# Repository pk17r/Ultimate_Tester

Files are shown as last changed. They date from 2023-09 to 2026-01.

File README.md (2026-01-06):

# Ultimate Tester!

Pocket Sized Component Tester + Variable Power Source + Accurate Power Monitor in Arduino Uno Form Factor

Full Blog Entry & Details:
https://pk17r.wordpress.com/2023/12/18/ultimate-tester-component-tester-lipo-charge-boost-protect/

Updated Ultimate Tester Schematics: https://github.com/pk17r/Ultimate_Tester/blob/prash/ComponentTester-1.54m/UltimateTester_PCB/UltimateTester_v1_with_mods.pdf

<br>

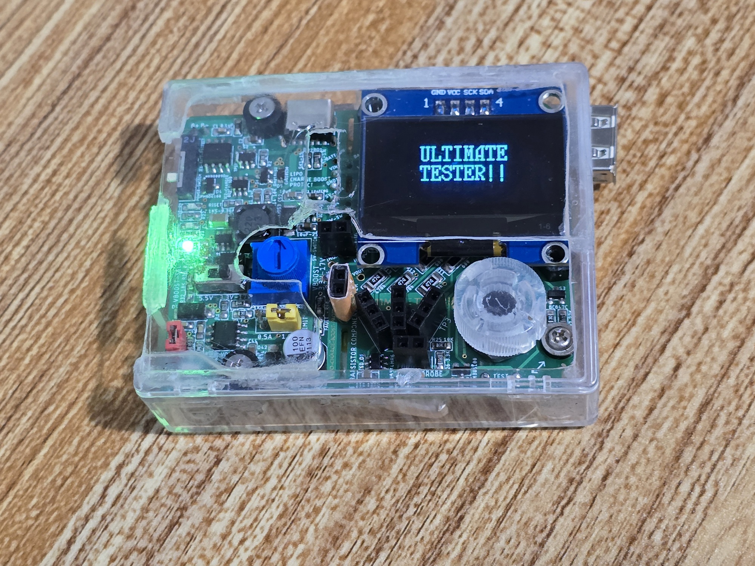
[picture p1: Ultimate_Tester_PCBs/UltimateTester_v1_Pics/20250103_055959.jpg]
Component Tester + Power Supply and Power Monitor


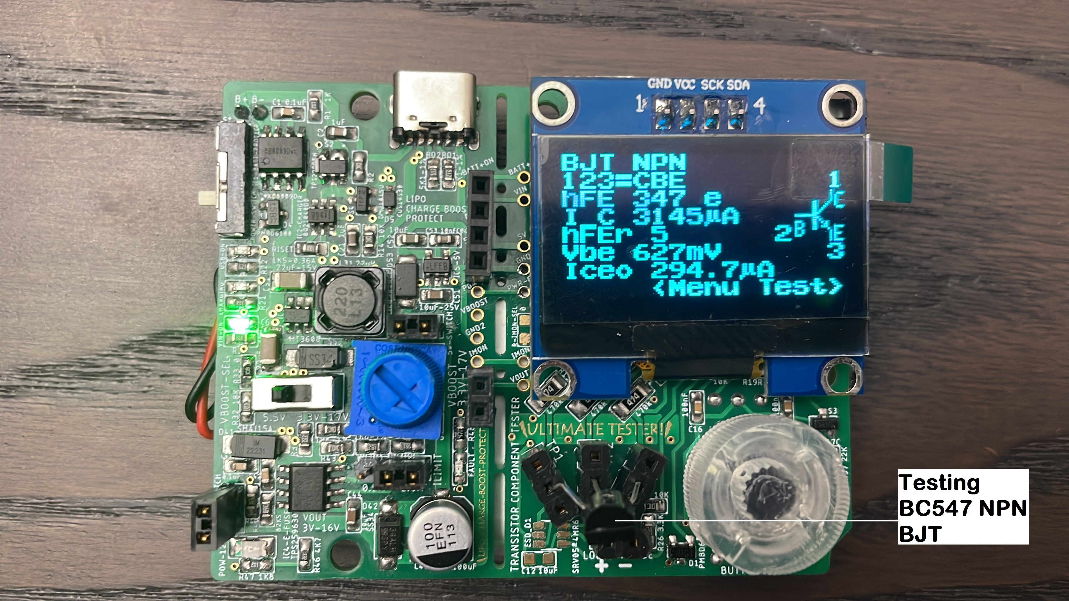
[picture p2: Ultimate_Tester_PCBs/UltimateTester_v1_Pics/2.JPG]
Component Tester


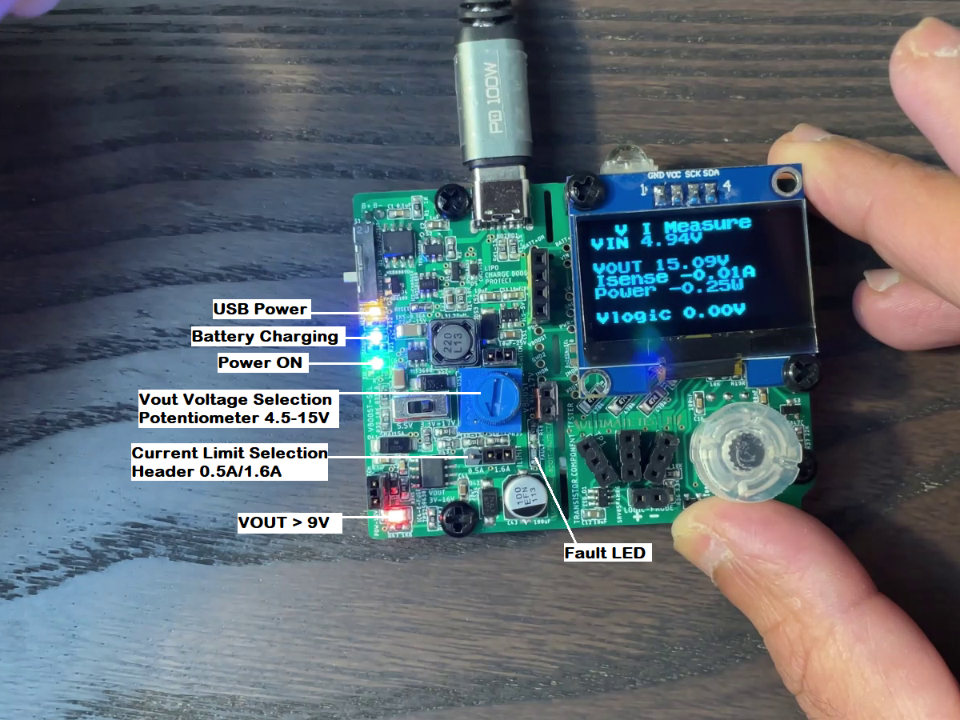
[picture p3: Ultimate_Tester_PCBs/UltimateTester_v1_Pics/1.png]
LiPo Charge Boost Protect / USB-C Power Supply


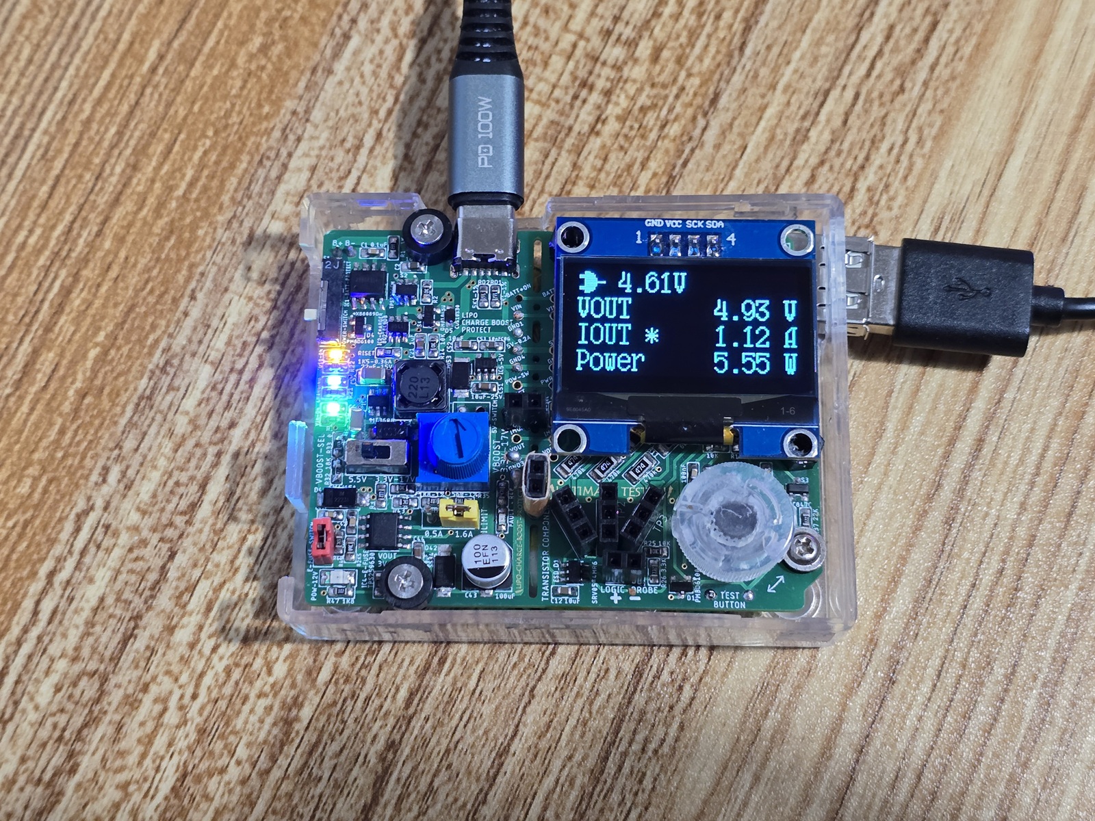
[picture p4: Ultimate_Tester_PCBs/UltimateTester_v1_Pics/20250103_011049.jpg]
Accurate INA226 Power Monitor with External Power Supply


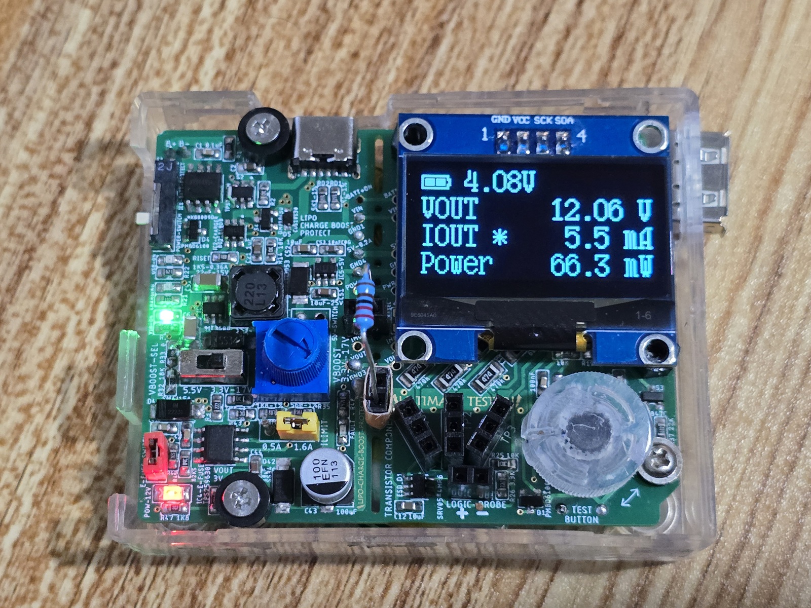
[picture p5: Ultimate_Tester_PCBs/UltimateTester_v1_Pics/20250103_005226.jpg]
Accurate INA226 Power Monitor with Internal Power Supply


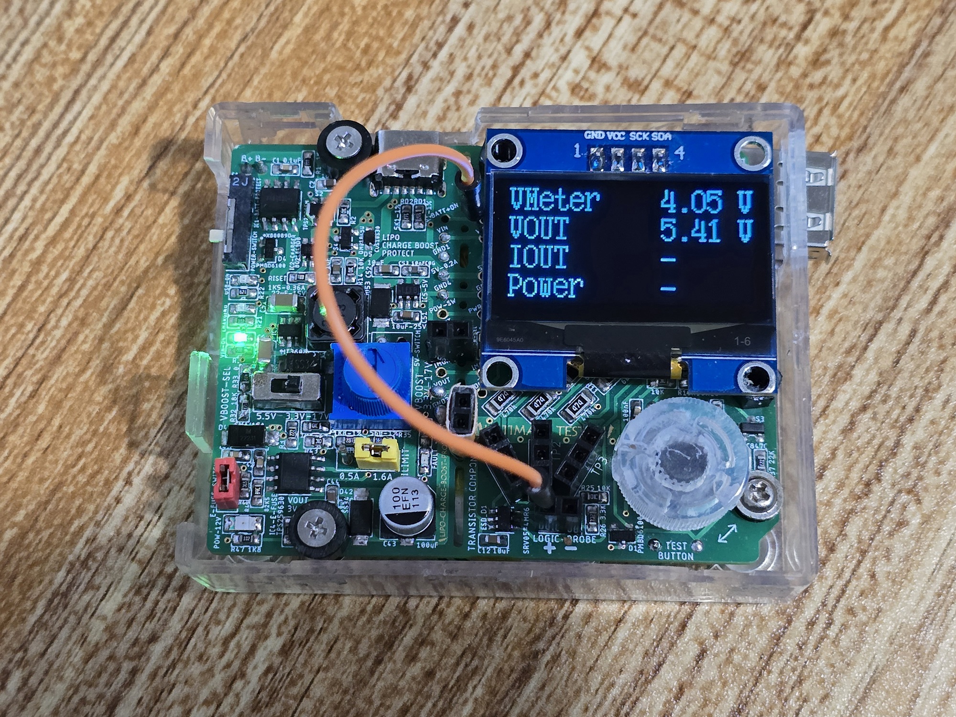
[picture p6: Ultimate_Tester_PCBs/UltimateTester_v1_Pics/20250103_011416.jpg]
Accurate INA226 Power Monitor along with Voltmeter


Current Accuracy:<br>
Test 1: Low Current: 2.4mA<br>
<table>
  <tr>
    <th></th>
    <th>Measured</th>
    <th>Ground Truth</th>
    <th>Error</th>
  </tr>
  <tr>
    <td>Current</td>
    <td>2.4mA</td>
    <td>2.39+0.6%=2.40mA</td>
    <td>0%</td>
  </tr>
  <tr>
    <td>Voltage</td>
    <td>5.17V</td>
    <td>5.164+0.1%=5.17V</td>
    <td>0%</td>
  </tr>
</table>

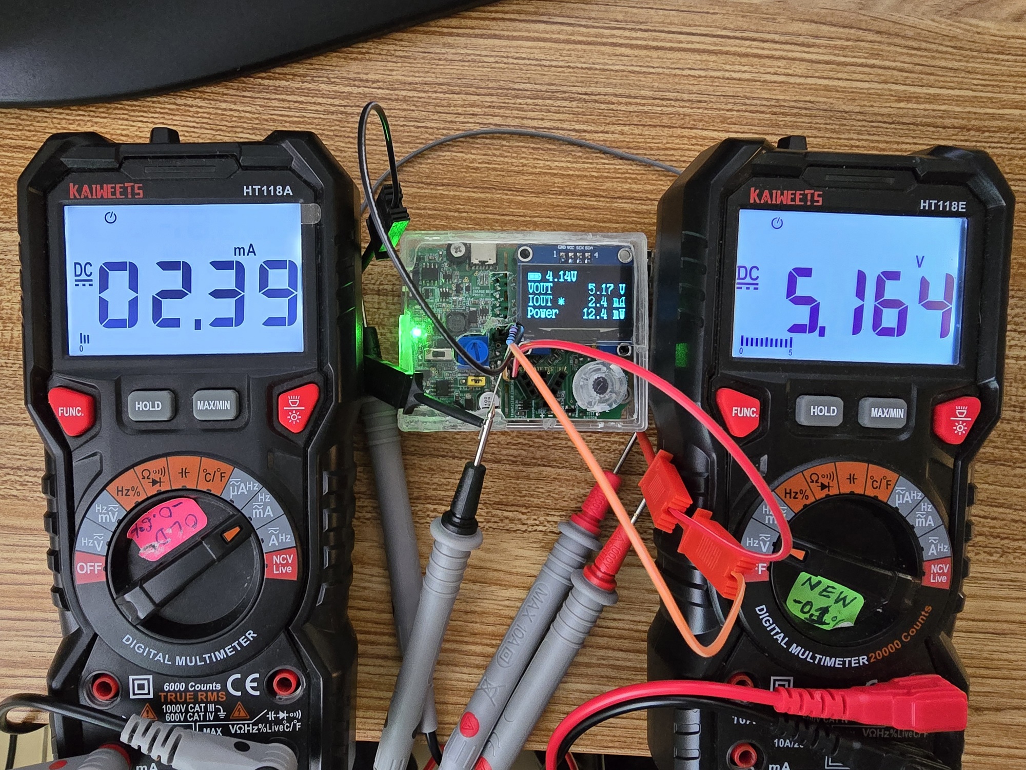
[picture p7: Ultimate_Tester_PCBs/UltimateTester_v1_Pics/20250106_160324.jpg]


Test 2: Medium Current: 209.3mA<br>
<table>
  <tr>
    <th></th>
    <th>Measured</th>
    <th>Ground Truth</th>
    <th>Error</th>
  </tr>
  <tr>
    <td>Current</td>
    <td>209.3mA</td>
    <td>207.3+0.6%=208.5mA</td>
    <td>+0.4%</td>
  </tr>
  <tr>
    <td>Voltage</td>
    <td>5.14V</td>
    <td>5.135+0.1%=5.14V</td>
    <td>0%</td>
  </tr>
</table>

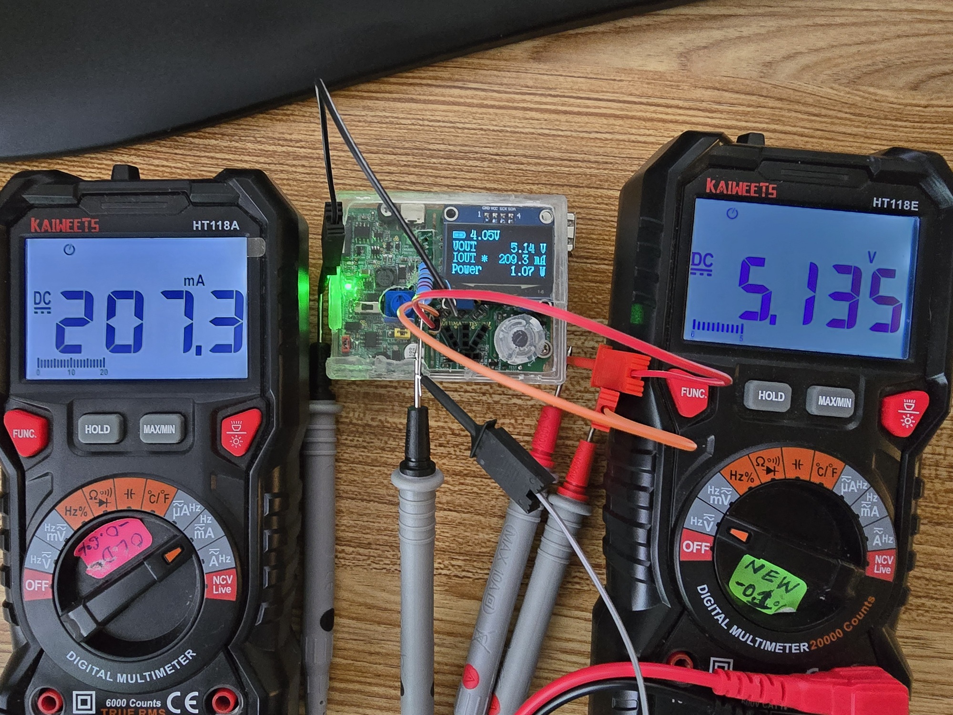
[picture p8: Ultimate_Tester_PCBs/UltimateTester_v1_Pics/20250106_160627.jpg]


Test 3: High Current: 1.07A<br>
<table>
  <tr>
    <th></th>
    <th>Measured</th>
    <th>Ground Truth</th>
    <th>Error</th>
  </tr>
  <tr><td>Current</td><td>1.07mA</td><td>1.056+0.6%=1.06A</td><td>+0.9%</td></tr>
  <tr><td>Voltage</td><td>4.95V </td><td>4.928+0.1%=4.93V</td><td>+0.4%</td></tr>
</table>

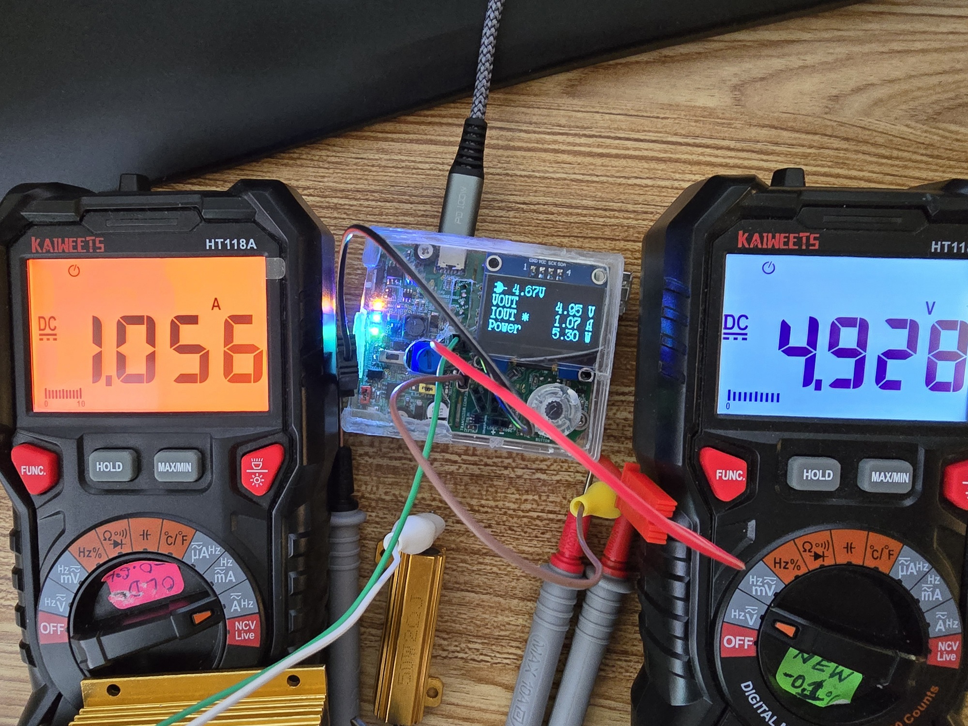
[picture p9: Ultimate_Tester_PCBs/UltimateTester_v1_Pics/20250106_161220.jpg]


Test 4: Different Voltages<br>
<table>
  <tr>
    <th>Measured</th>
    <th>Ground Truth</th>
    <th>Error</th>
  </tr>
  <tr><td>3.93V</td><td>  3.930+0.1%=3.93V</td><td>    0%</td></tr>
  <tr><td>9.05V</td><td>  9.051+0.1%=9.02V</td><td>   +0.3%</td></tr>
  <tr><td>12.04V</td><td>12.022+0.1%=12.03V</td><td>+0.1%</td></tr>
  <tr><td>15.15V</td><td>15.136+0.1%=15.15V</td><td>0%</td></tr>
</table>

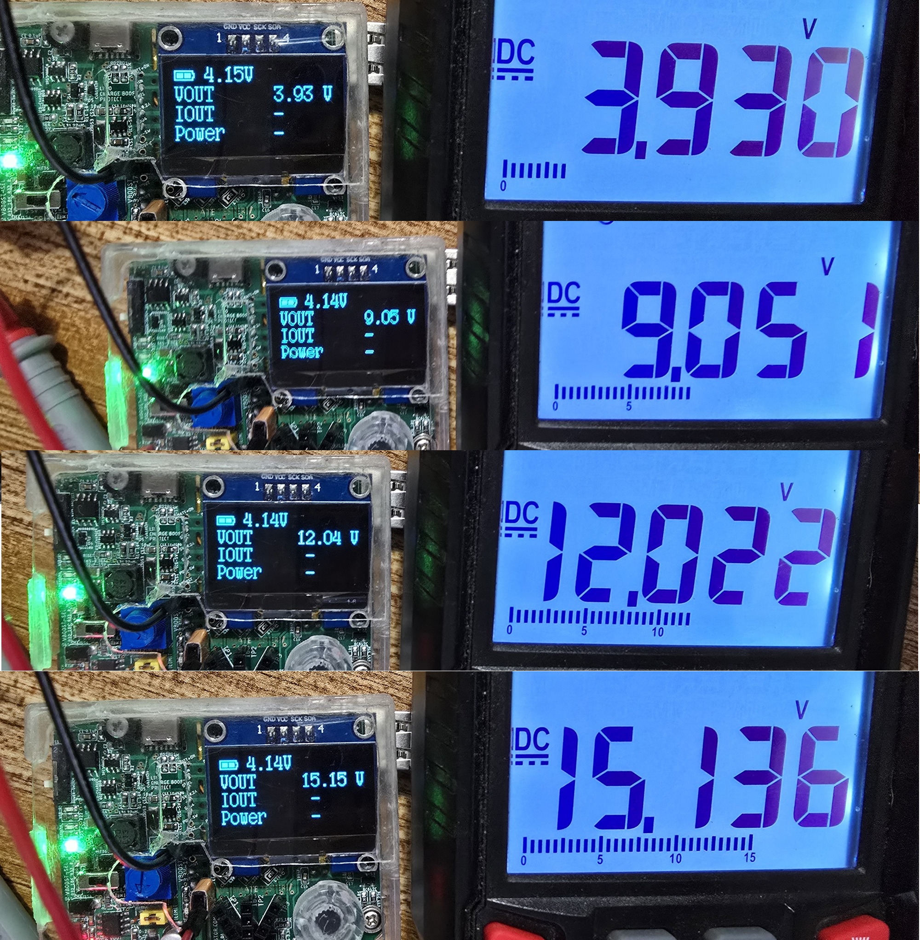
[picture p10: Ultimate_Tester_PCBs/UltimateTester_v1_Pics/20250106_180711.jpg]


<br>

# Transistortester Warehouse

The Transistortester is a device for identifying and checking electronic components.
It also offers additional functionality like a PWM signal generator for example.
And it's OSHW.

This repo is meant to provide a convenient way to download firmware packages,
documentation files, PCB files and more. Therefore it's structured differently
from the main repo.

The project's webpage is https://www.mikrocontroller.net/articles/AVR_Transistortester
and the main repo is https://github.com/kubi48/TransistorTester-source.

BTW, all the inexpensive Transistortesters sold on your favourite shopping platform
are based on this project and can be updated with the original OSHW firmware versions.

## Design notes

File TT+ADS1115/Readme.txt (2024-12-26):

A stripped down version of the ORIGINAL Markus Frejek's code.
ATTENTION : this is NOT a fully working code.

Uses ADS1115 as ADC instead of internal one.
tested in PROTEUS OKK

* some measurement are omitted:
	- resistance. 
	- capacitance.
	- base-emitter voltage for bipolar transistors. 
	- gate capacitance for enhancement MOSFETS. 

* No automatic shut OFF
* No custom chars.
* No battery test.
* The watchdog is not used to reset the chip when the program hangs.

The file tt.hex is the Flash. 
The file eep.bin is the EEPROM contents. Please do not forget this in simulation and real device !

ATMEGA328 @ 8MHz (internal RC oscillator).

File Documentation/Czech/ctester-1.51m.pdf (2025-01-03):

? =

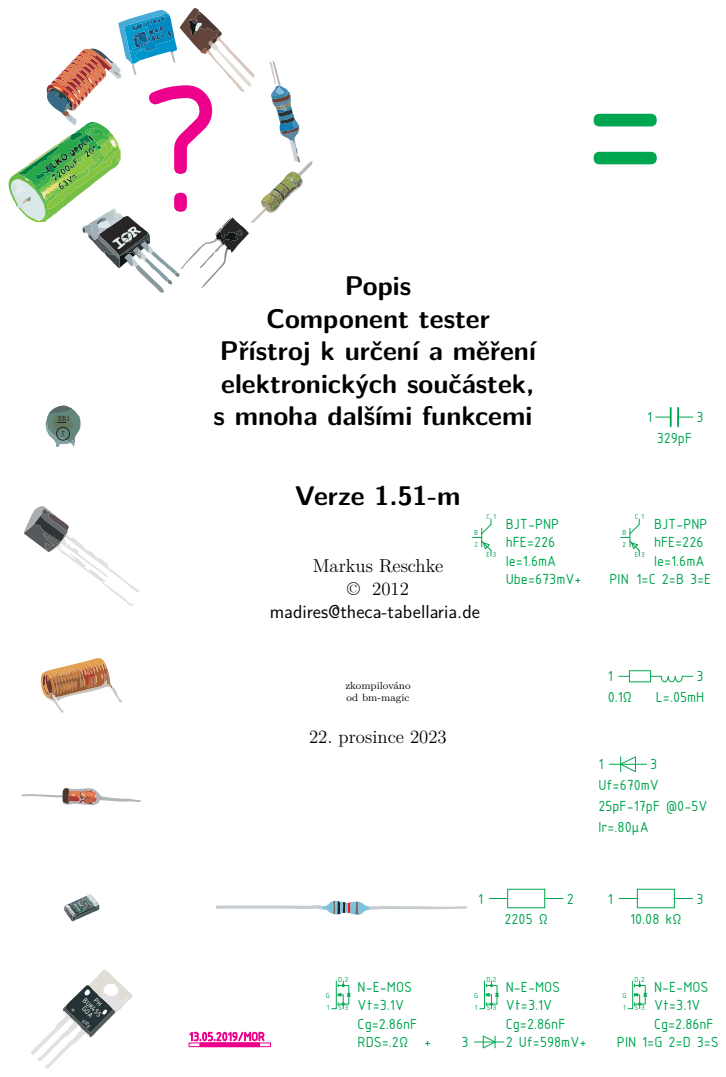
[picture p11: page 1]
13.05.2019/MOR; N-E-MOS Vt=3.1V Cg=2.86nF; RDS=.2; BJT-PNP hFE=226 Ie=1.6mA Ube=673mV+; BJT-PNP hFE=226 Ie=1.6mA PIN 1=C 2=B 3=E; N-E-MOS Vt=3.1V Cg=2.86nF PIN 1=G 2=D 3=S; S3 BUK455; PH GOA; Popis; Verze 1.51-m; Markus Reschke © 2012

Component tester
Přístroj k určení a měření
elektronických součástek,
s mnoha dalšími funkcemi

madires@theca-tabellaria.de

zkompilováno
od bm-magic
22. prosince 2023

## Obsah

1 O tomto Ctesteru | 8
1.1 Úvod | | 8
1.2 Bezpečnost | | 8
1.3 Licence | | 8
1.3.1 | Dostatečné licenční upozornění | | 8
1.4 Rozdíly ke k-verzi | | 9
1.5 Zdrojový kód | | 9
1.6 Podporovaná hardware | | 10
1.7 Podporovaní hardwardwerové možnosti | | 10
1.7.1 | Obsluha | | 10
1.7.2 | Vylepšení | | 10
1.7.3 | Doplňkové zkoušky a měření | | 10
1.8 Úprava zdrojového kódu | | 10
2 Hardware | | 11
2.1 Hardwarové možnosti | | 11
2.2 A samozřejmě softwarové možnosti | | 11
2.3 Dostupné jazyky | | 12
2.4 Konfigurace | | 12
2.5 Sběrnice & rozhraní | | 12
2.5.1 | I2C/SPI | | 12
2.5.2 | Serielní TTL Interface | | 12
2.5.3 | One Wire | | 13
2.6 LCD moduly | | 13
2.6.1 | Znakové sady a symboly | | 14
2.6.2 | HD44780 | | 14
2.6.3 | ILI9163 | | 14
2.6.4 | ILI9341/ILI9342 | | 15
2.6.5 | ILI9481 | | 16
2.6.6 | ILI9486 | | 16
2.6.7 | ILI9488 | | 16
2.6.8 | PCD8544 | | 17
2.6.9 | PCF8814 | | 17
2.6.10 SH1106 | | 17
2.6.11 SSD1306 | | 18
2.6.12 ST7036 | | 18
2.6.13 ST7565R | | 19
2.6.14 ST7735 | | 19
2.6.15 ST7920 | | 19
2.6.16 STE2007/HX1230 | | 19
2.6.17 VT100 Terminal | | 20
2.7 Tlačítka a ovládání | | 20
2.7.1 | Testovací tlačítko | | 20

2.7.2 | Rotační kodér (Hardwarová možnost) | | 20
2.7.3 | (Vice/méně tlačítek) | | 20
2.7.4 | Dotyková obrazovka (Hardwarová možnost) | | 20
2.7.5 | Uživatelské rozhraní | | 21
2.7.6 | Bzučák (Hardwarová možnost) | | 22
2.7.7 | Komunikace s PC | | 22
2.7.8 | Seriový výstup | | 22
2.7.9 | Automatisierung | | 22
2.7.10 Výstup přes VT100 | | 22
3 Obsluha | 23
3.0.1 | Zapnutí | | 23
3.0.2 | Hledání komponentů | | 23
3.0.3 | Monitorování baterie | | 23
3.0.4 | Vypínání, | | 23
3.1 Výběrové menu | | 24
3.1.1 | PWM-Generátor | | 24
3.1.2 | Jednoduchý PWM | | 24
3.1.3 | Rozšířený PWM | | 24
3.1.4 | Obdélníkový signální generátor | | 24
3.1.5 | Zjištění Zenerového napětí (hardwarová úprava) | | 25
3.1.6 | Logický tester (hardwarová úprava) | | 25
3.1.7 | tester kontinuity (hardwarová úprava) | | 26
3.1.8 | ESR-Tool | | 26
3.1.9 | Unikající proud kondenzátoru | | 26
3.1.10 R/C/L Monitory | | 26
3.1.11 L/C-Měřič (hardwarová úprava) | | 27
3.1.12 Čítač kmitočtů (hardwarová úprava) | | 27
3.1.13 Jednoduchý čítač | | 27
3.1.14 Rozšířený čítač | | 27
3.1.15 Kroužkový tester (hardwarová úprava) | | | 28
3.1.16 Počitadlo událostí (s hardwarovou úpravou) | | 28
3.1.17 Rotační kodér | | 29
3.1.18 Kontrast | | 29
3.1.19 Detektor/Dekodér pro IR dálkové ovládání | | 29
3.1.20 IR přijímací modul na testovacích pinech | | 29
3.1.21 IR dálkové ovládání | | 30
3.1.22 Test optických spojek | | 31
3.1.23 Test fotodiod | | 31
3.1.24 Test servopohonů pro modely | | | 32
3.1.25 OneWire skenování | | 32
3.1.26 Snímač teploty DS18B20, DS18S20 | | 32
3.1.27 DHTxx senzory | | 33
3.1.28 Převodník termočlánků | | 33
3.1.29 Svítilna | | 33
3.1.30 Autotest | | 33
3.1.31 Samočinné nastavení | | 34
3.1.32 Uschovat/Použít | | 34
3.1.33 Ukázat hodnoty | | 34
3.1.34 Znaková sada/symboly | | 35
3.1.35 Vypnout | | 35
3.1.36 Konec | | 35
4 Detaily měření | 36
4.1 Odpory | | 36

4.2 Kondenzátory | | 36
4.3 tlumivky | | 37
4.4 Vybití součástek | | 37
4.5 ADC převzorkování | | 37
4.6 Zobrazení výsledků | | 37
4.7 Dodatečné pokyny | | 38
4.8 užitečné odkazy | | 40
4.9 Změny firmwaru | | 40
5 Dálkové ovládání | 41
5.1 Příkazy dálkového ovládání | | 41
5.1.1 | ERR | | 41
5.1.2 | OK | | 41
5.1.3 | N/A | | 41
5.2 Basiskommandos | | 41
5.2.1 | VER | | 41
5.2.2 | OFF | | 41
5.3 Testkommandos | | 41
5.3.1 | PROBE | | 41
5.3.2 | COMP | | 41
5.3.3 | MSG | | 41
5.3.4 | QTY | | 41
5.3.5 | NEXT | | 41
5.3.6 | TYPE | | 41
5.3.7 | HINT | | 42
5.3.8 | MHINT | | 42
5.3.9 | PIN | | 42
5.3.10 R | | 42
5.3.11 C | | 42
5.3.12 L | | 42
5.3.13 ESR | | 42
5.3.14 I_l | | 43
5.3.15 V_l | | 43
5.3.16 V_F | | 43
5.3.17 V_F2 | | 43
5.3.18 C_D | | 43
5.3.19 I_R | | 43
5.3.20 R_BE | | 43
5.3.21 h_FE | | 43
5.3.22 h_FE_r | | 43
5.3.23 I_C | | 43
5.3.24 I_E | | 43
5.3.25 V_BE | | 43
5.3.26 I_CEO | | 43
5.3.27 V_th | | 43
5.3.28 C_GS | | 44
5.3.29 R_DS | | 44
5.3.30 V_GS_off | | 44
5.3.31 I_DSS | | 44
5.3.32 C_GE | | 44
5.3.33 V_GT | | 44
5.3.34 V_T | | 44
5.3.35 R_BB | | 44
5.3.36 V_Z | | 44
5.3.37 V_F_clamp | | 44

6 Programový kód | 45
6.1 Makefile | | 45
6.1.1 | MCU typ | | 45
6.1.2 | Taktová frekvence MCU | | 45
6.1.3 | Typ oscilátoru | | 45
6.1.4 | Avrdude typ MCU | | 46
6.1.5 | Avrdude ISP programátor | | 46
6.2 config.h | | 47
6.2.1 | Hardwarová obsluha | | 47
6.2.2 | Možnosti softwaru | | 50
6.2.3 | Řešení obcházení pro některé testery | | 53
6.2.4 | Řešení pro některá IDE | | 53
6.2.5 | uživatelské rozhraní | | 54
6.2.6 | Správa napájení | | 57
6.2.7 | Nastavení a kompenzace měření | | 57
6.2.8 | R&D - určeno pro vývojáře firmwaru | | 59
6.2.9 | Busse | | 60
6.3 Config_328.h | | 61
6.3.1 | LCD moduly | | 61
6.3.2 | Rozložení portů a pinů | | 61
6.3.3 | Busse | | 63
6.4 Config_644.h | | 64
6.4.1 | LCD moduly | | 64
6.4.2 | Rozložení portů a pinů | | 64
6.4.3 | Busse | | 67
6.5 Config_1280.h | | 68
6.5.1 | LCD moduly | | 68
6.5.2 | Rozložení portů a pinů | | 68
6.5.3 | Busse | | 71
7 kolekce nastavení | 72
7.1 Arduino Nano, Uno nebo Mega 2560 | | 72
7.2 DIY Kit „AY-AT“ platí také pro GM_328A | | 73
7.3 BSide ESR02 | | 74
7.4 Fish8840 TFT | | 75
7.5 GM328 !pozor! né GM328A | | 75
7.6 Hiland M644 | | 76
7.7 M12864 DIY Transistor Tester | | 77
7.8 MK-328, ATmega328, 8 MHz Takt; ST7565 display s (Bit-Bang-SPI | | | 78
7.9 T3/T4,ATmega328, 8 MHz Takt; ST7565 display s (Bit-Bang-SPI | | 78
7.10 Multifunktionstester LCR-T5 | | 80
7.11 Multifunktionstester TC-1 a rodina (T7) s ATmega324/644 | | 80
7.12 Multifunktionstester TC-2 s ATmega324/644;16MHz clock | | | 83
7.13 Multifunktionstester T7 s ATmega328, 16-MHz-Takt | | | 83
7.14 Arduino MEGA zapojení | | 85
8 Programování testeru Componentů | 86
8.1 Konfigurace testeru | | 86
8.2 Programování testeru | | 86
8.3 Operační system Linux | | 86
8.4 Použití s Linuxem | | 87
8.5 Instalace programových balíčků | | 87
8.6 Stáhnutí zdrojů | | 87
8.7 Používání rozhraní | | 87
8.8 Členství ve skupině | | 88

8.9 pracovní prostředí | | 88
8.10 Přeložení Firmware | | 89
9 Postup verzí | 90
9.1 v1.51m 2023-12 | | 90
9.2 v1.50m 2023-8 | | 90
9.3 v1.49m 2023-04 | | 90
9.4 v1.48m 2022-12 | | 91
9.5 v1.47m 2022-07 | | 91
9.6 v1.46m 2022-04 | | 92
9.7 v1.45m 2021-12 | | 93
9.8 v1.44m 2021-08 | | 93
9.9 v1.43m 2021-03 | | 93
9.10 v1.42m 2020-12 | | 94
9.11 v1.41m 2020-09 | | 94
9.12 v1.40m 2020-06 | | 95
9.13 v1.39m 2020-03 | | 96
9.14 v1.38m 2019-12 | | 96
9.15 v1.37m 2019-09 | | 96
9.16 v1.36m 2019-05 | | 97
9.17 v1.35m 2019-02 | | 97
9.18 v1.34m 2018-10 | | 97
9.19 v1.33m 2018-05 | | 98
9.20 v1.32m 2018-02 | | 98
9.21 v1.31m 2017-12 | | 98
9.22 v1.30m 2017-10 | | 98
9.23 v1.29m 2017-07 | | 99
9.24 v1.28m 2017-04 | | 99
9.25 v1.27m 2017-02 | | 99
9.26 v1.26m 2016-12 | | 99
9.27 v1.25m 2016-09 | 100
9.28 v1.24m 2016-08 | 100
9.29 v1.23m 2016-07 | 100
9.30 v1.22m 2016-03 | 100
9.31 v1.21m 2016-01 | 100
9.32 v1.20m 2015-12 | 100
9.33 v1.19m 2015-11 | 101
9.34 v1.18m 2015-07 | 101
9.35 v1.17m 2015-02 | 101
9.36 v1.16m 2014-09 | 101
9.37 v1.15m 2014-09 | 101
9.38 v1.14m 2014-08 | 101
9.39 v1.13m 2014-07 | 102
9.40 v1.12m 2014-03 | 102
9.41 v1.11m 2014-03 | 102
9.42 v1.10m 2013-10 | 102
9.43 v1.09m 2013-07 | 102
9.44 v1.08m 2013-07 | 103
9.45 v1.07m 2013-06 | 103
9.46 v1.06m 2013-03 | 103
9.47 v1.05m 2012-11 | 103
9.48 v1.04m 2012-11 | 103
9.49 v1.03m 2012-11 | 103
9.50 v1.02m 2012-11 | 103
9.51 v1.01m 2012-10 | 103

9.52 v1.00m 2012-09 | 104
9.53 v0.99m 2012-09 | 104

Kapitola 1 | O tomto Ctesteru

### 1.1. Úvod

Transistor Tester je založen na projektu Markuse Frejka [1] a [2] s pokračováním Karl-Heinze Kübbelerem [3] a [4].
Componenten tester je alternativní firmware pro současný testovací obvod Karl-Heinze a nabízí některé změny uživatelského rozhraní a postupy měření a testování.
Zatímco firmware Karl-Heinze je oficiální verze a podporuje starší typy MCU ATmega, slouží tato verse k vyzkoušení a testování nových nápadů.
Je omezena na ATmegas s minimálně 32kB Flash.
Primární jazyky pro tuto versi jsou angličtina a němčina, ale lze snadno doplnit další jazyky.

Poznámka: Proveď vlastní nastavení u zcela nových testerů nebo firmwaru aktualizace. Nebo při použití jiných měřicích kabelů.

### 1.2. Bezpeˇcnost

Component Tester není multimetr!
Je to jednoduchý tester komponentů, který dokáže měřit různé věci.
Vstupy nejsou chráněny a budou poškozeny napětím nad 5V.
Nepoužívej tester pro obvody v provozu, ale pouze pro jednotlivé komponenty! U kondenzátorů se ujisti, že jsou vybité před zapnutím testeru.
Používáš na vlastní nebezpečí!

### 1.3. Licence

Autor původní verze má pouze dvě licenční podmínky. Za prvé je projekt otevřený zdrojový kód,
a za druhé by měli komerční uživatelé kontaktovat autora.

Bohužel, ani Karl-Heinz, ani já jsme se dosud k autorovi nedostali.
K vyřešení problému s nedostačující “open source“ licencí, jsem 1.1.2016 vybral standardní licenci pro otevřený zdroj, poté co měl původní autor dost času oznámit svá přání k licenci.

Vzhledem k tomu že tato verze firmwaru je zcela nová verze, který zabírá jen několik nápadů původního firmwaru, ale nesdílí žádný kód, by to mělo být odůvodněno.

Licencováno v rámci EUPL V.1.2

### 1.3.1. Dostateˇcné licenˇcní upozornˇení

Názvy produktů nebo společností mohou být registrované ochranné známky příslušných vlastníků.

### 1.4. Rozdíly ke k-verzi

Karl-Heinz napsal k testeru opravdu dobrou dokumentaci. [17] Určitě si ji přečti! Proto popisuji pouze hlavní rozdíly k firmwaru k:
- uživatelské rozhraní
Nepropadej v panice! ;-)
+ Dotykový displej
+ Automatizace (příkazy pro dálkové ovládání)
+ dvě sady hodnot nastavení
- Adaptivní funkce vybíjení - Měření odporu
+ další metoda pro odpory <10 Ω (místo měření ESR)
- Měření kapacity + od 5pF
+ další metoda pro kondenzátory mezi 4,7µF a 47µF
+ další metoda korekce / kompenzace
- Žádný SamplingADC () pro velmi nízké kapacity nebo indukčnosti
- diody
+ Logika rozpoznávání
- bipolární tranzistory
+ V _f je interpolováno pro praktické zkušební proudy
+ Detekce germaniových tranzistorů s vyšším svodovým proudem + Detekce Schottkyho tranzistorů
JFET
+ Detekce JFET s velmi nízkými I_DSS
- TRIAC
+ Detekce MT1 a MT2
- detektor / dekodér pro IR dálkové ovladače
- IR dálkové ovládání
- Test optokoplerů
- Test serva na výrobu modelů
- OneWire (DS18B20, DS18S20) Teplotní senzory
- Řada sensorů (DHTxx)
- Počítadlo událostí
- Bzučákový tester (LOPT/FBT-Tester; FBT = flyback transformer
- Logický tester
- Zkoušečka kontinuity
- Převodník termočlánků MAX6675/MAX31855
- svítilna / univerzální spínaný výstup
- Strukturovaný zdrojový kód
- Jednoduché rámce pro displeje a datové sběrnice
- A další, na které si právě nemůžu vzpomenout.

Další podrobnosti najdeš v následujících sekcích.

### 1.5. Zdrojový kód

První m-firmware byla založena na zdrojovém kódu od Karla Heinze. Hodně bylo vymazáno, komentáře, proměnné přejmenovány, restrukturalizované funkce, velké funkce rozděleny na několik malých a více. Pak jsem pokračoval ve vývoji m-firmwaru jako nezávislou verzi. Existují jednoduché rámce pro displej a přišly k tomu i nové rozhraní.
Doufám, že zdrojový kód je snadno čitelný a srozumitelný.
Aktuální firmware najdeš na následujících webech:
[5] https://github.com/madires/Transistortester-Warehouse
[6] https://github.com/kubi48/TransistorTester-source/tree/master/Markus
[7] https://github.com/Mikrocontroller-net/transistortester/tree/master/Software/Markus

### 1.6. Podporovaná hardware

Firmware běží na všech testerech, které poskytují základní obvody jako u Karl-Heinze Dokumentace je kompatibilní a používá jednu z následujících MCU:
- ATmega 328 | config_328.h
- ATmega 324/644/1284 | config_644.h
- ATmega 640/1280/2560 config_1280.h
Je možné upravit různá přiřazení pinů. Jako displej je možné používat textové nebo grafické displeje (monochromatické nebo barevné).
Podporované řadiče najdeš v kapitole 2.6 „LCD moduly“ od stránky 47.

### 1.7. Podporovaní hardwardwerové možnosti

### 1.7.1. Obsluha

- rotační kodér
- další klíče (více / méně)
- Dotyková obrazovka
- sériové rozhraní (TTL, RS232, sériový adaptér USB)

### 1.7.2. Vylepšení

- externí referenční napětí 2.5V
- pevný nastavovací kondenzátor
- ochranné relé pro vybíjení kondenzátorů

### 1.7.3. Doplˇnkové zkoušky a mˇeˇrení

- Zenerův test / měření externího napětí <50V
- jednoduchý čítač kmitočtu
- čítač rozšířené frekvence
s předzesilovačem a křemenným oscilátorem pro nízké a vysoké frekvence
- pevný IR-RC přijímač
- LC metr
- Kroužkový tester (podle Boba Parkera)
- Logický tester
- Převodník termočlánků MAX6675/MAX31855
- svítilna

### 1.8. Úprava zdrojového kódu

Nejprve bys měl upravit Makefile viz kapitola 6.1 na stránce 45 a zde upravit nastavení MCU model, frekvenci, typ oscilátoru a nastavení programovacího adaptéru.

V config.h viz kapitolu 6.2 od stránky 47 můžeš nastavit možnosti operace a nabídky,
Zde si vybereš hardwarové a softwarové možnosti, jazyk provozu a v případě potřeby změň výchozí hodnoty.

A nakonec v config_<MCU>.h globální konfiguraci MCU například přiřazení pinů a zobrazení které se líší v závislosti na vestavěném MCU. Detaily v kapitole 6.5 od stránky 68. Soubory config<MCU>.h platí pro náslaedující MCU:
- ATmega 328 | config_328.h
- ATmega 324/644/1284 | config_644.h
- ATmega 640/1280/2560 config_1280.h
V kapitole 7, “Kolekce nastavení” najdeš, od stránky 47, nastavení pro různé verze testerů. Pokud tam tvůj tester není, pošli tvé nastavení e-mailem autorovi [8] pro pomoc ostatním uživatelům.
Všechna nastavení a hodnoty jsou vysvětleny v samotném souboru,

Jak Firmware přeložit se dozvíš v oddílu 8.10 na straně 89.

Kapitola 2 | Hardware

### 2.1. Hardwarové možnosti

- další klávesy nebo možnosti vstupu
- Rotační kodér
- Více / méně tlačítek
- Dotyková obrazovka
- Externí referenční napětí 2.5V
- Ochranné relé pro vybití kondenzátoru
- Měření zenerových diod (převodník DC-DC)
- Čítač kmitočtů (jednoduchá a rozšířená verze)
- Čítač událostí
- LC Měřič
- Klingeltester (LOPT/FBT-Tester); LOPT = line output transformer
- Test IR dálkového ovládání (pevný IR přijímací modul)
- Pevný kondenzátor pro samočinné nastavení kompenzace napětí
- Sběrnice SPI (bit-bang a hardware)
- Sběrnice I2C (bit-bang a hardware)
- TTL Serial (Bit-Bang and Hardware)
- OneWire Bus (Bit-Bang)

Externí referenční napětí 2,5 V by mělo být použito, pouze pokud je to faktor 10
přesnější než regulátor napětí. Jinak by to výsledky spíše zhoršilo, než by se zlepšilo.
Pokud máš MCP1702 s typickou přesností 0,4% jako regulátor napětí opravdu nepotřebuješ další referenční napětí.

### 2.2. A samozˇrejmˇe softwarové možnosti

- PWM generátor (2 varianty)
- Měření indukčnosti
- ESR měření a ESR v obvodu
- Test rotačních kodérů
- Generátor čtvercové vlny (vyžaduje další tlačítka)
- Test dálkového ovládání IR (modul IR přijímače na testovacích pinech)
- IR dálkové ovládání (IR LED s tranzistorem ovladačem)
- Test optočlenů
- Test serva pro výrobu modelů (potřebuje další klávesy, displej> 2 řádky)
- OneWire-Detekce
- Detekce UJT
- Test těsnosti kondenzátoru
- Monitorování R/L/C
- Teplotní senzory DS18B20, DS18S20
- Řada senzorů DHTxx k měření teploty a vlhkosti
- Barevné kódování zkušebních pinů (vyžaduje barevné zobrazení)
- Výstup nalezených komponent paralelně přes TTL seriál, například na PC
- Příkazy pro dálkové ovládání pomocí TTL seriálu.
- Výstup reverzního hFE (C&E obráceny) pro bipolární tranzistory
z těch nabídek vyber podle svých představ a omezených zdrojů MCU, RAM, EEPROM a flash paměťi.

### 2.3. Dostupné jazyky

- brazilská portugalština | od wandows@EEVblog
- dánština - potřebuje malé změny písma | od glenndk@mikrocontroller.net
- němčina
- angličtina
- francouzština | od moimem@EEVblog
- italština | | od Gino_09@EEVblog
- polština | | od Szpila
- rumunština | od Dumidan@EEVblog
- ruština | - Znaková sada s azbukou; systém Windows 1251 | od indman@EEVblog
- ruština 2 - Znaková sada s azbukou; systém Windows 1251 | od hapless@EEVblog
- španělština | od pepe10000@EEVblog
- čeština | - Znaková sada založená na systému ISO 8859-1 | od Kapa
- čeština 2 - Znaková sada založená na systému ISO 8859-2 | od Bohu

Pokud dáváš přednost čárce místo desetinné tečky, existuje předvolba (Standart: Punkt).

### 2.4. Konfigurace

Tvoje MCU a programátor se nastavují v Makefile . . . | kapitola 6.1 od strany 45.
Tvé možnosti si můžeš vybrat v config.h . . . | kapitola 6.2 od strany 47.
Specifická nastavení, jako jsou přiřazení pinů a zobrazení, se liší v závislosti od MCU v souborech:
- ATmega 328 | v config_328.h
- ATmega 324/644/1284 | v config_644.h
- ATmega 640/1280/2560 | v config_1280.h
Detaily si můžeš přečíst v . . . | kapitole 6.5 od strany 68.
Pokud bude firmware příliš velký, zkus znovu méně důležité možnosti vypnout.

### 2.5. Sbˇernice & rozhraní

### 2.5.1. I2C/SPI Některé LCD moduly a další komponenty vyžadují na MCU I2C nebo

SPI rozhraní. Firmware má proto ovladače pro oba systémy. Pro podporu různých obvodů mají ovladače sběrnic jeden Bit-Bang a jeden hardwarový režim. V režimu Bit-Bang mohou jakýkoli IO Piny používat stejný port, zatímco hardwarový režim používá pevně předepsané MCU Piny Busu. Nevýhodou Bit-Bang režimu je jeho pomalá rychlost. Hardwarový režim je hodně rychlejší. Ten rozdíl můžeš lehce pozorovat u barevných LCD modulů s vysokým rozlišením.
Pro testery s ATmega 328 je téměř vždy vyžadován Bit-Bang režim kvůli zapojení. ATmega 324/644/1284 má více I/O pinů, kromě toho dovoluje změněné zapojení používat pevné kolíky sběrnice pro hardwarový režim.
Jelikož je SPI nebo I2C primárně používáno LCD modulem, můžeš obě rozhraní konfigurovat přímo v sekci pro moduly LCD v config<MCU>.h stránka 47. Alternativně můžeš aktivovat I2C nebo SPI v config.h na stránce 60 a porty & piny upravit v config<MCU>.
(Hledej I2C_PORT nebo SPI_PORT) na stránce 71.
Pokud je ke SPI sběrnici připojeno několik integrovaných obvodů, musí být každý z nich řízen svým vlastním /CS signálem. Pouze v případě jednoho IC na SPI sběrnici, lze tento /CS signál trvale spojit se zemí.
Poznámka k bit-bang SPI:
- Pokud je sběrnice SPI pro zobrazovací modul při vysoké taktovací frekvenci MCU skutečně příliš rychlá, přidej v konfiguraci displeje volbu "SPI_SLOWDOWN". v config-<MCU>.h nebo ji aktivuj v config.h.
2.5.2. Serielní TTL Interface Tester může mít také volitelné sériové rozhraní TTL. Používá se tato pro komunikaci s PC, mělo by to být kombinováno s USB na TTL převodníkem nebo s modulem ovladače RS-232. Firmware může použít UART MCU nebo softwarový UART (bit-bang). TTL rozhraní se aktivuje v config.h viz sekci "Buse"na straně 60 a Porty& Piny jsou definovány v config<MCU>.h (hledej SERIAL_PORT stránka 71).

Nevýhodou UART softwaru je, že TX signál není neustále “vysoký“, když je rozhraní v klidu. To je způsobeno použitou metodou k ovládání Portových Pinů. Přepsání tohoto ovládání by výrazně zvýšilo obsah firmware. Zdá se, že tento problém nemá žádný účinek na většinu USB na TTL převodníků. V případu, že bys měl přesto potíže, můžeš zkusit pull-up odpor (10-100k) na TX pinu k udržení “vysoké“ úrovně signálu v klidovém režimu.
Výchozí nastavení sériového rozhraní je 9600 8N1:
- 9600 bps
- 8 datových bitů
- žádná parita
- 1 stop bit
- žádná kontrola toku

### 2.5.3. One Wire Další podporovaný bus je OneWire, který má buď zkušební kolíky

(ONEWIRE_PROBES) nebo pevný pin MCU (ONEWIRE_IO_PIN), na staně 60. Ovladač je určen pro standardní rychlost sběrnice a klienty s externím napájením.
Zapojení zkušebních pinů:
sample # 1: Gnd
sample # 2: DQ (data)
sample # 3: Vcc (proud omezený odporem 680 Ω)
Je zapotřebí externí pull-up odpor 4,7 kΩ mezi DQ a Vcc!
Funkce, které vyžadují přesně jednoho klienta na sběrnici, mohou volitelně používat ROM Výstupní kód klienta (ONEWIRE_READ_ROM). V případě chyby CRC nebo pokud je na sběrnici připojeno více klientů, je výstup “-“. Je li kompletní ROM kód nula, došlo k chybě čtení. Jinak první část ROM kóduje rodinu produktů a druhá část sériové číslo.

### 2.6. LCD moduly

V současné době jsou podporovány následující LCD moduly nebo ovladače:
- HD44780 | (textové zobrazení, 2–4 řádky po 16–20 znakech) | s. 14
- ILI9163 | (grafický barevný displej 128x160) | s. 14
- ILI9341/ILI9342 | (grafický barevný displej 240x320 nebo 320x240) | s. 15
- ILI9481 | (grafický barevný displej 320x480, částečně zkoušený) | s. 16
- ILI9486 | (grafický barevný displej 320x480, částečně zkoušený) | s. 16
- ILI9488 | (grafický barevný displej 320x480, částečně zkoušený) | s. 16
- PCD8544 | (grafické zobrazení 84x48) | s. 17
- PCF8814 | (grafické zobrazení 96x65) | s. 17
- SH1106 | (grafické zobrazení 128x64) | s. 17
- SSD1306 | (grafické zobrazení 128x64) | s. 18
- ST7036 | (textové zobrazení, 3 řádky po 16 znacích) | s. 18
- ST7565R | (grafické zobrazení 128x64) | s. 19
- ST7735 | (grafický barevný displej 128x160) | s. 19
- ST7920 | (grafické zobrazení až 256x64) | s. 19
- STE2007 / HX1230 | (grafické zobrazení 96x68) | s. 21
- Terminál VT100 | (přes sériové rozhraní ) | s. 20
Věnuj pozornost napájecímu napětí a logické úrovni modulu displeje! Použij Převaděč úrovně, pokud je to nutné. Jednoduchý řadič úrovně s odpory v sérii s využitím interních omezovacích diod displeje Řadiče může fungovat, ale pouze pro pomalé busy, jako je Bit-Bang SPI. Doporučuji tedy používat integrované obvody převodníku napětí.
Pokud displej, navzdory správnému zapojení nic nezobrazuje, zkus změnit kontrast
v (config_<MCU>.h) viz 68.
Pokud chceš ušetřit IO piny, můžeš u většiny modulů LCD /CS a /RES signály pevně zapojit prostřednictvím pullup/down odporů a odpovídající IO piny vykomentovat, pokud na sběrnici visí pouze LCD modul.
Grafické displeje nabízejí obvykle nastavení orientace výstupu, např. otočení obrazu o 90 °. Lze je použít jak vodorovně, tak vertikálně. To umožňuje přizpůsobení obrazu příslušnému testerovi. Pro grafické barevné displeje jsou k dispozici další nastavení. V normálním barevném režimu lze použít několik barev, které lze změnit pomocí souboru color.h.

Dvoubarevný režim se aktivuje komentováním LCD_COLOR.
Barva písma je potom BARVA_PEN a barva pozadí je BARVA_BACKGROUND.
Pokud jsou primární barvy RGB červené a modré zaměněny, můžeš použít LCD_BGR k změnění příslušných barevných kanálů. U některých displejů je pořadí dílčích pixelů RGB obrácené a ovladač o něm nic neví.
Poznámka k ATmega 328:
Pokud je k PD2/PD3 připojen rotační kodér, připoj /CS od LCD modulu s PD5 a nastav LCD_CS v config_328.h (pouze pro grafické LCD moduly).
V opačném případě by rotační kodér pokazil datovou sběrnici a vedl k nesprávným výdajům.

### 2.6.1. Znakové sady a symboly

Konfigurace modulu displeje zahrnuje také znakovou sadu a volitelnou sadu symbolů. Příslušné znakové sady a symboly jsou uvedeny v části nastavení pro každý modul v souboru config_<MCU>.h.
U grafických displejů si obvykle můžeš vybrat z několika znakových sad. Symboly se aktivují pomocí přepínače SW_SYMBOLS v souboru config.h.
Pokud se ti více líbí styl starých symbolů, můžeš je stále používat změnou nastavení symbolů na SYMBOLS_<size>_OLD_<format>.h.
Pro testovací účely můžeš aktivovat funkci nabídky, která pak vypíše všechny znaky v položce znaková sada (SW_FONT_TEST) nebo všechny symboly komponent (SW_SYMBOL_TEST).
2.6.2. HD44780 | zapojený v 4-bytovém režimu.
Modul | config-<MCU>.h | 328 | 75,6% | 644 | 37,9% | 1280 | 13,1% | odkaz
DB4 | LCD_DB4 | PD0 | PB4 | PB0
DB5 | LCD_DB5 | PD1 | PB5 | PB1
DB6 | LCD_DB6 | PD2 | PB6 | PB2
DB7 | LCD_DB7 | PD3 | PB7 | PB3
RS | LCD_RS | PD4 | PB2 | PB4
R/W | LCD_RW | Gnd | Gnd | Gnd
E | LCD_EN1 | PD5 | PB3 | PB5

Tabulka 2.1. Zapojení HD44780 v paralelním režimu.

Tento LCD modul lze také použít s I2C adaptérem PCF8574. Za tímto účelem musí být aktivován I2C a kromě toho je požadována adresa adaptéru.

Modul | config-<MCU>.h | 328 | 76,5% | 644 | 38,2% | 1280 | 9,8% | odkaz
DB4 | LCD_DB4 | PCF8574_P4
DB5 | LCD_DB5 | PCF8574_P5
DB6 | LCD_DB6 | PCF8574_P6
DB7 | LCD_DB7 | PCF8574_P7
RS | LCD_RS | PCF8574_P0
R/W | LCD_RW | PCF8574_P1
E | LCD_EN1 | PCF8574_P2
LED | LCD_LED | PCF8574_P3

Tabulka 2.2. Zapojení LCD-Modulu s PCF8574.

2.6.3. ILI9163 | zapojený jako 4-drátový-SPI.
Modul | config-<MCU>.h | 328 | 87,4% | 644 | 43,8% | 1280 | 11,2% | odkaz
/RESX | LCD_RES | PD4 | PB2 | PB4 | možnost
/CSK | LCD_CS | PD5 | PB4 | PB5 | možnost
D/CX | LCD_DC | PD3 | PB3 | PB7
SCL | LCD_SCL | PD2 | PB7 | PB1 | SPI Clock
SDIO | LCD_SDA | PD1 | PB5 | PB2 | SPI MOSI

Tabulka 2.3. ILI9163 zapojení.

Pro správné zobrazení budeš možná muset použít nastavení X/Y otočení. V případě potřeby můžeš také posunout směr X. Je-li LCD_LATE_ON aktivován, začíná tester s vymazaným displejem, což vede ke krátkému zpoždění při zapnutí. Jinak se při zapnutí zobrazí krátce náhodné pixely.

2.6.4. ILI9341/ILI9342 | je možné použit přes SPI nebo 8-bit-Paralel.
Modul | config-<MCU>.h | 328 | 87,4% | 644 | 51,7% | 1280 | 13,2% | odkaz
RES | LCD_RES | PD4 | PB2 | PB4 | možnost
CS | LCD_CS | PD5 | PB4 | PB5 | možnost
DC | LCD_DC | PD3 | PB3 | PB7
SCK | LCD_SCK | PD2 | PB7 | PB1 | SPI Clock
SDI | LCD_SDI | PD1 | PB5 | PB2 | SPI MOSI
SDO | LCD_SDO | - | PB6 | PB3 | nur ILI9341∗
∗ zatím nepoužité

Tabulka 2.4. 4-Line-SPI zapojení ILI9341/ILI9342.

Modul | config-<MCU>.h | 328 | 644 | 1280 | 13,1% | odkaz
| LCD_PORT | | | PORTB
/RES | LCD_RES | | | PB4 | možnost
/CSX | LCD_CS | | | PB5 | možnost
D/CX | LCD_DC | | | PB7
WRX | LCD_WR | | | PB0
RDX | LCD_RD | | | PB6
| LCD_PORT2 | | | PORTL
D0 | LCD_DB0 | | | PL0 | LCD_PORT2 Pin #0
D1 | LCD_DB1 | | | PL1 | LCD_PORT2 Pin #1
D2 | LCD_DB2 | | | PL2 | LCD_PORT2 Pin #2
D3 | LCD_DB3 | | | PL3 | LCD_PORT2 Pin #3
D4 | LCD_DB4 | | | PL4 | LCD_PORT2 Pin #4
D5 | LCD_DB5 | | | PL5 | LCD_PORT2 Pin #5
D6 | LCD_DB6 | | | PL6 | LCD_PORT2 Pin #6
D7 | LCD_DB7 | | | PL7 | LCD_PORT2 Pin #7

Tabulka 2.5. 8-bit-Paralelní zapojení ILI9341/ILI9342.

Pro správné zobrazení budeš možná muset použít nastavení X/Y otočení. A nezapomeň na správné rozlišení X a Y. Nastavení (ILI9341 je 240x320 a ILI9342 je 320x240). Některé moduly displeje mají deaktivovanou rozšířenou sadu instrukcí ILI9341 (pin EXTC je zapnutý Masse), a výstup je pak často jen vágní. Toho lze opravit s LCD_EXT_CMD_OFF.
Vzhledem k vysokému počtu pixelů je výstup přes SPI trochu pomalý. Vymazání celého displeje trvá s Bit-Bang SPI asi 3 sekundy při 8MHz taktu MCU.
Lepší je použití hardwarového SPI nebo paralelní sběrnice.

2.6.5. ILI9481 | lze použít jako 8-Bit-Paralel, 16-Bit-Paralel nebo 4–vodičový SPI.
Modul | config-<MCU>.h | 328 | 644 | 51,6% | 1280 | 13,2% | odkaz
| LCD_PORT | | | PORTB
/RESX | LCD_RES | | PC4 | PB4 | možnost
CSX | LCD_CS | | PC3 | PB5 | možnost
D/CX | LCD_DC | | PC2 | PB7
WRX | LCD_WR | | PC1 | PB0
RDX | LCD_RD | | PC0 | PB6 | možnost
| LCD_PORT2 | | | PORTL
D0 | LCD_DB0 | | PB0 | PL0 | LCD_PORT2 Pin #0
D1 | LCD_DB1 | | PB1 | PL1 | LCD_PORT2 Pin #1
D2 | LCD_DB2 | | PB2 | PL2 | LCD_PORT2 Pin #2
D3 | LCD_DB3 | | PB3 | PL3 | LCD_PORT2 Pin #3
D4 | LCD_DB4 | | PB4 | PL4 | LCD_PORT2 Pin #4
D5 | LCD_DB5 | | PB5 | PL5 | LCD_PORT2 Pin #5
D6 | LCD_DB6 | | PB6 | PL6 | LCD_PORT2 Pin #6
D7 | LCD_DB7 | | PB7 | PL7 | LCD_PORT2 Pin #7

Tabulka 2.6. ILI9481/ILI9486 8-Bit-Paralel

Modul | config-<MCU>.h | 328 | 644 | 1280 | odkaz
LCD_D8 | LCD_DB8 | | | PC0 | LCD_PORT3 Pin #0
LCD_D9 | LCD_DB9 | | | PC1 | LCD_PORT3 Pin #1
LCD_D10 | LCD_DB10 | | | PC2 | LCD_PORT3 Pin #2
LCD_D11 | LCD_DB11 | | | PC3 | LCD_PORT3 Pin #3
LCD_D12 | LCD_DB12 | | | PC4 | LCD_PORT3 Pin #4
LCD_D13 | LCD_DB13 | | | PC5 | LCD_PORT3 Pin #5
LCD_D14 | LCD_DB14 | | | PC6 | LCD_PORT3 Pin #6
LCD_D15 | LCD_DB15 | | | PC7 | LCD_PORT3 Pin #7

Tabulka 2.7. dodatečné zapojení pro 16-Bit-Paralel.

Modul | config-<MCU>.h | 328 | 82,5% | 644 | 39,1% | 1280 | 10,0% | odkaz
RES | LCD_RES | PD4 | PB2 | PB4 | možnost
CS | LCD_CS | PD5 | PB4 | PB5 | možnost
D/C | LCD_DC | PD3 | PB3 | PB7
SCL | LCD_SCL | PD2 | PB7 | PB1 | SPI Clock
DIN/SDA | LCD_SDA | PD1 | PB5 | PB2 | SPI MOSI
| LCD_SDO | | | PB3 | datový výstup

Tabulka 2.8. Přiřazení pinů pro ILI9481 4-řádkové-SPI.

Vzhledem k vysokému rozlišení displeje a barevnému schématu RGB666 (3 bajty na pixel). SPI je poměrně pomalé, a to i v případě hardwarového SPI a 16 MHz taktu MCU. Proto nedoporučuji rozhraní SPI npoužívat. Pro správné zobrazení je obvykle nutné displej otočit ( LCD_ROTATE). V případě potřeby jej můžete také otočit o X a/nebo Y.

### 2.6.6. ILI9486 je řízena 8-bitová paralelní sběrnice, 16-bitová paralelní sběrnice nebo

4-řádkový SPI a používá stejné vývody jako ILI9481.

### 2.6.7. ILI9488 je řízena 8-bitová paralelní sběrnice, 16-bitová paralelní sběrnice nebo

4-řádkový SPI a používá stejné vývody jako ILI9481.

2.6.8. PCD8544 | je řízen pomocí SPI.
Modul | config-<MCU>.h | 328 | 82,5% | 644 | 39,1% | 1280 | 10,0% | odkaz
/RES | LCD_RES | PD4 | PB2 | PB4 | možnost
/SCE | LCD_SCE | PD5 | PB4 | PB5 | možnost
D/C | LCD_DC | PD3 | PB3 | PB7
SCLK | LCD_SCLK | PD2 | PB7 | PB1 | SPI Clock
SDIN | LCD_SDIN | PD1 | PB5 | PB2 | SPI MOSI

Tabulka 2.9. Přiřazení pinů pro PCD8544.

Protože displej má pouze 84 bodů ve směru X, max. 14 znaků na řádek pro znakovou sadu 6x8. Takže mohou být až dva znaky “neviditelné“. Pokud to vadí, můžeš zkrátit texty ve variables.h.

2.6.9. PCF8814 | je obvykle řízen 3-vodičovým SPI.
Modul | config-<MCU>.h | 328 | 82,6% | 644 | 41,3% | 1280 | 10,6% | odkaz
/RES | LCD_RES | PD4 | PB2 | PB4
/CS | LCD_CS | PD5 | PB4 | PB5 | možnost
SCLK | LCD_SCLK | PD2 | PB7 | PB1 | SPI Clock
SDIN | LCD_SDIN | PD1 | PB5 | PB2 | SPI MOSI

Tabulka 2.10. Přiřazení pinů pro PCD8814.

V případě potřeby lze výstup upravit pomocí nastavení Y-Flip a ten MX-Pin (X-Flip) od PCF8814 pomocí (Pull-Up/Down) otočit.

### 2.6.10. SH1106 je řízen 3-řádkovým SPI, 4-řádkovým SPI nebo I2C. 3-řádkové SPI vy-

žaduje Bit-Bang režim a SPI_9 musí být povolen.
Modul | config-<MCU>.h | 328 | 83,0% | 644 | 41,6% | 1280 | 10,7% | odkaz
/RES | LCD_RESET | PD4 | PB2 | PB4 | možnost
/CS | LCD_CS | PD5 | PB4 | PB5 | možnost
A0 | LCD_A0 | PD3 | PB3 | PB7
SCL (D0) | LCD_SCL | PD2 | PB7 | PB1 | SPI Clock
SI (D1) | LCD_SI | PD1 | PB5 | PB2 | SPI MOSI

Tabulka 2.11. Přiřazení pinů pro SH1106 4-řádkové-SPI.

Modul | config-<MCU>.h | 328 | 83,2% | 644 | 41,6% | 1280 | 10,7% | odkaz
/RES | LCD_RESET | PD4 | PB2 | PB4 | možnost
/CS | LCD_CS | PD5 | PB4 | PB5 | možnost
A0 | | Gnd
SCL (D0) | LCD_SCL | PD2 | PB7 | PB1 | SPI Clock
SI (D1) | LCD_SI | PD1 | PB5 | PB2 | SPI MOSI
Tabulka 2.12. Přiřazení pinů pro SH1106 3-řádkové-SPI (jen Bit-Bang).
Modul | config-<MCU>.h | 328 | 84,0% | 644 | 41,9% | 1280 | 10,7% | odkaz
/RES | LCD_RESET | PD4 | PB2 | PB0 | možnost
/CS | | Gnd
SCL (D0) | I2C_SCL | PD1 | PC0 | PD0
SDA (D1) | I2C_SDA | PD0 | PC1 | PD1
SA0 | Gnd (0x3c) | | | | 3.3V (0x3d)
Tabulka 2.13. Přiřazení pinů pro SH1106 v I2C. Pomocí X/Y-Flip nastavení můžeš změnit orientaci displeje.
U mnoha zobrazovacích modulů SH1106 musí být X-posunutí nastaveno na 2.
Jsou li pixelové čáry úplně rozhozené, zkus sekvenční COM-rozložení pinů (LCD_COM_SEQ).

2.6.11. SSD1306 je řízen 3-řádkovým SPI, 4-řádkovým SPI nebo I2C. 3-řádkové SPI vyžaduje Bit-Bang režim a SPI_9 musí být povolen.
Modul | config-<MCU>.h | 328 | 83,1% | 644 | 41,6% | 1280 | 10,7% | odkaz
/RES | LCD_RES | PD4 | PB2 | PB4 | možnost
/CS | LCD_CS | PD5 | PB4 | PB5 | možnost
DC | LCD_DC | PD3 | PB3 | PB7
SCLK (D0) | LCD_SCLK | PD2 | PB7 | PB1 | SPI Clock
SDIN (D1) | LCD_SDIN | PD1 | PB5 | PB2 | SPI MOSI

Tabulka 2.14. Přiřazení pinů pro SSD1306 4-řádkové-SPI.

Modul | config-<MCU>.h | 328 | 83,2% | 644 | 41,6% | 1280 | 10,7% | odkaz
/RES | LCD_RES | PD4 | PB2 | PB4 | možnost
/CS | LCD_CS | PD5 | PB4 | PB5 | možnost
SCLK (D0) | LCD_SCLK | PD2 | PB7 | PB1 | SPI Clock
SDIN (D1) | LCD_SDIN | PD1 | PB5 | PB2 | SPI MOSI
Tabulka 2.15. Přiřazení pinů pro SSD1306 3-řádkové-SPI (jen Bit-Bang).
Modul | config-<MCU>.h | 328 | 84,1% | 644 | 42,0% | 1280 | 10,7% | odkaz
/RES | LCD_RES | PD4 | PB2 | PB0 | možnost
/SCL (D0) | I2C_SCL | PD1 | PC0 | PD0 | možnost
SDA (D1&2) | I2C_SDA | PD1 | PC1 | PB0
SA0 (D/C) | Gnd (0x3c) | | | | 3.3V (0x3d)
Tabulka 2.16. Přiřazení pinů pro SSD1306 I2C.

Pomocí X/Y-Flip nastavení můžeš změnit orientaci displeje.
Jsou li pixelové čáry úplně rozhozené, zkus sekvenční COM-rozložení pinů (LCD_COM_SEQ) a/nebo invertované COM-rozložení pinů (LCD_COM_REMAP).
2.6.12. ST7036 | (nevyzkoušen) je adresován přes 4-bitové-Paralelní nebo 4-bit SPI.
Modul | config-<MCU>.h | 328 | 76,2% | 644 | 38,1% | 1280 | 9,8% | odkaz
DB4 | LCD_DB4 | PD0 | PB4 | PB0
DB5 | LCD_DB5 | PD1 | PB5 | PB1
DB6 | LCD_DB6 | PD2 | PB6 | PB2
DB7 | LCD_DB7 | PD3 | PB7 | PB3
RS | LCD_RS | PD4 | PB2 | PB4
R/W | LCD_RW | Gnd | ??? | ??? | možnost
E | LCD_EN | PD5 | PB3 | PB5
XRESET | | Vcc | ??? | ??? | možnost
Tabulka 2.17. Přiřazení pinů pro 4-bitový-paralelní ST7036.
Modul | config-<MCU>.h | 328 | 76,1% | 644 | 38,1% | 1280 | 9,8% | odkaz
XRESET | LCD_RESET | PD4 | PB2 | PB4 | možnost
CSB | LCD_CS | PD5 | PB4 | PB5 | možnost
RS | LCD_RS | PD3 | PB3 | PB7
SCL (DB6) | LCD_SCL | PD2 | PB7 | PB1 | SPI Clock
SI (DB7) | LCD_SI | PD1 | PB5 | PB2 | SPI MOSI
Tabulka 2.18. Přiřazení pinů pro 4-drátový-SPI od ST7036.

ST7036i hovoří I2C, ale (zatím) není podporován. Zvláštní Funkce ST7036 je pin pro aktivaci rozšířené sady instrukcí (Pin EXT), který je zapnut pro většinu modulů. Měl by být vypnout, musíš nastavení LCD_EXTENDED_CMD a LCD_CONTRAST vykomentovat.

2.6.13. ST7565R | je řízen 4/5-řádkovým-SPI.
Modul | config-<MCU>.h | 328 | 83,2% | 644 | 41,7% | 1280 | 10,7% | odkaz
/RES | LCD_RESET | PD0 | PB2 | PB4 | možnost
/CS1 | LCD_CS | PD5 | PB4 | PB5 | možnost
A0 | LCD_A0 | PD1 | PB3 | PB7
SCL (DB6) | LCD_SCL | PD2 | PB7 | PB1 | SPI Clock
SI (DB7) | LCD_SI | PD3 | PB5 | PB2 | SPI MOSI
Tabulka 2.19. Přiřazení pinů pro 4/5-řádkový-SPI k ST7565R. Pro správné zobrazení musíš možná použít nastavení X/Y-Flip a experimentovat s X-Offset. Téměř kompatibilní NT7538 potřebuje dlouhý resetovaný impuls (LCD_LONG_RESET).
2.6.14. ST7735 | ovládaný 4-drátovým-SPI.
Modul | config-<MCU>.h | 328 | 95,7% | 644 | 47,9% | 1280 | 12,2% | odkaz
/RESX | LCD_RES | PD4 | PB2 | PB4 | možnost
/CSK | LCD_CS | PD5 | PB4 | PB5 | možnost
D/CX | LCD_DC | PD3 | PB3 | PB7
SCL | LCD_SCL | PD2 | PB7 | PB1 | SPI Clock
SDIO | LCD_SDA | PD1 | PB5 | PB2 | SPI MOSI
Tabulka 2.20. Přizaření pinů od ST7735. Pro správné zobrazení budeš možná muset s X/Y-Flip nastavením experimentovat. Když je aktivována LCD_LATE_ON, startuje tester s vymazaným displejem, což má za následek krátké zpoždění při zapnutí. V opačném případě je po zapnutí krátce vidět náhodné pixely.
2.6.15. ST7920 | lze ovládat ve 4-bitovém-paralelním-Modu nebo s SPI.
Modul | config-<MCU>.h | 328 | 83,5% | 644 | xx,x% | 1280 | xx,x% | odkaz
/XRESET | LCD_RES | PD4 | PB2 | PB4 | možnost
/CS | LCD_CS | PD5 | PB4 | PB5 | možnost
SCLK | LCD_SCLK | PD2 | PB7 | PB1 | SPI Clock
SDIN | LCD_SDIN | PD1 | PB5 | PB2 | SPI MOSI
Tabulka 2.21. Přiřazení pinů pro SPI s ST7920.
Modul | config-<MCU>.h | 328 | 83,8% | 644 | 41,8% | 1280 | 10,7% | odkaz
/XRESET | LCD_RESET | Vcc | Vcc | Vcc
E | LCD_EN | PD5 | PB3 | PB5
RS | LCD_RS | PD4 | PB2 | PB4
RW | LCD_RW | Gnd | Gnd | Gnd
D4 | LCD_DB4 | PD0 | PB4 | PB0
D5 | LCD_DB5 | PD1 | PB5 | PB1
D6 | LCD_DB6 | PD2 | PB6 | PB2
D7 | LCD_DB67 | PD3 | PB7 | PB3
Tabulka 2.22. Přiřazení pinů pro 4-bitové-paralelní rozhraní ST7920. Z důvodu špatného designu modelu ST7920 lze používat pouze písma se šířkou 8 pixelů. K zpracování vodorovného adresování v 16 ti bitových krocích jsem musel nastavit vyrovnávací paměť obrazovky pro znaky.
2.6.16. STE2007/HX1230 | Typické 3-drátové-SPI ovládání pro STE2007.
Modul | config-<MCU>.h | 328 | 82,5% | 644 | 41,3% | 1280 | 10,6% | odkaz
/RES | LCD_RES | PD4 | PB2 | PB4 | možnost
/CS | LCD_CS | PD5 | PB4 | PB5 | možnost
SCLK | LCD_SCLK | PD2 | PB7 | PB1
SDIN | LCD_SDIN | PD1 | PB5 | PB2
Tabulka 2.23. Přiřazení pinů pro SPI s ST7920. V případě potřeby můžeš výstup otočit pomocí X/Y-Flip nastavení.

### 2.6.17. VT100 Terminal Ovladač VT100 nahrazuje LCD modul a kompletní výstup

je realisován přes sériový terminál VT100. Konfigurační sekce v VT100 aktivuje automaticky také sériové rozhraní. Vezmi prosím na vědomí, že VT100 ovladač ostatní možnosti, které by mohly ovlivnit výstup, deaktivuje.

### 2.7. Tlaˇcítka a ovládání

Tester je primárně ovládán testovacím tlačítkem, ale umožňuje další možnosti ovládání, které usnadňují provoz nebo které jsou pro některé funkce nutné.

2.7.1. Testovací tlaˇcítko zapíná tester a slouží k obsluze.
Tester rozlišuje mezi:
1. krátkým stisknutím, které se obvykle používá k pokračování funkce nebo k výběru další položky nabídky,
2. dlouhým zmáčknutím (> 0,3s), které provádí kontextovou akci a
3. dvojitým stisknutím, které akci ukončí.
Pokud tester očekává stisknutí klávesy pro pokračování v aktuální akci, je to označeno kurzorem v pravé dolní části modulu LCD.
Statický kurzor signalizuje, že následuje více informací
a blikající kurzor znamená, že hledání komponentů pokračuje.
U nabídek a některých dalších funkcí se kurzor nezobrazí, protože očekávaný postup by měl zde být jasný.

### 2.7.2. Rotaˇcní kodér (Hardwarová možnost) S rotačním kodérem operace do-

stává další funkce, závislé na kontextu.
Podrobnosti jsou vysvětleny v následujících částech.
Některé funkce umožňují větší změny díky rychlosti otáčení nebo skoky hodnot.
Čtecí algoritmus bere v úvahu počet pulzů Gray kódu na krok (ENCODER_PULSES)
a také počet kroků k plné 360° otáčce.
S hodnotou (ENCODER_steps) můžeš provést jemné nastavení detekce rychlosti otáčení. Obě hodnoty najdeš na straně 47. Vyšší hodnota zpomaluje rychlost otáčení, nízká hodnota ji zvyšuje. Pokud je směr otáčení obráceně, změň definici pinů pro A a B v config<MCU>.h.
Detekce rychlosti otáčení měří dobu dvou kroků. Proto bys měl s kodérem udělat alespoň dva kroky pro střední rychlost. Pro vyšší rychlost to jsou tři kroky.
Jediný krok vede vždy k nejnižší rychlosti.
2.7.3. (Vice/ménˇe tlaˇcítek). Pokud dáváš přednost klávesám před rotačním kodérem, můžeš alternativně také použít dvě tlačítka viz na straně 47. Tlačítka jsou stejně připojené jako otočný kodér (pull-up odpory, logická úroveň nízká při aktivaci).
Pro zrychlení rychlosti, podobné jako při otáčení rotačního kodéru, jednoduše stiskni dlouze tlačítko. Čím déle, tím je vyšší zrychlení.

### 2.7.4. Dotyková obrazovka (Hardwarová možnost) Řadiče ST7565 nebo SSD1306

se obvykle připojují s 4-vodičovým SPI rozhraním. Další možnost vstupu je dotyková obrazovka. K tomuto účelu by měl být LCD modul dostatečně velký a podporovat alespoň 8 řádků textu s 16 znaky nebo více. Abychom ušetřili cenný prostor na LCD, nepoužíváme k dotyku ikony. Místo toho jsou vlevo a vpravo neviditelné pruhy (každý 3 znaky široký), nahoře a dole (2 řádky vysoké) a jedna oblast uprostřed.
Pruhy nalevo a nahoře jsou pro „méně“ nebo „výběr nahoru“, pruhy vpravo a dole pro „více“ nebo „výběr dolů“. Takže stejné funkce jako u otočného kodéru.
Dlouhý dotyk urychluje změny některých funkcí, podobně rychlosti otáčení rotačního kodéru. Oblast uprostřed je softwarová verze testovacího tlačítka, nelze jí ale použít např. v testu Zenerových diod pro napájení externím proudem.
Pro použití dotykové obrazovky je nutná kalibrace.
Pokud ještě nejsou v paměti EEPROM uloženy hodnoty nastavení, spustí se automaticky po zapnutí testeru. Kromě toho ji můžeš také spustit z hlavní nabídky. Postup je celkem jednoduchý.

Pokud vidíš (na barevných LCD žlutou *) hvězdičku, stiskni ji. Tester pak odstraní hvězdičku a zobrazí nativní x/y polohu po každém dotyku. První nastavovací bod je vpravo nahoře, druhý vlevo dole. V závislosti na výsledku tester opakuje srovnání až třikrát. Pokud máš problémy s kalibrací, například podivné x/y pozice, zkontroluj orientaci dotykové obrazovky.
Levá horní část je považována za nulový bod.
Kalibraci můžeš kdykoliv přerušit testovacím tlačítkem.
Řadič má spínače pro otočení a zaměnění orientace:

∗ Vpravo nahoře je první nulový bod
x | y | upravit hodnotu nastavení s:
nízká | nízká | TOUCH_FLIP_X
nízká | vysoká | TOUCH_FLIP_X & TOUCH_FLIP_Y
vysoká | nízká | v pořádku
vysoká | vysoká | TOUCH_FLIP_Y
Po úspěšné úpravě kalibrace nezapomeň, uložit hodnoty offsetu pod: (Hlavní nabídka: Uložit).
Tabulka 2.24. Kalibrace x/y-hodnot.
Podporované ovladače dotykové obrazovky: | - ADS7843/XPT2046.
Konfiguraci najdeš pod oddílem pro LCD moduly v config<MCU>.h
(aktuálně pouze v config_644.h, protože 328 nemá dostatečně množství IO-pinů).

### 2.7.5. Uživatelské rozhraní Existuje několik možností, jak zobrazit výstup pro dis-

pleje, aby byl více efektní nebo více srozumitelnější.

U displejů s více než dvěma řádky textu:
- Zobrazení nápovědy ke klávesám místo kurzorů, pokud jsou k dispozici (UI_KEY_HINTS).
- Vystředění výstupních informací a některých dalších textů (UI_CENTER_ALIGN)
- Výpis stavu baterie v posledním řádku za zobrazením výsledku (UI_BATTERY_LASTLINE)

Pro grafické displeje:
- všechny předchozí možnosti
- Symboly s vývody pro třívodičové polovodiče (SW_SYMBOLS, ne pro
displeje s nízkým rozlišením)
- žádný výstup textového vývodu pro třívodičové polovodiče (UI_NO_TEXTPINOUT,
- pokud je aktivována funkce SW_SYMBOLS)
- žádný výstup z textového vývodu tělesa diody MOSFET
(UI_NO_BODYDIODE_TEXTPINOUT)
- zobrazení testovacích vývodů v invertovaném zobrazení (UI_PROBE_REVERSED)
- Zobrazení symbolu otazníku v případě neúspěšného vyhledávání (UI_QUESTION_MARK)
- Zobrazení symbolu zenerovy diody pro všechny zenerovy testy (UI_ZENER_DIODE)
- Zobrazení symbolu oscilujícího křemene pro režimy LF/HF v rozšířeném režimu čítače frekvence (UI_QUARTZ_CRYSTAL)
- Zobrazení symbolu pro komponenty OneWire u DS18B20, DS18S20 a Funkce DHTXX
- Posouvání menu po stránkách (místo po bodech) pro urychlení Operace s menu (UI_MENU_PAGEMODE)
- Zobrazení malého symbolu baterie pro zjištění stavu baterie (UI_BATTERY)

Pro barevné grafické displeje:
- všechny předchozí možnosti
- Barevné kódování testovacích pinů (UI_PROBE_COLORS)
- Nadpisy s vlastní barvou (UI_COLORED_TITLES)
- Hodnoty s vlastní barvou (ne jednotky, UI_COLORED_VALUES)
- Kurzory a nápovědy kláves s vlastní barvou (UI_COLORED_CURSOR)
- Barevné označení rezistorů (SW_R_E24_5_CC, SW_R_E24_1_CC a SW_R_E96_CC)

### 2.7.6. Bzuˇcák (Hardwarová možnost) Pokud si přeješ také akustický signál, můžeš

použít aktivní bzučák (s integrovaným oscilátorem), nebo i pasivní. Bzučák se ovládá pomocí (viz BUZZER_CTRL v config_<MCU>.h) a může být použit přímo (< 20mA) nebo prostřednictvím tranzistoru (NPN nebo n-kanálový MOSFET).

V současné době se bzučák používá pro:
- test kontinuity (SW_CONTINUITY_CHECK)
- Potvrzovací tón po vyhledání komponentů (UI_PROBING_DONE_BEEP)
- Potvrzovací tón pro platný datový paket v IR přijímači/dekodéru (SW_IR_RX_BEEP)
2.7.7. Komunikace s PC Tester používá ke komunikaci s PC sériové TTL rozhraní. Toto může být jednosměrné připojení (pouze odeslat) k sériovému připojení vydání nalezených součástí, nebo dokonce obousměrné k automatizaci. V obou případech musí být aktivováno
sériové rozhraní. | (Viz „Busses“v config_MCU.h strana 60).
Zvláštní znaky jsou nahrazeny standardními znaky, např. je z Ω (Ohm) R.
Konverzní tabulka:
|> <|
[]
Ω | R
µ | u
Poznámky:
- 9600 8N1
- nový řádek je <CR><LF>

### 2.7.8. Seriový výstup Tester také poskytuje detekované komponenty prostřednictvím

sériového rozhraní pokud je povoleno (viz UI_SERIAL_COPY v sekci „různá nastavení“na straně 54 v config.h).
K tomu postačuje jednoduchý terminálový program na PC.
Výstup sleduje výstup na LCD displeji, ale pouze pro nalezené komponenty.
Neexistuje žádný výstup z nabídek a funkcí přes sériové rozhraní, s výjimkou výsledků testu optočlenů.

### 2.7.9. Automatisierung Automatizace umožňuje dálkové ovládání testeru pomocí pří-

kazů přes obousměrné sériové připojení.
Povolíš-li tuto funkci, viz UI_SERIAL_COMMANDS v sekci „různá nastavení“, stránka 54 v config.h. tak se mírně mění chování testeru.
Automatizace vynucuje automatický režim, a tester po zapnutí nehledá komponentu. Příkazové rozhraní je velmi jednoduché. Pošleš příkaz a tester odpoví.
Komunikace je založena na textových řádcích ASCII a příkazy rozlišují velká a malá písmena. Každý příkazový řádek je zakončen (novým řádkem) <CR> <LF> nebo <LF>.
Tester přijímá příkazy pouze během čekání po zapnutí uživatelem, po výstupu komponenty nebo provedení funkce menu.
Řádky odpovědí končí <CR> <LF> (novým řádkem).
Seznam příkazů a jejich popis je v oddílu „Příkazy pro dálkové ovládání“ od stránky 41.

### 2.7.10. Výstup pˇres VT100 Namísto LCD displeje můžeš dosáhnout kompletní vý-

stup přes VT100 terminál (viz 2.6 v sekci LCD moduly na stránce 20). Aby nedocházelo k nejasnostem v rozvržení výstupu, jsou další možnosti sériového rozhraní deaktivované.

Kapitola 3 | Obsluha
3.0.1. Zapnutí | Dlouhým stisknutím při zapnutí se aktivuje režim automatického přidr-
žování. V tomto režimu čeká tester na krátké stisknutí tlačítka k pokračování testování.
Jinak běží tester v nepřetržitém režimu. Výběr můžeš s (UI_AUTOHOLD) v config.h obrátit. Po zapnutí se krátce zobrazí verze firmwaru.
S velmi dlouhým stiskem tlačítka (2s) při zapnutí, se vrátí tester na uložené standardní hodnoty.
- To může být výhodné, když je např. kontrast LCD modulu tak nastaven, že nic nevidíš. Pokud tester zjistí problém s uloženými hodnotami nastavení (problém s EEPROM), zobrazuje chybu kontrolního součtu a místo toho používá také výchozí hodnoty.
U testeru s vypínačem aktivuj POWER_SWITCH_MANUAL v config.h. V tomto případě to nemůže udělat tester sám.
3.0.2. Hledání komponent˚u Po zapnutí tester automaticky vyhledá komponenty. V nepřetržitém režimu tester opakuje hledání po krátké čekací době.
Pokud není, několikrát za sebou, nalezeno žádné zařízení, tester se sám vypne.
V Auto Hold režimu (signalizováno kurzorem) provede tester jednu operaci a čeká, před zahájením dalšího vyhledávání, na stisknutí tlačítka nebo otočení rotačního kodéru doprava. Čekací přestávka a automatické vypnutí v nepřetržitém režimu mohou být změněny prostřednictvím CYCLE_DELAY (strana 50) a CYCLE_MAX (strana 54) v config.h.
Režim automatického přidržování POWER_OFF_TIMEOUT (strana 55) má volitelné automatické vypnutí, které je aktivní pouze při vyhledávání komponentů, výstupu výsledku a v hlavní nabídce.
V obou režimech můžete vyvolat hlavní nabídku (viz níže).
Pokud je k dispozici možnost bzučáku/pípáku, můžeš aktivovat krátké potvrzovací pípnutí. pro ukončení vyhledávání části (UI_PROBING_DONE_BEEP).

### 3.0.3. Monitorování baterie je možné nastavit podle tvých představ na stránce

57. Každý cyklus hledání součástek začíná zobrazením napětí baterie a jejího stavu (ok, slabý, prázdný). Při poklesu pod její prahové napětí tester vypne. Baterie je kontrolovaná i během provozu.
Výchozí konfigurace monitorování baterie je navržena pro 9V baterii, ale lze ji přizpůsobit v sekci „power management“ v config.h na jakékoli jiné napájení.
Monitorování baterií může být deaktivováno pomocí BAT_NONE, přímé měření baterie menšího napětí než 5V, lze konfigurovat pomocí BAT_DIRECT, nebo nepřímé měření pomocí děliče napětí (definovaného BAT_R1 a BAT_R2).
Ačkoli některé testery podporují volitelné externí napájení, neumožňují jeho sledování.
V tomto případě můžeš podle BAT_EXT_UNMONITORED problémy s automatikou, při nízkém stavu napětí, vypnout.
Při externím napájení je stav baterie nastaven na „ext“ (externí).
Mezní hodnoty pro slabou a prázdnou baterii se nastavují pomocí BAT_WEAK a BAT_LOW, zatímco BAT_OFFSET definuje ztrátu napětí v okruhu, např. ochranná dioda s obrácenou polaritou a PNP tranzistor pro přepínání napájení.
Můžeš aktivovat zobrazení malé ikony baterie pro stav baterie místo textové varianty (UI_BATTERY). K dispozici je také možnost zobrazit stav baterie v posledním řádku za výstupem výsledků (UI_BATTERY_LASTLINE).

### 3.0.4. Vypínání, když při zobrazení výsledku posledního hledání součásti, stiskneš

dlouze tlačítko, ukáže tester krátce „sbohem“ nebo „Ciao!“ a vypne se. Po dobu stisknutí zůstane však stále zapnutý. To je příčinou konstrukce obvodové části napájecího zdroje.

### 3.1. Výbˇerové menu

docílíš krátkým dvojitým stisknutím testovacího tlačítka po výstupu posledního výsledku. (Možná budeš muset na začátku trochu cvičit. ;-)
Máš-li rotační kodér, spustí se menu otočením vlevo.
S aktivováním UI_SHORT_CIRCUIT_MENU (na stránce 54), lze také aktivovat starou metodu (zkratování tří zkušebních pinů).
V nabídce vybereš další položku krátkým stisknutím. Dlouhým stisknutím ji zvolíš.
U dvouřádkového LCD modulu je vpravo dole zobrazena navigační pomůcka. Šipka „> “, pokud náslaedují další body, nebo „<“ u posledního bodu. Jdeš-li dále, dostaneš se na začátek.
Pro LCD modul s více než 2 řádky je vybraný bod označen “*“.
Pokud máš rotační kodér, dosáhneš jeho otáčením předchozí nebo následující bod. I zde dochází k přetečení, tzn. od posledního k prvnímu bod.
Na rozdíl od předešle, zde vybírá položku krátký stisk tlačítka.
Po provedení funkce skočí tester normálně zpět k opětovnému vyhledávání součástek. Pokud chceš zůstat v nabídce, můžeš toto chování pomocí UI_MAINMENU_AUTOEXIT vypnut. Nabídka se poté zavře až výslovným pokynem “Exit“.
Některé body/doplňky ukazují krátce na začátku rozložení použitých testovacích pinů. Informace se zobrazí na několik sekund, ale můžeš ji krátkým stiskem tlačítka přeskočit. Funkce, které generují signály, vysílají jejich signál standardně na pinu # 2.
Přitom budou piny # 1 a # 3 uzemněny.
Je tvůj tester nakonfigurován pro výstup signálu na svém vlastním výstupu (OC1B) nebudou zkušební piny použity.

### 3.1.1. PWM-Generátor dělá přesně to, co čekáš :-) Za předpokladu, že před přelože-

ním firmwaru vybereš buď PWN generátor s jednoduchým nebo s rozšířeným ovládáním, který vyžaduje rotační kodér a větší display.
Rozložení testovacích pinů:
Pin # 2: | výstup (přes 680Ω odpor k omezení proudu)
Pin # 1 a # 3: uzemněny
3.1.2. Jednoduchý PWM Nejprve musíš z daného seznamu vybrat možnou frekvenci. Krátké zmáčknutí volí další frekvenci, dlouhým stisknutím jí spustíš, stejně jako u volby menu. S rotačním kodérem spouštíš krátkým stisknutím.
Pracovní cyklus začíná na 50 % a lze jej měnit v krocích po 5 %.
Krátký stisk pro +5 % a dlouhý pro -5 %.
Chceš-li program ukončit, stiskni dvakrát za sebou zkušební tlačítko.
Pokud je k dispozici rotační kodér, můžeš být pracovní cyklus měnit v krocích po 1 %.

### 3.1.3. Rozšíˇrený PWM Krátkým stiskem klávesy se zde přepíná mezi frekvenčním a

pracovním cyklem. Vybraná hodnota je označena hvězdičkou.
Točením rotačního kodéru vpravo zvolenou hodnotu zvyšuješ, doleva jí snižuješ.
Dlouhý stisk tlačítka zde obnoví výchozí hodnoty (frekvence: 1 kHz, pracovní cyklus: 50 %). Dvojím stisknutím tlačítka PWM generátor ukončíš.

### 3.1.4. Obdélníkový signální generátor vydává signál s čtvercovou vlnou s pro-

měnnou frekvencí až do 1/4 MCU taktu (2MHz při 8MHz taktu). Počáteční frekvence je 1 kHz a pomocí otočného kodéru se nechá měnit. Stupeň změny určuje rotační rychlost, tzn. pomalé otáčení způsobí malé změny a rychlé otáčení velké.
Protože je generování signálu založeno na interní PWM funkci MCU, není možné generovat libovolné frekvence, ale pouze v krocích. Pro nízké frekvence je velikost kroku je poměrně malá, pouze při vysokých frekvencích se stává významnou.
Dlouhé stisknutí tlačítka vrátí frekvenci na 1 kHz a dvojité stisknutí ukončí generátor. Rozložení testovacích pinů:
Pin # 2: | výstup (přes 680Ω odpor k omezení proudu)
Pin # 1 a # 3: uzemněny
Poznámka: Poznámka: Nutný Rotační enkodér nebo jiná volba ovládání!

### 3.1.5. Zjištˇení Zenerového napˇetí (hardwarová úprava) s pomocí DC-DC

převodníku je možné generovat testovací napětí do 50V k testování Zenerových diod. Připojení se provádí pomocí svých vlastních testovacích pinů.
Dokud je testovací tlačítko stisknuto, generuje měnič testovací napětí a zobrazí proudové napětí.
Po uvolnění tlačítka se zobrazí nejmenší naměřené napětí, pokud běžel test dostatečně dlouho pro stabilní zkušební napětí. Tento proces lze libovolně často opakovat.
Pro ukončení stiskni krátce testovací tlačítko dvakrát po sobě.
Zesilovací měnič lze také přepínat přes pevný I/O pin (ZENER_SWITCHED), k prodloužení výdrže baterie.
Pokud je tvůj tester vybaven pouze děličem napětí 10:1 bez zesilovacího převodníku pro měření externího napětí nebo bez měniče externího napětí, nebo je měnič boost v provozu po celou dobu, můžeš aktivovat alternativní režim (ZENER_UNSWITCHED), který měří napětí pravidelně, bez stisknutí testovacího tlačítka. Pokud tester zobrazí kurzor v pravém dolním rohu mezi měřeními, můžeš deaktivovat zenerovo měření dvojitým stisknutím tlačítka.
Další možností je automatické spuštění Zenerova testu během běžného vyhledávání součástek. (HW_PROBE_ZENER) během běžného vyhledávání komponentů. Pokud není nalezena žádná komponenta na normálních testovacích vývodech, zkontroluje tester napětí na zenerových testovacích vývodech. Tato možnost je k dispozici pouze v případě, když je aktivován bud’ ZENER_UNSWITCHED nebo ZENER_SWITCHED.
V případě, že má tvůj tester nestandardní dělič napětí (ne 10:1), aktivuj ZENER_DIVIDER_CUSTOM a nastav hodnoty rezistorů (ZENER_R1 a ZENER_R2). Obvod pro Zenerovou diodu:
Pin +: | katoda
Pin -: | anoda
3.1.6. Logický tester (hardwarová úprava) | kontroluje stav logických signálů
pomocí pevného ADC- pinu plus děliče napětí. Dělič napětí by měl mít poměr 4:1, aby bylo možné dosáhnout napětí do až 20 V (15 V CMOS).
Vývod ADC je TP_LOGIC (v config_<MCU>.h) a dělič napětí je nastaven v config.h (LO-GIC_PROBE_R1 a LOGIC_PROBE_R2).

+ Signal

R1
10k

TP_LOGIC
(ADC pin)
R2
3k3

— Gnd
dělič napětí
vchod
Obrázek 3.1

Možná by nebylo špatné zlepšit ochranu vstupu, např. pomocí ochranných diod.
Po spuštění tester automaticky přečte napětí, porovná hodnoty napětí s prahovými hodnotami logických úrovní a poté zobrazí logický stav napětí:

0 pro nízký
1 pro vysoký
Z pro nedefinovaný/HiZ

K dispozici je jednoduchá nabídka pro nastavení logické rodiny nebo Vcc/Vdd a prahů logických úrovní.
Pomocí testovacího tlačítka vyber požadované nastavení (označené hvězdičkou). Pak pomocí otočného ovladače můžeš změnit prostředí. Při změně logické rodiny nebo Vcc/Vdd jsou prahové hodnoty automaticky upraveny. Tyto lze měnit podle potřeby. V případě neobvyklého napětí Vcc/Vdd zvol vyšší možnost. Výchozí nastavení hodnoty pro Vcc/Vdd jsou:
- TTL : 5V
- CMOS : 3,3 V, 5 V, 9 V, 12 V, 15 V
A jako obvykle se dvěma krátkými stisky kláves tester logiky ukončí.

### 3.1.7. tester kontinuity (hardwarová úprava) kontroluje spojitost obvodů a

vydává akustický signál prostřednictvím bzučáku a zároveň výstupní napětí mezi testovacími piny. Testovací proud je omezen na přibližně 7 mA pomocí Rl (680 Ω). Prahové hodnoty pro bzučák jsou:
Napětí: | | aktivní bzučák: | pasivní bzučák:
< 100 | mV | nepřetržitý zvuk | opakované pípání s vysokou frekvencí
100-700 mV | opakované krátké pípnutí | opakované pípání s nízkou frekvencí
> 700 | mV | žádný zvuk
Krátké pípnutí signalizuje možný polovodičový přechod. V případě přerušení nebo velmi vysokého odporu se napětí blíží 5 V.
Po spuštění testeru spojitosti tester na několik sekund zobrazí zapojení testovacích kolíků. To lze přeskočit zmáčknutím tlačítka test.
Dvěma krátkými stisky kláves test ukončíš.
Zapojení zkoušecích vývodů:
Pin #1: | Vcc (680Ω odpor pro omezení proudu)
Pin #3: | | Zem
3.1.8. ESR-Tool | (měřič ekvivalentního sériového odporu) může měřit a zobrazovat kon-
denzátor v obvodu a kromě kapacity měří také ESR pokud v obvodu kondenzátor najde. Před připojením se přesvědč, že je kondenzátor vybitý!
Měřené hodnoty mohou mít odchylky způsobené paralelními komponenty v obvodu.
Pro zahájení měření krátce stiskni testovací tlačítko.
Chceš-li program ukončit, stiskni dvakrát za sebou zkušební tlačítko.
Obvod pro měření ESR:
Pin #1: | | +
Pin #3: | | -
3.1.9. Unikající proud kondenzátoru | Test svodového proudu nabíjí kondenzátor
a zobrazuje proud a napětí na měřicím odporu. Načítání začíná s Rl (680Ω) a přepne na Rh (470kΩ), jakmile dosáhne tok určitého limitu. Každý zkušební cyklus začíná zobrazením přiřazení zkušebních pinů. Po připojení kondenzátoru začíná ládovaní stisknutím testovacího tlačítka (nebo točením rotačního kodéru doprava).
Další stisknutí ukončí nabíjení a tester vybíjí kondenzátor a zobrazuje zbytkové napětí.
Po dosažení limitu vybití začne tester nový testovací cyklus.
Chceš-li test ukončit, stiskni dvakrát krátce testovací tlačítko.
Poznámka: Věnuj pozornost polaritě Elkos!
Zapojení kondenzátoru:
Pin #1: | | +
Pin #3: | | -
3.1.10. R/C/L Monitory | Monitorové funkce měří neustále pasivní součástky na pinech
#1 a #3. Po startu ukazuje tester na pár vteřin obsazení pinů, což je možné stisknutím tlačítka přeskočit.

Mezi měřeními je krátká dvouvteřinová přestávka což je označeno kurzorem vpravo dole. Během pauzy lze monitor dvojitým stiskem testovací klávesy ukončit.
Dostupné monitory:
R-monitor | (odpor)
C-monitor | (kapacita plus volitelně ESR)
L-monitor | (indukce)
R/C/L-monitor (odpor plus volitelně L, nebo C plus volitelně ESR)
R/L-monitor (odpor plus volitelně indukce)
Pro monitory C a L existují možnosti pro uchování poslední platné hodnoty měření. (SW_MONITOR_HOLD_ESR, SW_MONITOR_HOLD_L). Ta se zobrazí ve třetím řádku. Poznámka k bit-bang SPI:
Hodnoty kapacit elektrolytických kondenzátorů mohou být o něco nižší než při normálním hledání součástek (příčina zatím není známa).

### 3.1.11. L/C-Mˇeˇriˇc (hardwarová úprava) je založen na jednoduchém obvodu LC

oscilátoru, jaký se používá u více levných PIC L/C měřičů. Obvyklý design (82µH a 1nF) má základní frekvenci kolem 595 kHz a připojení dalšího kondenzátoru nebo indukčnosti tuto frekvenci snižuje. S pomocí referenčního kondenzátoru známé hodnoty, měření frekvence a trochu matematiky je možné, hodnotu neznámého kondenzátoru určit, resp. lze vypočítat Indukčnost. PIC-L/C měřiče mají obvykle měřicí rozsah od 10nH do 100mH, a 0,1pF až 900nF. Zdá se, že pro frekvenci používají dobu brány 100 ms.
m-Firmware zde ale používá automatický výběr rozsahu s časy brány 100 ms a 1000 ms ke zvýšení rozlišení malých hodnot L/C. Měřicí rozsah tedy začíná přibližně na 1 nH a 10 fF. Rozsahy měření tedy začínají přibližně na 1nH a 10fF (0,01pF). Maximální měřitelná indukčnost je zhruba 150mH. Co se týče kapacity, narazil jsem na problém s mojí deskou s výstupním signálem od cca 33nF. Tam se na hranách objevují malé ostruhy, takže čítač frekvence vidí více pulsů, než kolik jich ve skutečnosti je. Jeden z uživatelů uvedl, že se jedná o známý problém obvodu oscilátoru založeného na LM311. Při testování po několika úpravách nedošlo k výraznému zlepšení. Proto, se nabízí, použít další komparátor nebo logické hradlo se Schmittovým spouštěčem pro vyčištění výstupního signálu oscilátoru. Čtyřnásobný CMOS NAND 4093 se k tomuto účelu skvěle hodí. S vyčištěným výstupním signálem, leží maximální kapacita přibližně u 120nF (nad touto hodnotou se LC oscilátor stává nestabilním). Tester omezuje měření na dolní hodnotu 10kHz, tj. teoretické maximální hodnoty jsou 250mH resp. 3,5ľF, pokud by LC oscilátor pracoval stabilně.
Po spuštění L/C měřiče je první věcí, kterou tester provede, samo test, označený zprávou „samo-test ...“. Potom lze připojit kondenzátor nebo cívku k měření. Krátkým Stisknutím tlačítka přepínáte mezi měřením C a L (standard: měření C). Frekvence LC oscilátoru se v průběhu času poněkud mění (až do 100 Hz) a pak potřebuje novou úpravu. Pokud máte rostoucí nulovou hodnotu nebo vidíš „-“ bez připojené součástky, proveď automatické nastavení dlouhým stisknutím tlačítka. V případě, že nastal problém s párováním nebo se zruší stisknutím klávesy, tester opustí L/C metr a udává chybu. Dvě krátké stisknutí klávesy ukončí L/C metr.
Tipy:
- Referenční kondenzátor by měl být typu filmu 1nF s malou tolerancí. Můžeš ale také použít konvenční filmový kondenzátor kolem 1nF.
Měř dobrým LCR měřičem a podle toho změň LC_METER_C_REF.
- Pokud tě zajímá frekvence LC oscilátoru a jeho drift, pak aktivuj LC_METER_SHOW_FREQ.
3.1.12. ˇCítaˇc kmitoˇct˚u (hardwarová úprava) je k dispozici ve dvou verzích. Jednoduchý sestává z pasivního vstupu na pinu T0 MCU (F-in).
Rozšířený má kromě vstupní vyrovnávací paměti také dva oscilátory pro testování krystalu (pro nízké a vysoké frekvence) a další frekvenční dělič.
Oba okruhy jsou popsány v dokumentaci Karla-Heinze [16].

### 3.1.13. Jednoduchý ˇcítaˇc pokud je nainstalován přídavný obvod pro jednoduchý čí-

tač kmitočtu, můžeš zjistit frekvence přibližně od 10 Hz až 1/4 taktu frekvence MCU s rozlišením na 1Hz při frekvencích pod 10 kHz. Frekvence se neustále měří a zobrazuje.
Automatické nastavení rozsahu nastavuje dobu brány na hodnoty mezi 10ms a 1000ms, v závislosti na frekvenci. Měření ukončíš dvojitým stiskem tlačítka.

### 3.1.14. Rozšíˇrený ˇcítaˇc Počítadlo rozšířené frekvence má další předzesilovač, který

povoluje měření vyšších frekvencí.
Teoretické maximum je 1/4 taktu MCU vynásobených prescalerem (16:1 nebo 32:1). Ovládací signály jsou definovány v config<mcu>.h, a prosím nezapomeň v config.h na výběr správného předzesilovače.
Vstup signálu (vyrovnávací vstup, křemenný oscilátor pro nízké hodnoty frekvence,) nebo (křemenný oscilátor pro vysoké frekvence) změníš pomocí testovacího tlačítka nebo rotačního kodéru.
Počítadlo kmitočtů zastaví dva krátké stisky tlačítka.

### 3.1.15. Kroužkový tester (hardwarová úprava) (LOPT/FBT tester) kontroluje

cívky a transformátory na přítomnost zkratu. Obvod generuje spouštěcí impuls a tester pak jednoduše počítá počet kmitů, který udává hodnotu Q. Obvod může být připojen přes pevný pin (RING_TESTER_PIN) nebo přes konektor testovacích kolíků (RING_TESTER_PROBES). V obou případech je kolík T0 ATmega vstupem čítače (počítá se při klesající hraně). Vývod T0 může být také použít paralelně k ovládání displeje.
Po spuštění kroužkového testeru se zobrazí přiřazení testovacích pinů, pokud je aktivováno ovládání prostřednictvím testovacích pinů. Poté tester automaticky kontroluje cívky/transformátory a zobrazuje počet kmitů. Jako obvykle, dvěma krátkými stisky kláves test ukončíte. Interpretace počtu oscilací pro obvod s Darlingtonovým obvodem. na základě kroužkového testeru Boba Parkera:
Oscilace | Q
0 | zkrat nebo rozpojení
1 - 3 | nízké Q (špatné)
4 - 5 | střední Q (nejasné)
>= 6 | vysoké Q (dobré)
Kromě výše uvedeného jednoduchého zapojení můžete použít i složitější varianty, pokud pracují s napětím přibližně 5 V, vyžadují malý proud (< 20 mA) a mají generovat počítací impulsy s klesající hranou.
Zapojení pro ovládání přes testovací kolíky:
Pin #1: | Vcc (5 V)
Pin #2: | mpulsní výstup (s 680Ω odporem pro omezení proudu)
Pin #3: | Zem
T0: | Vstup čítače
3.1.16. Poˇcitadlo událostí (s hardwarovou úpravou) | Čítač událostí používá
pin T0 (F-in) jako pevný vstup a reaguje na náběžnou hranu signálu. Pin T0 není možné použít
současně pro display. | Doporučuje se jednoduchá úprava vstupu.
Čítač je řízen pomocí malého menu, které také hodnoty čítače zobrazí. Položky menu a jejich změna jsou vybírány krátkým stiskem, pomocí otočného kodéru nebo dalších tlačítek.
První položka nabídky je režim počítadla:
- Počítání | počítá čas a události
- Čas | počítá události za daný čas
- Události | počítají čas pro daný počet událostí
Druhá položka nabídky „n“ je počet událostí. V režimu počítadla „Události“ zobrazí hodnotu zastavení, kterou lze změnit. Dlouhým stisknutím nastavíš hodnotu stop na výchozí hodnotu (100). V jiných režimech počítadla je tato položka nabídky blokována.
Další nabídka je „t“ časový interval ve vteřinách (výchozí: 60 s). Stejná hra, pouze pro režim času.
Poslední položka nabídky spustí nebo zastaví čítač dlouhým stisknutím tlačítka. V době provozu je počet události a uplynulý čas každou vteřinu a poté co skončí měření aktualizován. Časový limit je 43200s (12h) a pro události 4*10^9.
Jakmile je jedna z mezních hodnot překročena, počítadlo se automaticky zastaví.
Limit nebo hodnota zastavení událostí se kontroluje každých 200 ms. Proto pokud hodnota překročí 5 událostí/s, lze tuto hodnotu překročit.
- Spouštˇecí výstup | můžeš aktivovat s (EVENT_COUNTER_TRIGGER_OUT)
k ovládání dalšího zařízení pomocí zkušebních kolíků.
Výstup spouště je během počítání aktivován, tj. náběžná hrana při startu a klesající hrana při zastavení.
Zapojení výstupu:
Pin #1: | uzemění
Pin #2: | výstup (přes 680Ω odpor k omezení proudu)
Pin #3: | uzemění

### 3.1.17. Rotaˇcní kodér testuje rotační enkodéry a určuje rozložení pinů. Tvým úkolem

je připojit testovací piny k rotačnímu kodéru (A, B, Common) a točit enkodérem doprava (ve
směru hodinových ručiček). | Algoritmus vyžaduje pro detekci 4 kroky Grey kódu.
Směr otáčení je pro detekci A a B nutný, protože nesprávný směr by způsobil kroucení pinů. Když je rotační kodér detekován, vydá tester rozložení pinů a čeká (v automatickém režimu) na stisknutí tlačítka nebo (v nepřetržitém režimu) čeká chvíli.
Pro ukončení stiskni během vyhledávání krátce tlačítko testu.
3.1.18. Kontrast je možné, u některých grafických LCD modulů upravit.
Krátké stisknutí hodnotu zvýší, dlouhý stisk ji sníží. Pokud máš k dispozici otočný kodér, lze
změnit hodnotu kontrastu točením. | K ukončení, stiskni dvakrát za sebou zkušební tlačítko.
3.1.19. Detektor/Dekodér pro IR dálkové ovládání | detekuje a dekóduje sig-
nály z IR ovladačů a vyžaduje IR přijímací modul, např. ze série TSOP.
Při překladu firmwaru si můžeš vybrat mezi dvěma variantami připojení.
V první variantě je modul připojen k normálním testovacím pinům (SW_IR_RECEIVER). Druhou variantou je pevný modul, připojený ke konkrétnímu MCU pinu (HW_IR_RECEIVER). Pokud je známý protokol zjištěn, poskytne tester protokol, adresu (pokud je k dispozici), příkaz a případně hexadecimálně další informace.
Výstupní formát je: <Protokol> <Datová pole>
Pokud je datový paket vadný, ohlásí „?“.
Pokud je protokol neznámý, zobrazí tester počet pauz & pulsů a trvání prvního pulzu a první pauzy v jednotkách 50µs: ? <Pulse>: <první impuls> - <první pauza>
Pokud je počet pulzů na různých tlačítkách dálkového ovladače stejný, jedná se s největší pravděpodobností o PDM nebo PWM modulaci.
Měnící se počet pulzů naznačuje bi-fázovou modulaci.
K zastavení stiskni jednou testovací tlačítko.
Podporované protokoly a jejich datová pole:
- JVC <Adresa>: <příkaz>
- Kaseikyo (japonský kód, 48 bitů) <Code Vendor>: <System> - <Produkt>: <funkce>
- Matsushita (Panasonic MN6014, C6D6 / 12 bitů) <Code Zařízení>: <Data code>
- Motorola <příkaz>
- NEC (standardní a pokročilé) <Adresa>: <příkaz> R pro opakování sekvence
- Proton / Mitsubishi (M50560) <Adresa>: <příkaz>
- RC-5 (standardní) <Adresa>: <příkaz>
- RC-6 (standardní) <Adresa>: <příkaz>
- Samsung / Toshiba (32 bitů) <Code Zařízení>: <Data code>
- Sharp <Adresa>: <příkaz>
- Sony SIRC (12, 15 a 20 bitů) 12 & 15: <příkaz>: <adresa> 20: <příkaz>: <adresa>: <rozšíření>
Volitelné protokoly (SW_IR_RX_EXTRA):
- IR60 (SDA2008 / MC14497) <příkaz>
- Matsushita (Panasonic MN6014, C5D6 / 11 bitů) <Code Zařízení>: <Data code>
- NEC µPD1986C <Code dat>
- RECS80 (standardní a pokročilé) <Adresa>: <příkaz>
- RCA <Adresa>: <příkaz>
- Sanyo (LC7461) <Code Zařízení>: <key>
- Thomson <Zařízení>: <funkce>
Nosná frekvence přijímacího modulu TSOP IR nemusí přesně odpovídat dálkovému ovládání. Ve skutečnosti pouze snižuje rozsah, což pro náš účel ale nepředstavuje problém.
Pokud máš k dispozici možnost bzučáku/pípáku, můžeš aktivovat krátký potvrzovací tón pro platné datové pakety (SW_IR_RX_BEEP).

### 3.1.20. IR pˇrijímací modul na testovacích pinech

jako první připoj IR přijímací modul k IR detektoru dálkového ovládání!

Administrace pro modul TSOP:
Sonda # 1: | uzemnění / Gnd
Sonda # 2: | Vs (680Ω omezovač proudu)
Sonda # 3: | Data/Out
Pokud je to nutné, lze firmware změnit na jiné vývody. by to bylo nutné. To je zejména u testerů s nulovými zásuvkami užitečné:
- alternativní zapojení vývodů SW_IR_RX_PINOUT_D_G_V
Sonda #1: | Data/Out
Sonda #2: | Gnd
Sonda #3: | Vs (680Ω omezovač proudu)
- alternativní zapojení vývodů SW_IR_RX_PINOUT_D_V_G
Sonda #1: | Data/Out
Sonda #2: | Vs (680Ω omezovač proudu)
Sonda #3: | Gnd
Poznámky: Odpor pro omezení proudu nastavuje IR přijímací modul s a předpokládá rozsah napájecího napětí asi 2,5 - 5V. Pokud máš 5V modul, můžeš na vlastní nebezpečí odpor v config.h deaktivovat. Zkrat však může MCU zničit.
- U pevného přijímacího modulu nastav port a data v config<MCU>.h

### 3.1.21. IR dálkové ovládání odešle kódy dálkového ovládání, které jsi dříve zadal

a používá se k testování IR přijímačů nebo zařízení s IR dálkovým ovládáním.
Tato funkce vyžaduje další možnost vstupu, například např. rotační kodér, displej s více než čtyřmi řádky textu a jednoduchý obvod ovladače pro IR-LED.
Tester vám ukáže protokol, nosnou frekvenci, pracovní cyklus dopravce a několik datových polí.
Krátkým stisknutím testovacího tlačítka přepínáš tam a zpět mezi body.
Vybraný bod je označen znakem „*“.
Pomocí otočného enkodéru (nebo jiné možnosti vstupu) měníš nastavení nebo hodnotu bodu. Tester odesílá IR kód tak dlouho, jak je testovací tlačítko stisknuto. A jako obvykle, dvě krátké stisknutí tlačítka funkci zastaví.
Pokud změníš protokol, nastaví se nosná frekvence a pracovní cyklus na výchozí hodnoty příslušného protokolu.
Tyto můžeš ale libovolně změnit.
Nosnou frekvenci lze nastavit na 30 až 56 kHz a pracovní cyklus zapnout na 1/2 (50%), 1/3 (33%) nebo 1/4 (25%).
Datová pole jsou části kódu dálkového ovládání, které můžeš nastavit.
Jsou níže vysvětleny a většinou jde pouze o adresu a příkaz.
Podporované protokoly a jejich datová pole:
- JVC <Adresa: 8> <příkaz: 8>
- Kaseikyo (japonský kód) <Výrobce: 16> <Systém: 4> <Produkt: 8> <Funkce: 8>
- Matsushita (Panasonic, MN6014 12 bitů) <Zařízení: 6> <tlačítko: 6>
- Motorola <Command: 9>
- Norma NEC <Adresa: 8> <příkaz: 8>
- NEC Extended <Adresa: 16)> <příkaz: 8>
- Proton / Mitsubishi (M50560) <Adresa: 8> <příkaz: 8>
- RC-5 standard <Adresa: 5> <příkaz: 6>
- RC-6 standard, režim 0 <Adresa: 8> <příkaz: 8>
- Samsung / Toshiba (32 bitů) <Zařízení: 8> <tlačítko: 8>
- Sharp / Denon <Adresa: 5> <příkaz: 8> <maskování: 1>
- Sony SIRC-12 <Příkaz: 7> <Adresa: 5>
- Sony SIRC-15 <Příkaz: 7> <Adresa: 8>
- Sony SIRC-20 <Příkaz: 7> <Adresa: 5> <Pokročilé: 8>
Volitelné protokoly (SW_IR_RX_EXTRA):
- Thomson <Zařízení: 4> <funkce: 7>
Datová pole jsou oddělena mezerami a jejich syntaxe je: <Název pole>: <počet bitů>

Rozložení testovacích pinů:
Pin # 2: | výstup (přes 680Ω odpor k omezení proudu)
Pin # 1 a # 3: uzemněny
Signální výstup (testovací pin # 2) má odpor pro omezení proudu a může proto spínat pouze asi 5 mA, což pro typickou IR LED s If 100mA nestačí.
Obrázek 3.2 ukazuje ovladač, který lze pro IR-LED (Vf 1,5V, If 100mA) použít.

+5V

75R

IR LED

3k9
Signal

BC548

- Gnd
Obrázek 3.2.
IR-ovladač

Poznámka:
Pokud se načasování pulsů/pauzy nehodí, použij alternativní metodu čekající smyčky SW_IR_TX_ALTDELAY na straně 50. To může být nutné, pokud tvůj C kompilátor optimalizuje, přesto že je nastaven na zachování kódu vloženého v assembleru.

### 3.1.22. Test optických spojek kontroluje optočlen

a dává V_f LED, hodnotu CTR (také I_f) a t_on a t_off časy (pro tranzistorové typy). Podporovány jsou standardní NPN tranzistory, NPN Darlington fáze a TRIAC. Pro CTR měření je MCU I/O pin, po dobu přibližně 3 ms, krátce přetížen. Datový list udává maximální výstupní proud 20 mA, pin je ale přetížen asi až na 100 mA. Proto je maximální hodnota CTR omezená a hodnoty nad 2000 % by měly být zpracovány s opatrností. Maximální
proud pro LED je 5 mA, což by mělo být zvažováno u typů TRIAC.
Typy relé (MOSFET zády k sobě) jsou rozpoznány jako tranzistor a Hodnota CTR pak nemá smysl. Typy s antiparalelními LED budou ignorovány.
K testování potřebujete jednoduchý adaptér s následujícími třemi testovacími body:
typu tranzistoru:
- anoda LED
- Katoda LED a emitoru propojená tranzistorem
- Sběratel z tranzistoru
typu TRIAC:
- anoda LED
- Katoda LED a MT1 připojená pomocí TRIAC
- MT1 od TRIAC
Adaptér můžete libovolně spojit se třemi testovacími piny testeru. Tester pak automaticky najde přiřazení pinů. Po spuštění připoj adaptér k testovacím pinům a krátce stiskni tlačítko.
Pokud byla opto-spojka nalezena, zobrazí tester typ a různé informace.
Pokud ji nenajde, zobrazí se na displeji „žádný“.
Blikající kurzor označuje, že se při příštím testu očekává stisknutí tlačítka.
Dvě krátké stisknutí ukončí jako obvykle test.

### 3.1.23. Test fotodiod ti umožní sledovat proud fotodiody. Nejprve se na několik vte-

řin zobrazí přiřazení testovacích kolíků, které lze předčasně ukončit stisknutím tlačítka. Poté tester přejde k pozorování proudu I_P s diodou v reverzním režimu, označeném "rev". Krátké stisknutí klávesy přepne provozní režim do přímého směru (fotočlánek), označeno "no". Další stisknutí klávesy přepne režim zpět. A jak jsi již jistě uhodl, dva krátké stisky tlačítka ukončí testovací funkci. Chceš-li fotodiodu otestovat, tak jí dočasně ručně zatemni nebo ji z různých vzdálenostech ozáří vhodným zdrojem světla. Méně světla vede k menšímu proudu a naopak. Je možné, že tester může zachytit nějaké EM rušení, které může vést k malému proudu, zvláště v režimu obráceného směru. To lze velmi dobře pozorovat, pokud není fotodioda připojena. Je třeba také zdůraznit, že fotodiody mají v režimu zpětného vychýlení temný proud. Upozornění: Nezkoušej solární články!
Zapojení testovacích vývodů:
Pin #1: | anoda
Pin #3: | katoda

### 3.1.24. Test servopohon˚u pro modely Tato funkce generuje PWM signál pro serva

pro výrobu modelů, která jsou ovládána s PWM 1–2 ms dlouhými pulsy.
Podporovány jsou typické PWM frekvence 50, 125, 250 a 333 Hz, s nastavitelnou délkou pulsu od 0,5 až do 2,5 ms.
Kromě toho existuje režim rozmítání pro impulzy 1 - 2ms s volitelnou rychlostí.
Šířku pulzu nastavíš pomocí otočného kodéru. Doleva pro kratší pulsy, doprava pro delší. Dlouhým stisknutím tlačítka se šířka pulzu nastaví na (střední polohu serva), to je na 1,5 ms. Krátkým stiskem tlačítka přepínáš mezi výběrem pulzu a frekvencí. (označené hvězdičkou). Ve volbě frekvence přepínáš rotačním kodérem mezi kmitočty.
Dlouhé stisknutí zapne nebo vypne „Sweep-mod“ | (označený „<->“).
Pokud je „Sweep-mod“ zapnutý, je délka impulsu nahrazena „Sweep“ časem, který lze změnit
pomocí otočného kodéru. | Funkci jako obvykle zastaví dvojitý stisk tlačítka.
Rozložení testovacích pinů:
Pin # 2: | PWM výstup (přes 680Ω odpor k omezení proudu)
Pin # 1 a # 3: uzemněny
Poznámka: Servo potřebuje svoje napájení.
Výrobce | Pin 1 | Pin 2 | Pin 3
Airtronics | PWM bílá/černá | Gnd černá | Vcc červená
Futaba | PWM bílá | Vcc červená | Gnd černá
hitec | PWM žlutá | Vcc červená | Gnd černá
JR Radios | PWM Oranžová | Vcc červená | Gnd hnědá
Tabulka 3.1. Rozložení pinů pro typické 3kolíkové servopohony
3.1.25. OneWire skenování zobrazuje ROM-kódy, všech připojených uživatelů. Informace o nastavení sběrnice OneWire naleznete v části „Sběrnice a rozhraní“ na straně 60. Při použití testovacích kolíků tester informuje o zapojení a vyčkávání, dokud není detekován externí pull-up odpor. To lze přeskočit stisknutím tlačítka.
Po každém stisknutí tlačítka tester vyhledá dalšího účastníka sběrnice a vydá jeho ROM-kód (v šestnáctkové soustavě). První část vydání je Rodinný kód a druhá sériové číslo.
Hodnota CRC je vynechána.
U Rodinovského kódu > = 0x80 (nastavený 7bit) se jedná o zákaznický kód, ve kterém jsou ty horní (levé) tři číslice sériového čísla jeho zákaznické ID.
Tester tě informuje, když našel posledního účastníka sběrnice, ale také o CRC chybách i o chybách sběrnice.
V případě posledního účastníka sběrnice nebo chyby sběrnice, můžeš spustit úplně nové skeno-
vání stisknutím tlačítka. | Zapojení je na straně 13.
Funkci ukončí, jako obvykle, dvě krátké stisknutí.

### 3.1.26. Snímaˇc teploty DS18B20, DS18S20 v tomto výběru lze použít tyto

teplotní OneWire senzory ke čtení teplot. Nastavení sběrnice je na stránce 60, viz část „Busse“. Při použití testovacích pinů tester informuje o zapojení a čeká dokud není detekován externí
pull-up odpor. | To lze přeskočit stisknutím tlačítka.
Po připojení DS18B20, DS18S20 jako jediného klienta na sběrnici, se stisknutím tlačítka začne číst teplota (která může trvat téměř sekundu).
Dlouhým stisknutím tlačítka volíš auto-mód (automatická aktualizace), která je signalizována hvězdičkou “*“ v prvním řádku.
Pro ukončení stiskni krátce dvakrát testovací tlačítko.
Připojení zkušebních pinů:
Probe #1: | Gnd
Probe #2: | DQ (Data)
Probe #3: | Vcc (Proud je ohraničen (přes 680Ω odpor)
Nezapomeň: Kromě toho je 4k7Ω odpor, mezi DQ a Vcc nutný.
Nápověda: | - Možnost pro DS18B20: zaokrouhlení na 0,1 °C/F | (UI_ROUND_DS18B20)
| - Možnost pro DS18S20: vysoké rozlišení | (DS18S20_HIGHRES)
- Funkce DS18B20 dokáže snímat také čidlo DS1822.

### 3.1.27. DHTxx senzory Pro čtení DHT11, DHT22 a kompatibilních snímačů teploty a

vlhkosti. Nejprve tester ukáže, že testovací kolíky jsou připojeny a čeká na externí pull-up odpor. Poté se zobrazí vybraný typ senzoru ( Standard: DHT11), který je načten, krátkým stisknutím testovacího tlačítka. Pokud je čtení úspěšné, vydá tester naměřené hodnoty, v případě chyby jen "-". Jedním dlouhým stisknutím změníš typ senzoru a dvě krátké stisknutí tlačítka ukončí funkci. Při změně typu senzoru máš možnost aktivovat automatický režim čtení (každou sekundu). Toto je za názvem senzoru označeno “*“. Podporované senzory:

DHT11: | DHT11, RHT01
DHT22: | DHT22, RHT03, AM2302
DHT21, RHT02, AM2301, HM2301 DHT33, RHT04, AM2303
DHT44, RHT05

Připojení zkušebních pinů:
Probe #1: | Gnd
Probe #2: | Data
Probe #3: | Vdd (Proud není ohraničen)

Mezi Data (#2) a Vdd (#3) je vyžadován externí pull-up odpor 4k7Ω!
Některé moduly již integrovaly 10kΩ pull-up odpor, který také s kratšími kabely dobře funguje. Poznámka:
Vnitřní 680Ω testovací odpor nelze k omezení proudu použít, kvůli aktuální spotřebě senzoru. Buďte opatrní, zkrat může poškodit MCU.

### 3.1.28. Pˇrevodník termoˇclánk˚u MAX6675/MAX31855

Oba MAX jsou termočlánkové převodníky s kompenzací studeného spoje a jsou řízeny prostřednictvím sběrnice SPI. MAX6675 je určen pouze pro termočlánky typu typu K, zatímco MAX31855 je k dispozici pro více typů. MAX31855 má provozní napětí 3,3 V, a proto vyžaduje převodníky úrovní.
Obsluha obou MAX je stejná. Stisknutím testovacího tlačítka se spustí měření a zobrazí se teplota. V případě chyb se místo toho zobrazí symbol “-“. Pro režim automatického odečítání (každou sekundu) stiskni a podrž testovací tlačítko déle. (označeno symbolem “*“ za názvem MAX). Dalším dlouhým stisknutím tlačítka se režim automatického čtení opět ukončí.
Dvě krátká stisknutí klávesy funkci ukončí.

### 3.1.29. Svítilna Jedná se o obecný spínací výstup pro ovládání dalšího obvodu, jako

je například LED světlo. Zkoušečka jednoduše přepíná výstup mezi nízkou a vysokou hodnotou při každém volání. Zatížení menší než 20 mA mohou být ovládány přímo.

### 3.1.30. Autotest Pokud jsi autotest spustil pomocí nabídky, vyzve tě tester ke zkrato-

vání zkušebních pinů a čeká, až je rozpozná.
V případě problémů můžeš čekání stiskem klávesy přerušit.
Autotest provádí každý test 5krát.
Krátké stisknutí tlačítka přeskočí aktuální test a dlouhý stisk tlačítka kompletní test. V testu # 4 musí být zkrat odstraněn. Tester v tomto kroku tak dlouho čeká.
Kroky testu jsou:
- interní referenční napětí T1 (v mV)
- T2 Srovnání odporů Rl (offset v mV)
- T3 Srovnání Rh odporů (offset v mV)
- T4 Odstraňte zkrat zkušebních pinů/kabelu
- Test těsnosti T5 pro zkušební piny s úrovní Gnd (napětí v mV)
- Test těsnosti T6 pro zkušební piny s úrovní Vcc (napětí v mV)

### 3.1.31. Samoˇcinné nastavení měří odpor a kapacitu měřicích kabelů, tzn. z desky s

obvody, vnitřního zapojení a měřicího kabelu jako součet k určení nulového posunu.
Také je určen vnitřní odpor pinů MCU portů v režimu pull-up a pull-down.
Pokud je srovnání přeskočeno nebo pokud jsou změřené hodnoty nepravděpodobné,
převezme tester výchozí hodnoty firmwaru.
Pokud běží všechno hladce, zobrazí se nové hodnoty, které ale nebudou automaticky do EEPROMu uloženy. (viz volbu „Uložit“).
Během měření kondenzátoru (při normálním vyhledávání součástí) se automaticky stane kompenzace napětí analogového komparátoru, pokut má Kondenzátor hodnotu mezi 100nF a 3,3µF. Kromě toho se současně měří offset vnitřní referenční hodnoty napětí.
Před provedením automatického ladění bys měl min. 3krát za sebou změřit filmový kondenzátor s kapacitou mezi 100nF a 3,3µF, aby bylo možné, uvedenou kompenzaci určit.
První měření je obvykle příliš nízké, druhé příliš vysoké a až od třetího měření dosáhneš
správnou hodnotu. | To je způsobeno offsetovými kompenzacemi.
V modelech s pevným kondenzátorem pro samo-ladění, je automatické seřízení pro měření kapacity, nahrazeno vlastní funkcí, která během testu provede se vlastní nastavení.
Zde nemusíš žádný filmový kondenzátor měřit.
Pokud se kompenzace kapacity mezi páry testovacích pinů příliš liší, můžeš v config.h přepnout na specifické posuny podle právě zapojených zkušebních kabelů-párů (CAP_MULTIOFFSET). To stejné platí i pro jejích odpor s (xR_MULTIOFFSET) viz stana 57.
Samo-ladění je do značné míry autotestu provozem a obsluhou podobné. Kroky seřízení jsou:
- kompenzace A1 pro interní referenční napětí a analogový komparátor
(pouze s pevným vyrovnávacím kondenzátorem)
- A2 Odolnost zkušebních pinů/kabelů v (10 mΩ)
- A3 Odstranění zkratu zkušebních pinů/kabelů
- vnitřní odpor A4 portových pinů pro Gnd (napětí přes RiL)
- A5 vnitřní odpor pinů portu pro Vcc (napětí přes RiH)
- kapacita testovacích pinů/kabelů A6 (v pF)

Povolené maximální hodnoty:
- zkušební kolík/kabel odpor | <1, 50 Ω (dva v sérii)
- Zkušební pin/kabel kapacita | <100 pF
- Vnitřní odpor IO pinu v nízkém režimu (RiL) | < 25 Ω
- Vnitřní odpor vývodu IO v režimu high (RiH) | < 29 Ω

Poznámka: Pokud se hodnoty odporu zkušebních kolíků příliš liší, je možný kontaktní problém.

Pamatuj: | Nastavení není kalibrace!
- Kalibrace je postup pro porovnání výsledků měření se sledovatelnými standardy a odchylky zaznamenat. Účelem je sledovat a odstraňovat časové odchylky.
- Nastavení je postup nastavit měřicího zařízení tak, aby dodržovalo svou danou přesnost a další parametry.

### 3.1.32. Uschovat/Použít Po vlastní úpravě můžeš pomocí této funkce aktualizovat

hodnoty nastavení, uložené v paměti EEPROM. Při příštím restartu testeru se tyto hodnoty (profil č. 1) pak automaticky načtou a použijí.
Pro usnadnění jsou k dispozici dva profily pro uložení nebo načtení, např. pro dvě různé sady měřicích kabelů. Pokud jsou dva příliš málo lze aktivovat třetí profil (UI_THREE_PROFILES). Myšlenka funkce manuálního ukládání je taková, že když dočasně změníš měřicí kabely a provedeš samočinné nastavení, tak máš po restartu opět hodnoty pro hlavní měřicí kabely. Jinak bys musel své standardní kabely znovu nastavit.
Volitelně můžeš, pomocí (UI_CHOOSE_PROFILE) při zapnutí testeru toto menu ukázat.
3.1.33. Ukázat hodnoty Tato funkce zobrazuje aktuální hodnoty nastavení. Použití externí reference napětí 2.5V je signalizováno „*“ po Vcc.

### 3.1.34. Znaková sada/symboly Tyto dvě položky nabídky vypisují kompletní sadu

znaků nebo symboly složek pro testovací účely. symboly pro testovací účely. Řádky/bloky začínají adresou (v šestnáctkové soustavě). z prvního znaku/symbolu v daném řádku/bloku. Následuje buď 8 znaků nebo tolik symbolů, kolik se jich vejde do bloku.

### 3.1.35. Vypnout Za předpokladu, že jsi tuto funkci přes SW_POWER_OFF strana 55

aktivoval, můžeš zde tester vypnout.

3.1.36. Konec ti umožní opustit nabídku, když jsi do ni náhodou/nechtě vstoupil.

Kapitola 4 | Detaily měření

### 4.1. Odpory

se měří dvakrát. tj. v obou směrech a hodnoty pak porovnány. Pokud jsou hodnoty příliš odlišné, předpokládá tester, že se jedná o dva odpory a ne o jeden.
V tomto případě se zobrazí dva odpory na stejných pinech ve tvaru „1 - 2 - 1“ a dvě hodnoty. Pro odpory menší než 10Ω se provádí další měření s vyšším rozlišením.
Ve výjimečných případech nemůže tester velmi malé odpory detekovat. Nejlépe pak jednoduše opakovat měření.
Pro testování potenciometrů nebo trimrů lze aktivovat přídavný výstup celkového odporu (Rt) a poměru obou odporů (R1 a R2) k celkovému odporu v % (SW_R_TRIMMER).
Pokud je aktivována volitelná kontrola standardních hodnot E (SW_R_E *) na stránce 52, porovná tester další menší a následující větší standardní hodnotu s změřeným odporem při zohlednění tolerance komponenty.
Existují dva výstupní režimy. V textovém režimu dává tester řadu E plus tolerance a vhodné standardní hodnoty. „-“ znamená, že žádná hodnota normy nepasuje. V režimu barevného kódu zobrazuje tester série E a barevný kód standardní hodnoty včetně inkoustové pásky pro toleranci. Barvy se mohou, podle použitého displeje lišit Pokud některá barva nesouhlasí, změň jednoduše hodnotu barvy (COLOR_CODE_*) v souboru color.h. Internetové vyhledávání „nástroje RGB565“ uvádí mnoho online nástrojů pro výběr hodnot barev RGB565.
Zejména pro SMD rezistory existuje další výstup pro kód EIA-96 (znamená E96 1%).

### 4.2. Kondenzátory

se měří třemi metodami. Velké kondenzátory > 47µF používají metodu cyklického nabíjení s 10ms dlouhými pulzy. Středně velké mezi 4,7µF a 47µF používají stejnou metodu ale nabíjecí pulsy jsou 1ms dlouhé.
Malé kondenzátory běží přes analogový komparátor. Tímto způsobem je optimalizována přesnost měření kapacit.
Změřené hodnoty velkých kondenzátorů vyžadují korekci. Bez korekce by byly hodnoty příliš vysoké. Domnívám se, že to způsobuje měřící metoda, protože analogově-digitální převod po nabití impulzem potřebuje jistý čas ve kterém kondenzátor část nabití, kvůli svodovým proudům, ztratí. Ztráty jsou samozřejmě také, samotným převodem z analogového na digitální. Nabíjení kondenzátoru tedy trvá déle a kapacita se zdá být vyšší. Pozdější měření samovybíjení se to snaží vyrovnat což se jen částečně povede. Korekční faktory CAP_FACTOR_SMALL, CAP_FACTOR_MID a CAP_FACTOR_LARGE jsou v config.h na stánce 57 tak zvolené, aby pasovaly pro většinu testerů. V některých případech však může být změna nutná. Přidána byla logika zabraňující detekci velkých kondenzátorů jako odpory. Odpory menší než10Ω budou dodatečně zkontrolovány na kapacitu. U kondenzátorů vyšších než 18nF se snaží tester měřit i ESR . Alternativně můžeš ale aktivovat starou metodu měření, která měří až od 180nF. Protože měření nepoužívá AC s určitou frekvencí, nečekej super přesné výsledky.
Použitá metoda může možní odpovídat měření při 1 kHz.
Pro zkoušku elektrolytických kondenzátorů je měření více než dostatečné.
U filmových kondenzátorů s malými hodnotami mohou nastat různé hodnoty v závislosti od frekvence taktu MCU.
Myslím, že by-to pan Fourier uměl vysvětlit.
Naměřená hodnota kapacity větší než 5 pF (včetně nulového posunu) se považuje za platnou. Nižší hodnoty jsou příliš nepřesné a mohou být způsobeny třeba jiným umístění měřicích kabelů.

Dalším měřením je svodová proudní ztráta pro kondenzátory vyšší než 4,7µF. Hodnota vydá poznámku k označení stavu Elko.
Z mých testů jsou typické hodnoty pro elkos:
- 10-220 µF | 1-3 µA
- 330-470 µF | 4-5 µA
- 470-820 µF | 4-7 µA
- > 1000 µF | 5-7 µA na 1000 µF

Pokud chceš znát také úbytek napětí v %, aktivuj funkci SW_C_VLOSS,
(pro kondenzátory > 50nF).
Volitelný test pro standardní hodnoty E je také k dispozici pro kondenzátory (SW_C_E_*) stránka 53, ale pouze v textovém režimu, protože existuje příliš mnoho různých barevných kódů pro kondenzátory.

### 4.3. tlumivky

Měření indukčnosti není příliš přesné a věci jako např. takt MCU a deska ovlivňují výsledek. Samotné měření je založeno na stanovení času mezi zapnutím elektřiny a dosažením určitého proudu. U velkých tlumivek se provádí měření nízkého proudu, a pro malé tlumivky vysoko proudové měření, které dočasně překračuje proudový limit MCU pinů po dobu až asi 25 mikrosekund. Při vyšetřování efektů MCU taktu jsem našel vzory v odchylkách, které lze použít pro kompenzaci. V závislosti na testeru může být nutné provést úpravu. V souboru inductance.c ve funkci MeasureInductor() je proměnná „Offset“kompenzace.
To je offset pro referenční napětí. Kladná hodnota snižuje indukčnost, a záporná ji zvyšuje. Kompenzace pro měření vysokého proudu je založena na taktu MCU a je rozdělena do tří časových pásem. Pro měření nízkého proudu je aktuálně pouze jednoduchá kompenzace, protože zde by-byly nutné další testy.
Pokud vidíš, ve srovnání se „správným“ LCR měřičem, velké rozdíly hodnoty offsetu, můžeš podle něj svůj tester upravit. Pokud chceš zkontrolovat hodnoty E-norm, ativuj přepínač SW_L_E_* v config.h na stránce 53 (pouze textový režim).
Poznámka:
- V případě neočekávaných naměřených hodnot opakuj měření.
- Měření indukce se provádí, jen když je její odpor menší než 2kΩ.

### 4.4. Vybití souˇcástek

Tester zkouší připojenou součástku před a během měření vybít. Pokud nelze nastavit na předem určenou nulovou hodnotu (CAP_DISCHARGED), zobrazí chybu označující testovací pin a zbytkové napětí.

Funkce vybíjení není založena na pevném časovém limitu, ale přizpůsobí se automaticky průběhu vybíjení. Tímto způsobem je baterie rychleji detekovaná a velké kondenzátory získávají více času k vybití. Pokud je velký elektrolytický kondenzátor rozpoznán jako baterie, zkus to znovu. V prostředí se spoustou elektrického rušení, může být nulová hodnota CAP_DISCHARGED s 2mV příliš nízká (v případě potřeby uprav na stránce 58). Zobrazené zbytkové napětí pomáhá najít optimální nulovou hodnotu.

### 4.5. ADC pˇrevzorkování

podporuje variabilní převzorkování (1 - 255).
Výchozí hodnota je 25 vzorků.
Můžeš se pokusit zvýšit přesnost testeru zvýšením hodnoty převzorkování. Avšak s vyšší hodnotou je nutný delší čas, tzn. měření se zpomalí.

### 4.6. Zobrazení výsledk˚u

Některá jména a zkratky byly změněny. Výstup některých komponent byl rozdělen na více stránek, pokud nemá LCD modul dostatek řádků.

U jediné diody je výsledek Vf měření s nízkým zkušebním proudem (10µA) zobrazen v závor-
kách, pokud je hodnota měření pod 250 mV. | To ukazuje na germaniovou diodu.
Většina datových listů germaniových diod udává pro Vf měřicí proud 0,1 mA.
Bohužel tester tento měřicí proud nepodporuje. Při vyšších proudech je Vf kolem 0,7 V, což ztěžuje rozlišení od křemíkových diod.
Tester ukáže svodový proud I_R pro diodu nebo I_CEO pro bipolární tranzistor pokud je vyšší než 50nA.
Germaniové tranzistory mají svodový proud v rozmezí několika µA až asi 500µA. Germaniové diody mají obvykle jen málo µA.
U některých součástí se zobrazí hodnota kapacity. Je-li kapacita pod 5pF nebo měření selhalo, je na výstupu 0pF.
Pokud je nalezen (ochuzovací typ) FET se symetrickým odtokem a zdrojem, ukazuje přiřazení pinů „x“ místo „D“ nebo „S“, protože jsou funkčně totožné a nejdou v testeru rozlišit.
V takovém případě vyhledej podrobnosti o přiřazení pinů v datovém listu.
Triakové přiřazení pinů je označeno:
„G“, „1“ a „2“. | „1“ je MT1 | a „2“ je MT2.
Pro UJT, pokud je detekce aktivovaná, je:
„1“ pro B1, „2“ pro B2 a „E“ pro emitor.
Pokud byla aktivována funkce „Fancy Pinout“ (SW_SYMBOLS), zobrazí se symbol součástky a jeho položení na zkušebních pinech pro 3pinové polovodiče.
Není li na displeji dostatek místa, bude výstup ikony přeskočen.

### 4.7. Dodateˇcné pokyny

bipolární tranzistory
Malé písmeno za hFE-hodnotou zobrazuje typ zkoušecího prostředí, použitého k měření:
- e: | emitorové
- c: | kolektorové
Pokud jsi aktivoval výstup z testovacího proudu hFE (SW_HFE_CURRENT), pak tester ukazuje I_C pro obvod emitoru a I_E pro kolektorový obvod.
Při testu na diody je Vf měřen za prvé s Rh (vysokým zkoušecím proudem) a za druhé s Rl (nízkým zkoušecím proudem). Výchozí funkce pro bipolární tranzistory interpoluje s obou Vf hodnot V_BE závisle na hFE pro virtuální zkoušecí proud. Tím lze získat praxi blízké hodnoty, protože V_BE malého signálového tranzistoru je měřen jiným proudem nežli u výkonového tranzistoru.
U bipolárního tranzistoru s bázovým emitorovým odporem je odpor zobrazen. Nezapomeň, že má B-E odpor vliv na V_BE i na hFE.
Pokud má tranzistor navíc ochrannou diodu, může být rozpoznán jako tranzistor nebo jako dvě diody, v závislosti na hodnotě odporu báze-emitor.
v druhém případě jsou zobrazeny dvě diody plus odpor s uvedením možného tranzistoru. Bohužel nízký odpor báze-emitor brání jednoznačné detekci jako tranzistor.
Dalším zvláštním případem je bipolární tranzistor s ochrannou diodou umístěnou na stejném substrátu.
Integrovaný PN přechod vytváří parazitní druhý tranzistor. NPN dostane parazitní PNP a naopak.
Pokud je takový tranzistor detekován, je po specifikaci typu označen znakem „+“.
u šottky-tranzistoru (Schottky-clamped BJT) je schotky-dioda mezi bázi a kolektorem incl. V_f ukázána, pokud je to aktivováno s (SW_SCHOTTKY_BJT) na straně 51. Nezapomeň, že je I_CEO u šottky-tranzistoru zvýšen.
Nápověda: Vysoký hFE Darlingtonových tranzistorů může vést k nesprávným hodnotám I_CEO ve spojení s EMC.
- Pokud máš podezření na problém s teplotou BJT, otestuj jej za studena, zahřej ho (pájkou nebo horkým vzduchem) a po zahřátí znovu otestuj.

TRIAKY s jsou provozovány ve třech nebo čtyřech režimech, známých také jako kvadranty. Obvykle se některé parametry liší v závislosti na kvadrantu, např. spouštěcí proud I_GT. V některých případech se stává, že zkušební proud Tester je dostatečný pro spuštění TRIACu v jednom kvadrantu, ale ne v jiném. Protože tester potřebuje dva testovací běhy, aby získal rozložení pinů pro MT1 a MT2, nemůže tester v takových případech připojení rozlišit, tím je možné, že jsou označeny obráceně.
Některé TRIAKY mohou být testerem spuštěny, ale mají vysoký udržující proud (I_H), čímž je nelze správně rozpoznat. Pokud je spouštěcí proud je pro tester příliš vysoký, je označen jako odpor.
Je také možné, že ho tester zozpozná jako NPN s parazitním BJT (NPN+) s báze-emitor odporem.
CLD Test diod detekuje CLD (Current Limiting Diode) jako normální diodu a vydává její aktuální I_F jako svodový proud.
- Všimni si, že jsou u CLD anoda a katoda obráceny oproti normální diodě.
- Samostatná CLD detekce je obtížná, protože svodový proud germania nebo výkonné Šottkyho diody leží v rozsahu I_F (od přibližně 33µA).
- Pokud má dioda neobvyklý V_f, neobvykle nízký V_f při nízkém proudovém testu (druhá hodnota v závorce) a nelze měřit žádnou kapacitu, pak je to pravděpodobně CLD.

Nepodporované komponenty všechny polovodiče, které vyžadují vysoký řídicí proud, nelze rozpoznat, protože má tester max. asi 7 mA spínací proud. Tester také dodává pouze 5V, což např. nestačí na DIAC s V_BO od 20-200 V.

Zjednání nápravy u některých testerů.
Jestli tvůj tester ukazuje následovný problém, můžeš ho takto zkusit opravit.
-hFE moc vysoký
Problém:
U kolektorového okruhu s Rl jako bázovým odporem je z neznámého důvodu měřeno moc nízké bázové napětí. Tímto vypadá bázový proud také nižší a způsobí vysokou hFE hodnotu.
Postižený tester:
Hiland M644
Náprava:
Aktivuj NO_HFE_C_RL v config.h! Viz na stránce 53.
- Tester s řídicí jednotkou MCU SCT15L104W.
Problém:
Tester se po prvním vyhledání součásti náhle vypne. Je pravděpodobně způsobeno různými úrovněmi napětí (SCT15L104W má 3,3 V, ATmega 5 V)

Dotčené testery:
T7-H, pravděpodobně i další modely řady TC-1.
Náprava:
Aktivuj PASSIVE_POWER_CTRL v config.h!

Známé problémy Úložiště nebo super-kondenzátor, např. Řada Panasonic NF je detekován jako dioda nebo dvě antiparalelní diody.
Měření kapacity nemůže určit použitelnou hodnotu.
- Při použití spínacího zdroje nebo DC-DC převodníku pro napájení, vydá někdy tester omylem Elko kolem 50µF, ačkoli není žádná součástka připojena.
- ESR může pracovat s kondenzátory s 180 - 220nF v závislosti na MCU taktu variovat.
- Problém s měřením ESR elektrolytických kondenzátorů s nízkým ESR a pevným elektrolytem.

### 4.8. užiteˇcné odkazy

[10] Slovenské fórum
https://svetelektro.com/phpbb/?w3=dmlld3RvcGljLnBocD9mPTE4JnQ9MzAyODU=-Všetko zo sveta elektroniky
[11] Německé fórum
https://www.mikrocontroller.net/topic/248078 Hlavní řeč je němčina, anglicky je ale také ok.
[12] Anglické fórum
https://www.eevblog.com/forum/testgear/$20-lcr-esr-transistor-checker-project/ Jen anglicky.
[13] Ruské fórum
https://vrtp.ru/index.php?showtopic=16451
- Infos zu verschiedenen Clonen, wie Bilder, Schaltpläne und Firmware
[14] Ruské webové stránky (od indman@EEVblog) https://disk.yandex.ru/d/yW8xa5NJgUo5z
- Informace o různých klonech, jako jsou obrázky, schémata a firmware
[15] Manuál plus div. soubory pro WinAVR (od indman@EEVblog) https://drive.google.com/file/d/1-IJA8uTcsCA_6SYHEuMydjfS2vNgmwdH/edit
[16] Aktální k-Firmware
https://github.com/kubi48/TransistorTester-source
[17] Aktuální dokumentace pro k-Firmware https://github.com/kubi48/TransistorTester-documentation

### 4.9. Zmˇeny firmwaru

Přečti si Kapitolu 9 od stránky 90.

Kapitola 5 | Dálkové ovládání

### 5.1. Pˇríkazy dálkového ovládání

Když tester příkaz přijme, odpoví konkrétními údaji nebo jeden z následujících standardních textů:

### 5.1.1. ERR - neznámý příkaz

- není podporován v aktuálním kontextu komponenty
- Přetečení vyrovnávací paměti

### 5.1.2. OK - příkaz byl proveden

(provedení některých příkazů nějakou dobu trvá)

### 5.1.3. N/A - Informace/hodnota nejsou k dispozici

Odpovědi s daty nikdy nezačínají žádným z nadstandardních textů aby se vyhnulo možné dvojznačnosti

### 5.2. Basiskommandos

### 5.2.1. VER - vrací verzi firmwaru

- ověření připojení a určení sady příkazů na základě verze příklad odpovědi: “1,33m“

### 5.2.2. OFF - vypne tester

- Tester před vypnutím odpoví “OK“
příklad odpovědi: „OK“<tester se vypne>

### 5.3. Testkommandos

### 5.3.1. PROBE - hledá část a přeskočí všechny pauzy pro zadání uživatele

- Tester po ukončení vyhledávání odpoví “OK“
vzorová odpověď: <uplyne nějaký čas pro sondování> “OK“

### 5.3.2. COMP - vrací ID typu součásti

- ID viz COMP_* in common.h
- Příklad odpovědi pro BJT:„30“

### 5.3.3. MSG - vrací chybovou zprávu

- pouze v případě, že došlo k chybě (COMP: 1)
- Odpověď může záviset na jazyce uživatelského rozhraní příklad odpověď: „Baterie? 1:1500 mV“

### 5.3.4. QTY - vrací počet nalezených komponent

příklad odpověď pro BJT:„1“

### 5.3.5. NEXT - vyber druhou komponentu

- pouze pokud byly nalezeny dvě složky (POČET:2) příklad odpověď: „OK“
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

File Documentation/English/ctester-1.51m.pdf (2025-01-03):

? =

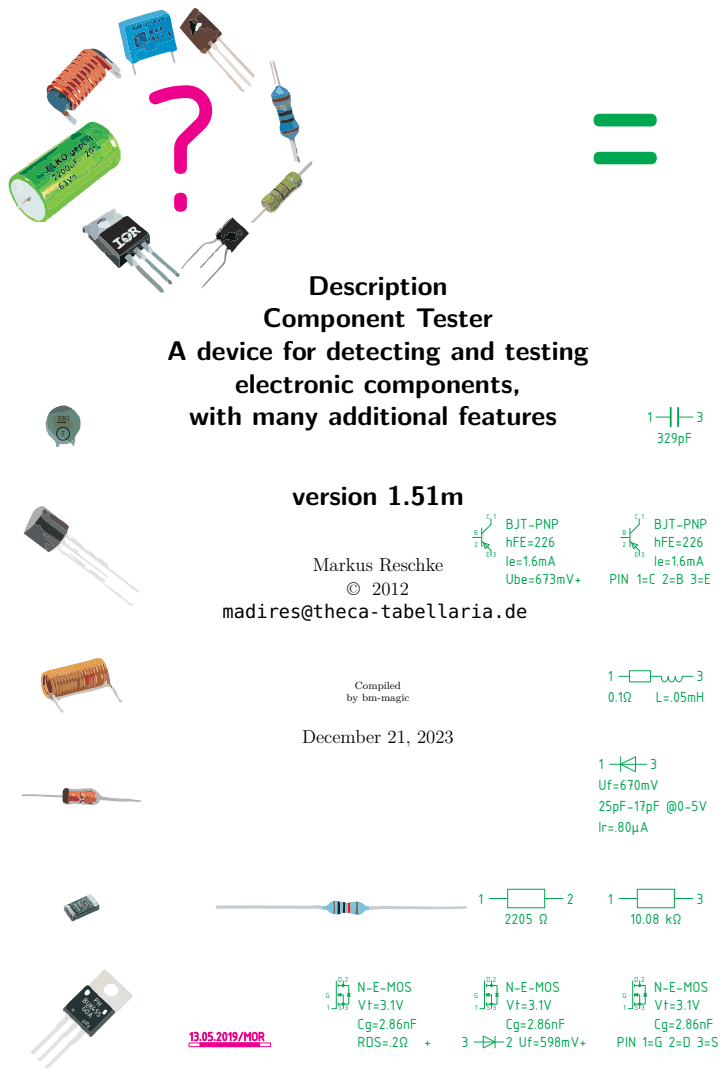
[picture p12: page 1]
13.05.2019/MOR; N-E-MOS Vt=3.1V Cg=2.86nF; RDS=.2; BJT-PNP hFE=226 Ie=1.6mA Ube=673mV+; BJT-PNP hFE=226 Ie=1.6mA PIN 1=C 2=B 3=E; N-E-MOS Vt=3.1V Cg=2.86nF PIN 1=G 2=D 3=S; S3 BUK455; PH GOA; Description Component Tester; version 1.51m; Markus Reschke © 2012

A device for detecting and testing
electronic components,
with many additional features

madires@theca-tabellaria.de

Compiled
by bm-magic
December 21, 2023

## Contents
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

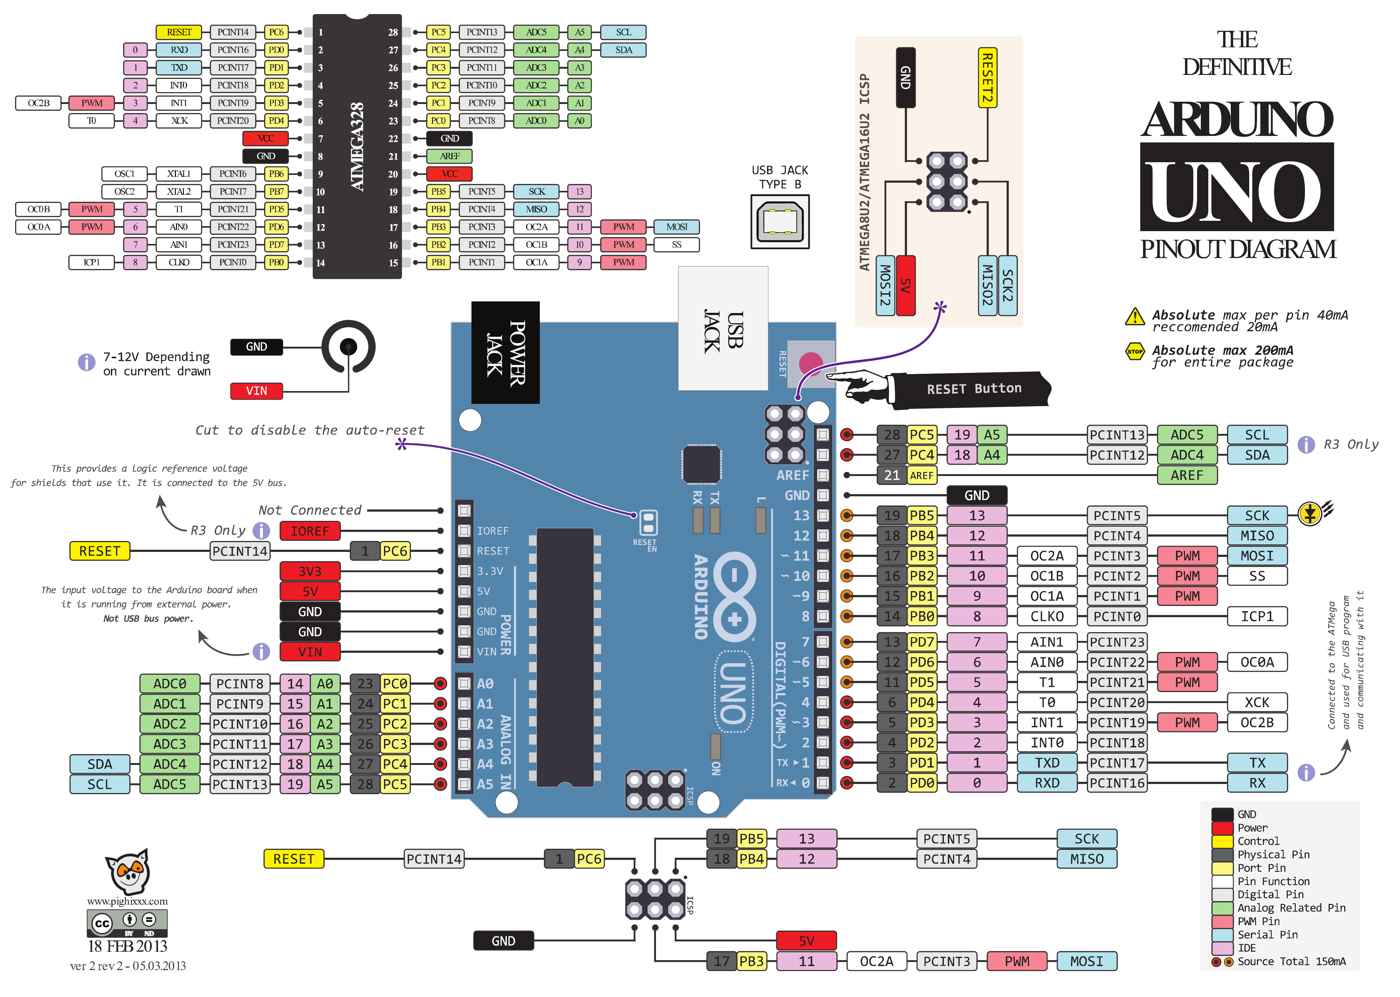
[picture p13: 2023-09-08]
ComponentTester-1.54m/Pinout_of_ARDUINO_Board_and_ATMega328PU.png

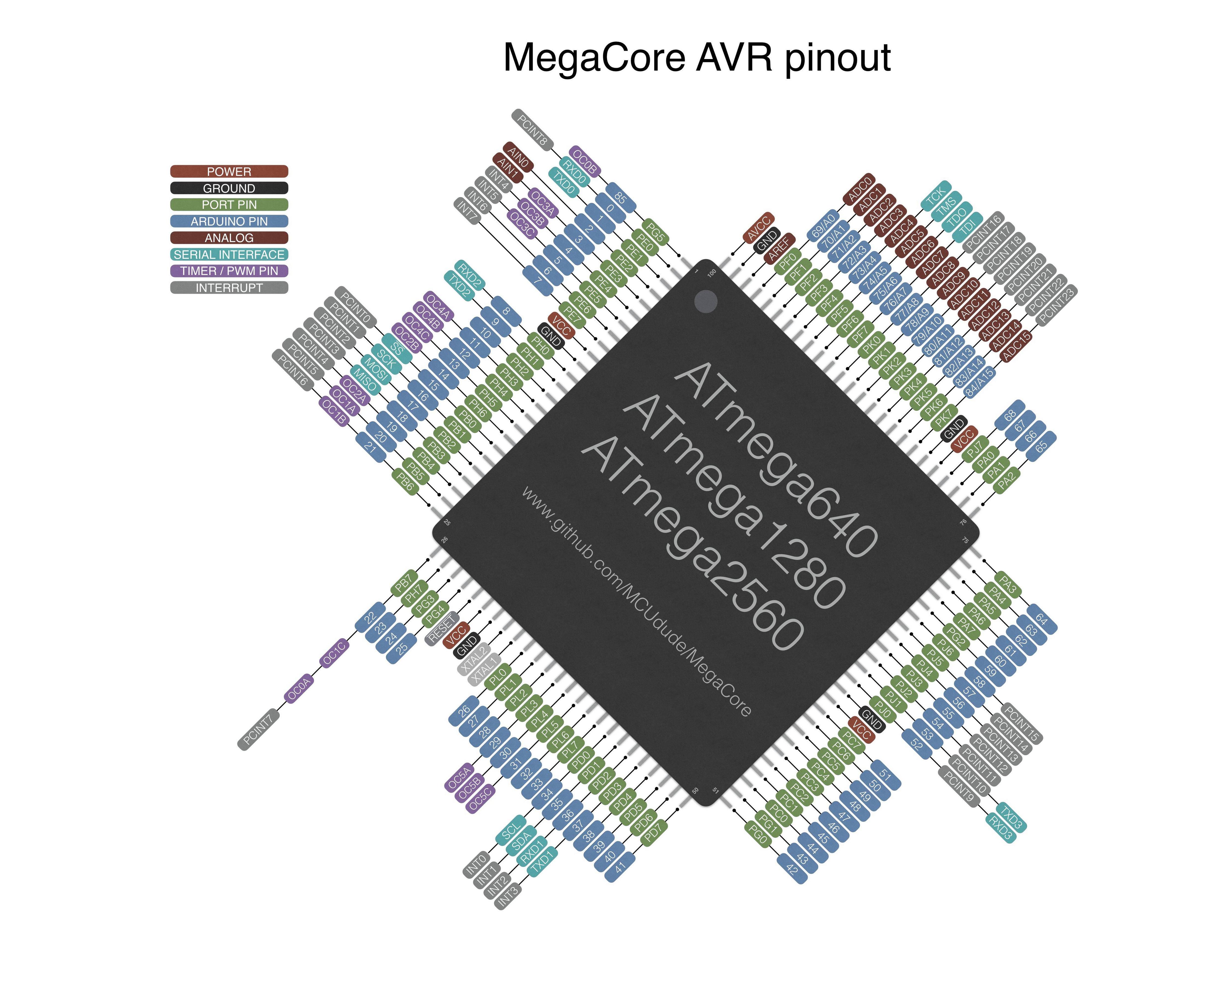
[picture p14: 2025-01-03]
ComponentTester-1.54m/atmega2560pinout.jpeg

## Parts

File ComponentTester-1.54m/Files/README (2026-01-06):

------------------------------------------------------------------------------

            ReadMe for the Component Tester firmware (m-firmware)

        (c) 2012-2024 by Markus Reschke (madires@theca-tabellaria.de)

------------------------------------------------------------------------------

Last edit:   2024-12-13
For version: 1.54m

Content
  - About
  - Safety Advice
  - License
    - Additional Disclaimer
  - What's different?
  - Source Code
  - Supported Hardware
  - Building the Firmware
  - Busses & Interfaces
    - I2C/SPI
    - TTL Serial
    - OneWire
  - Displays
    - Fonts and Symbols
    - HD44780
    - ILI9163
    - ILI9341/ILI9342
    - ILI9481
    - ILI9486
    - ILI9488
    - PCD8544
    - PCF8814
    - SH1106
    - SSD1306
    - ST7036
    - ST7565R
    - ST7735
    - ST7920
    - STE2007/HX1230
    - VT100 Terminal
  - Test push button and other input options
    - Test Key
    - Rotary Encoder
    - Increase/Decrease Buttons
    - Touch Screen
  - User Interface
    - Buzzer
  - Communication with PC
    - Serial Output
    - Automation
    - VT100 Output
  - Power-On
  - Probing
  - Battery Monitoring
  - Power Off
  - Menu
    - PWM Tool
    - Square Wave Generator
    - Zener Tool
    - Logic Probe
    - Continuity Check
    - ESR Tool
    - Capacitor Leakage Check
    - R/C/L Monitors
    - LC Meter
    - Frequency Counter
      - Basic Counter
      - Extended Counter
    - Ring Tester
    - Event Counter
      - Trigger Output
    - Rotary Encoder
    - Contrast
    - IR RC Detector/Decoder
    - IR RC Transmitter
    - Opto Coupler Tool
    - Photodiode Check
    - Diode/LED Quick-Check
    - Servo Check
    - OneWire Scan
    - DS18B20/DS18S20 Temperature Sensors
    - DHTxx Temperature & Humidity Sensors
    - MAX6675/MAX31855 Thermocouple Converters
    - BH1750 Ambient Light Sensor
    - INA226 Power Monitor
    - Flashlight
    - Voltmeter 0-5 V DC
    - Self Test
    - Self Adjustment
    - Save/Load
    - Show Values
    - Font/Symbols
    - Power Off
    - Exit
  - Resistors
  - Capacitors
  - Inductors
  - Discharging Components
  - ADC Oversampling
  - Displaying Results
    - Additional Hints
      - BJTs
      - FETs
      - TRIACs
      - CLDs
      - SUS/SBSs
  - Unsupported Components
  - Workarounds for some Testers
  - Known Issues
  - Support
  - Change Log
  - Remote Commands
  - Helpful Links
  - References

* About

The Component Tester is based on the project of Markus Frejek [1&2] and the
successor of Karl-Heinz Kübbeler [3&4]. It's an alternative firmware for
Karl-Heinz' current Transistortester circuit and comes with several changes in
the user interface and the methods used for probing and measuring. It also
offers a few additional features. While Karl-Heinz provides an official
release supporting also older ATmega MCUs, this firmware does require an
ATmega with 32 kB flash at least.

Hints:
- Run the self-adjustment for a new tester or if you've done any
  modifications, like a firmware update or changing probe leads.
- The Component Tester isn't an LCR meter. It can measure capacitance and
  inductance within some limits.

* Safety Advice

The Component Tester is no DMM! It's a simple tester for components capable
of measuring several things. The probes aren't protected in any way and
won't survive higher voltages than 5 V. Don't use the tester for live circuits!
Just use it for unsoldered electronic components! If you test a capacitor make
sure it's discharged before connecting the probes. This isn't just the Safety
Sally, your life may be at risk if you connect the probes to a live circuit
or a power supply (or even mains). 

* License

The original author hasn't provided any information about the licence under
which the firmware is distributed. He only stated that it's open source and
any commercial user should contact him. Unfortunately we (Karl-Heinz and I)
haven't found any way to contact him. To remedy this problem I've chosen an
open source license at 2016-01-01, after giving the original author more than
sufficient time to tell us his wishes regarding the license. Since the source
code of this firmware version is a major rewrite with tons of new code and
features, I think that this approach is justified.

Licensed under the EUPL v. 1.2

+ Additional Disclaimer

Product or company names are possibly trademarks of the respective owners.

* What's different?

Karl-Heinz has done a really great documentation of the tester. I recommend
to read it. Therefore I'll tell you just about the major differences to the
k-firmware:

- user interface
  + No worries! ;)
  + touch screen
  + remote commands
  + two sets of adjustment values
- adaptive component discharge function
- resistance measurement
  + dedicated method for resistances <10 Ohms (instead of using ESR check)
- capacitance measurement
  + starts at 5 pF
  + additional method for caps from 4.7 µF up to 47 µF
  + correction/compensation method
- no SamplingADC() for very low capacitance or inductance
- diodes
  + detection logic
- BJTs
  + V_f is interpolated for a more suitable (virtual) I_b based on hFE
  + detection of Germanium BJTs with high leakage current
  + detection of Schottky-clamped BJTs
- JFETs
  + detection of JFETs with very low I_DSS
- TRIACs
  + detection of MT1 and MT2
- IR RC detector and decoder
- IR RC transmitter
- opto coupler check
- RC servo check
- OneWire (plus sensors DS18B20 and DS18S20)
- DHTxx Sensors
- event counter
- ring tester (LOPT/FBT tester)
- logic probe
- continuity check
- MAX6675/MAX31855 thermocouple converters
- BH1750 Ambient Light Sensor
- INA226 Power Monitor
- flashlight / general purpose switched output
- structured source code
- simple frameworks for displays and data busses
- some more I couldn't think of right now

There are more details in the sections below.

* Source Code

The first m-firmware was based on Karl-Heinz' source code. A lot of cleaning
up was done, like more remarks, renamed variables, re-structured functions,
large functions splitted up into several smaller ones and what have you. After
that the m-firmware moved on to become an independent version. For example,
simple frameworks for displays and interface busses were added. I hope the
code is easy to read and maintain.

You can download the lastest firmware from following sites:
- https://github.com/madires/Transistortester-Warehouse
- https://github.com/kubi48/TransistorTester-source/tree/master/Markus
  (https://github.com/Mikrocontroller-net/transistortester/tree/master/Software/Markus)

* Supported Hardware

The firmware runs on all testers which are compatible with the standard
circuit shown in Karl-Heinz' documentation and which use one of the
following MCUs:
  - ATmega 328
  - ATmega 324/644/1284
  - ATmega 640/1280/2560

You can customize pin assigments if required. The display may be a character
or graphic type (monochrome or color). Please see section 'Displays' for
supported controllers.

Following hardware options are supported:

  user interface
  - rotary encoder
  - additional push buttons (in/decrease)
  - touch screen
  - serial interface (TTL, RS232, USB-serial adpater) 
  - buzzer

  enhancements
  - external 2.5 V voltage reference
  - fixed adjustment cap
  - protection relay for discharging caps

  additional checks and measurements
  - Zener check / measurement of external voltage < 50 V
  - basic frequency counter
  - extended frequency counter
    with prescaler and crystal oscillators for low and high frequencies
  - fixed IR RC receiver
  - LC meter
  - ring tester (LOPT/FBT tester)
  - logic probe
  - fixed DS18B20/DS18S20 temperature sensors
  - MAX6675/MAX31855 thermocouple converters
  - BH1750 ambient light sensor
  - INA226 Power Monitor
  - flashlight / general purpose switched output

* Building the Firmware

First edit the Makefile to specify your MCU model, frequency, oscilator
type and programmer settings. All other settings are moved to a global
config.h and a MCU specific config-<MCU>.h. The file 'Clones' lists
settings for various tester versions/clones. If you have a tester not listed,
please email the settings to the author to help other users.

In config.h please choose hardware and software options, the language for the
UI, and change any default values if required. All settings and values are
explained in the file, so I won't discuss them here in depth. 

Hardware options:
- additional keys
  - rotary encoder
  - increase/decrease push buttons
  - touch screen
- 2.5 V voltage reference
- relay based cap discharger
- Zener voltage measurement
- frequency counter (basic and extendend version)
- event counter
- LC Meter
- ring tester (LOPT/FBT tester)
- IR detector/decoder for remote controls
  (fixed IR receiver module)
- fixed cap for self-adjustment of voltage offsets
- SPI bus (bit-bang and hardware)
- I2C bus (bit-bang and hardware)
- TTL Serial (bit-bang and hardware)
- OneWire bus (bit-bang)
- ...

The external 2.5 V voltage reference should be only enabled if it's at least
10 times more precise than the voltage regulator. Otherwise it would make
the results worse. If you're using an MCP1702 with a typical tolerance of
0.4 % as voltage regulator you really don't need a 2.5 V voltage reference.

And of course the software options:
- PWM generator (2 variants)
- inductance measurement
- ESR measurement and in-circuit ESR measurement
- check for rotary encoders
- squarewave signal generator (requires additional keys)
- IR detector/decoder for remote controls
  (IR receiver module connected to probes)
- IR RC transmitter (IR LED with driver transistor)
- check for opto couplers
- servo check (requires additional keys, display with >2 lines)
- detection of UJTs
- capacitor leakage check
- DS18B20/DS18S20 temperature sensors
- color coding for probes (requires color graphics display)
- output of components found also via TTL serial, e.g. to a PC
- remote commands for automation via TTL serial
- output of reverse hFE for BJTs
- DHT11/22 temperature and humidity sensor
- ...

Please choose the options carefully to match your needs and the MCU's
ressources, i.e. RAM, EEPROM and flash memory. If the firmware exceeds the
MCU's flash size, try to disable some options you don't need.

Available UI languages:
- Brazilian Portuguese
  - provided by wandows@EEVblog
- Czech
  - provided by Kapa
  - font based on ISO 8859-1
- Czech 2
  - provided by Bohu
  - font with Czech characters based on ISO 8859-2
- Danish
  - provided by glenndk@mikrocontroller.net
  - needs minor changes in the font
- English (default)
- French
  - provided by moimem@EEVblog
- German
- Italian
  - provided by Gino_09@EEVblog
- Polish
  - provided by Szpila
- Romanian
  - provided by Dumidan@EEVblog
- Russian
  - provided by indman@EEVblog
  - font with cyrillic characters based on Windows-1251
- Russian 2
  - provided by hapless@@EEVblog
  - font with cyrillic characters based on Windows-1251
  - alternative text 
- Spanish
  - provided by pepe10000@EEVblog

For number values a decimal fraction is indicated by a dot, but you can change
that to a comma if you like by enabling the corresponding setting.

For MCU specific settings, like pin assignments and display, edit 
config_<MCU>.h:
- ATmega 328                config_328.h
- ATmega 324/644/1284       config_644.h
- ATmega 640/1280/2560      config_1280.h

The display has to provide 2 lines with 16 characters each, at least. For
graphic displays select a font which is small enough to match the
requirements.

After editing the Makefile, config.h and config-<MCU>.h please run 'make' or
whatever toolchain you have to compile the firmware. This will create two
files:
- ComponentTester.hex   firmware in Intel hex format
- ComponentTester.eep   EEPROM data in Intel hex format

The firmware will be written to the Flash and the EEPROM data to the EEPROM.
The data contains two sets of default adjustment values, texts and tables.
When you update the firmware and like to keep the old adjustment values in the
EEPROM you can enable DATA_FLASH in config.h to move texts and tables into the
firmware. In that case only the firmwmare needs be programed, the EEPROM stays
untouched.

The Makefile provides following additional targets:
- clean     to delete all object and firmware files
- fuses     to set the ATmega's fuse bits (via avrdude)
- upload    to program the firmware and EEPROM data (via avrdude)
- prog_fw   to program only the firmware (via avrdude)
- prog_ee   to program only the EEPROM data (via avrdude)

Hints on compiler/linker optimizations:
- There are multiple lines of CFLAGS and LDFLAGS with compiler/linker options
  in the Makefile. You'll find a few lines commented out which contain
  additional optimization options to reduce the firmware size. Those are not
  supported by all compilers. So please feel free to experiment. ;)

Hints on special settings in the Makefile:
- In a linux/unix environment you can enable OPTIMIZE_VECTORS to optimize the
  interrupt vector table to reduce the firmware size.

* Busses & Interfaces

+ I2C/SPI

Some displays and other hardware might need I2C or SPI for connecting to the
MCU. Therefore the firmware includes drivers for both bus systems. To cope
with different pin assignments of the various testers the bus drivers support
bit-bang and hardware operation modes. The bit-bang mode can use any IO pins
on the same port, while the hardware mode uses the dedicated bus pins of the
MCU. The drawback of the bit-bang mode is its speed, it's slow. The hardware
mode is much faster. You can spot the difference in speeds easily with a high
resolution color LCD module.

For ATmega 328 based testers the bit-bang mode is needed in most cases due to
the circuit. The ATmega 324/644/1284 has more I/O pins and the different pin
assignment for the circuit allows to use the dedicated bus pins for the
hardware mode.

Since SPI or I2C are primarily used by the display module, they can be
configured in the display section of config-<MCU>.h. Alternatively you can
also enable I2C and SPI in config.h, and set ports and pins in dedicated
sections in config-<MCU>.h (look for I2C_PORT or SPI_PORT).

If you select bit-bang SPI and enable the read mode (SPI_RW) please make sure
to set also SPI_PIN and SPI_MISO. See the SPI section in config-<MCU>.h for
an example.

When connecting multiple ICs to the SPI bus, each IC needs to be controlled by
a dediacted /CS signal. Only in the case of one single IC on the SPI bus that
IC's /CS can be tied to ground.

Hint for bit-bang SPI:
- If, in the case of a high MCU clock rate, the SPI bus becomes too fast for
  the display please add the option 'SPI_SLOWDOWN' to the display setup in
  config-<MCU>.h, or enable it in config.h.

+ TTL Serial

The tester can also provide a TTL serial interface. In case it's used for
communication with a PC it should be combined with a USB to TTL serial
converter or a classic RS-232 driver. The firmware makes use of the MCU's
hardware UART or a bit-bang software UART. The TTL serial interface is enabled
in config.h (see section "Busses") and the port pins are defined in
config-<MCU>.h (look for SERIAL_PORT).

The software UART has the drawback that the TX line will not stay high all
the time when idle. This happens because of the way the MCU port pins are
driven. To remedy this the port pin driving would have to be changed causing
a larger firmware. But this issue doesn't seem to cause any trouble with most
USB to TTL serial converters. In case you see any problem try to add a pull-up
resistor (10-100 kOhms) to the TX pin to keep the signal at high level when
idle.

The default setting for the TTL serial is 9600 8N1:
  - 9600 bps
  - 8 data bits
  - no parity
  - 1 stop bit
  - no flow control

+ OneWire

Another supported bus is OneWire which can use either the probes/test pins (
ONEWIRE_PROBES) or a dedicated I/O pin (ONEWIRE_IO_PIN). The driver is designed
for standard bus speed and externally powered clients (not parasitic-
powered).

Pin assignment for probes:
  Probe #1:  Gnd
  Probe #2:  DQ (data)
  Probe #3:  Vcc (current limited by 680 ohms resistor)
  An external pull-up resistor of 4.7 kOhms between DQ and Vcc is required!

Related tools which require a single client to be connected to the bus can
optionally output the client's ROM code (ONEWIRE_READ_ROM). In case of a CRC
error or if multiple clients are connected the output will be '-'. When the
ROM code is zero there's a read issue. Otherwise the first part of the ROM
code shows the device family and the second part the serial number.

* Displays

At the moment following display controllers are supported:
- HD44780 (character display, 2-4 lines with 16-20 characters)
- ILI9163 (color graphic display 128x160)
- ILI9341/ILI9342 (color graphic display 240x320 or 320x240)
- ILI9481 (color graphic display 320x480, partly untested)
- ILI9486 (color graphic display 320x480, partly untested)
- ILI9488 (color graphic display 320x480, partly untested)
- PCD8544 (graphic display 84x48)
- PCF8814 (graphic display 96x65)
- SH1106 (graphic display 128x64)
- SSD1306 (graphic display 128x64)
- ST7036 (character display, 3 lines with 16 characters, untested)
- ST7565R (graphic display 128x64)
- ST7735 (color graphic display 128x160)
- ST7920 (graphic display up to 256x64)
- STE2007/HX1230 (graphic display 96x68)
- VT100 Terminal (via serial interface)

Take care about the LCD's supply voltage and logic levels! Use a level shifter
if required. A simple level shifter with in-series resistors relying on the
display controller's internal clamping diodes may work, but only for low speed
busses like bit-bang SPI. Therefore I recommend to use proper level shifter
ICs.

To save a few IO pins you can hardwire the /CS and /RES lines via pull-up/down
resistors for nearly all displays and comment out the corresponding IO pins in
the configuration (config_<MCU>.h) as long as the display is the only device
on the interface bus.

If the display doesn't show anything after double checking the wiring, please
try different contrast settings (config_<MCU>.h). 

Most graphic displays provide settings to change the image orientation, e.g.
for rotating the image by 90° and mirroring the image horizontally or
vertically. That way the image can be adjusted for each tester as needed.
For color graphic displays additional settings are available. In the normal
color mode the tester uses several colors which can be changed by editing
the colors.h file. By commenting out LCD_COLOR the two-color mode is enabled
and the pen color will be COLOR_PEN, while the background color is set to
COLOR_BACKGROUND. In case the RGB base colors red and blue are reversed
enable LCD_BGR to swap the red and blue color channels. Some displays have
reversed RGB sub-pixels and the display controller doesn't know about that.

Hint for ATmega 328:
If you connect a rotary encoder to PD2/PD3, please connect the display's /CS to
PD5 and set LCD_CS in config_328.h (applies to graphic displays). Otherwise
the rotary encoder would screw up the display by interfering with the data bus.

+ Fonts and Symbols

The display configuration includes also a font and optionally a set of
component symbols. Suitable fonts and symbols are listed for each display in
config_<MCU>.h. For a graphic display you can choose from multiple fonts in
most cases. The symbols are activated by the SW_SYMBOLS switch in config.h.

If you prefer the old style of component symbols you can still use them by
changing the symbols setting to SYMBOLS_<size>_OLD_<format>.h.

For test purposes you can enable a menu function to show all font characters (
SW_FONT_TEST) or all component symbols (SW_SYMBOL_TEST).

Hint:
- When on a color display characters seem to be shifted slightly up or down
  based on the color, this is caused by the construction of the display, i.e.
  by the positioning of the RGB subpixels.

+ HD44780

The HD44780 is driven in 4 bit mode. The pin assignment for the parallel
port is:

  display     config-<MCU>.h   default      remark
                               ATmega 328
  ---------------------------------------------------------------
  DB4         LCD_DB4          PD0
  DB5         LCD_DB5          PD1
  DB6         LCD_DB6          PD2
  DB7         LCD_DB7          PD3
  RS          LCD_RS           PD4
  R/W                          Gnd
  E           LCD_EN1          PD5

You can also drive the LCD via a PCF8574 based I2C backpack which requires
I2C to be enabled. The I2C address has to be specified too. The pin
assignment defines how the LCD is connected to the PCF8574:

  display     config-<MCU>.h   default      remark
  ---------------------------------------------------------------
  DB4         LCD_DB4          PCF8574_P4
  DB5         LCD_DB5          PCF8574_P5
  DB6         LCD_DB6          PCF8574_P6
  DB7         LCD_DB7          PCF8574_P7
  RS          LCD_RS           PCF8574_P0
  R/W         LCD_RW           PCF8574_P1
  E           LCD_EN1          PCF8574_P2
  LED         LCD_LED          PCF8574_P3

For a low active backlight please enable LCD_BACKLIGHT_LOW.

+ ILI9163

The ILI9163 is driven by 4-wire SPI. The pin assignment is:

  display     config-<MCU>.h   default      remark
                               ATmega 328
  ---------------------------------------------------------------
  /RESX       LCD_RES          PD4          optional
  /CSX        LCD_CS           PD5          optional
  D/CX        LCD_DC           PD3
  SCL         LCD_SCL          PD2          SPI clock
  SDIO        LCD_SDA          PD1          SPI MOSI

You might need to play with the x/y flip settings to get the correct
orientation for your display. If necessary you can also offset the x
direction. With LCD_LATE_ON enabled the tester starts with a cleared display
causing a slight delay at power-on. Otherwise you'll see some random pixels
for a moment.

+ ILI9341/ILI9342

The ILI9341/ILI9342 is driven by 4-line SPI or an 8-bit parallel bus. The pin
assignment for 4-line SPI is:

  display     config-<MCU>.h   default      remark
                               ATmega 328
  ---------------------------------------------------------------
  /RES        LCD_RES          PD4          optional
  /CS         LCD_CS           PD5          optional
  D/C         LCD_DC           PD3
  SCK         LCD_SCK          PD2          SPI clock
  SDI         LCD_SDI          PD1          SPI MOSI
  SDO         LCD_SDO          -            ILI9341 only, not used yet

For 8-bit parallel:

  display     config-<MCU>.h   default      remark
                               ATmega 2560
  ---------------------------------------------------------------
              LCD_PORT         PORTB
  /RESX       LCD_RES          PB4          optional
  /CSX        LCD_CS           PB5          optional
  D/CX        LCD_DC           PB7
  WRX         LCD_WR           PB0
  RDX         LCD_RD           PB6          optional
              LCD_PORT2        PORTL
  D0          LCD_DB0          PL0          LCD_PORT2 pin #0
  D1          LCD_DB1          PL1          LCD_PORT2 pin #1
  D2          LCD_DB2          PL2          LCD_PORT2 pin #2
  D3          LCD_DB3          PL3          LCD_PORT2 pin #3
  D4          LCD_DB4          PL4          LCD_PORT2 pin #4
  D5          LCD_DB5          PL5          LCD_PORT2 pin #5
  D6          LCD_DB6          PL6          LCD_PORT2 pin #6
  D7          LCD_DB7          PL7          LCD_PORT2 pin #7

You might need to play with the x/y flip and rotate settings to get the
correct orientation for your display. And don't forget to set x and y dots
based on the controller (ILI9341 is 240x320 and ILI9342 is 320x240). Some
display modules disabled the ILI9341's extended command set (EXTC pin
connected to Gnd). In that case you might see a blurry or ghostly output
which can be fixed by enabling LCD_EXT_CMD_OFF.

Based on the relative high number of pixels the display output is somewhat
slow via SPI. A complete screen clear takes about 3 seconds for bit-bang SPI
and an 8 MHz MCU clock. Better use harwdare SPI or the parallel bus.

+ ILI9481 (partly untested)

The ILI9481 is driven by an 8-bit parallel bus, 16-bit parallel bus or
4-line SPI.

The pin assignment for 8-bit parallel is:

  display     config-<MCU>.h   default      remark
                               ATmega 2560
  ---------------------------------------------------------------
              LCD_PORT         PORTB
  /RESX       LCD_RES          PB4          optional
  /CSX        LCD_CS           PB5          optional
  D/CX        LCD_DC           PB7
  WRX         LCD_WR           PB0
  RDX         LCD_RD           PB6          optional
              LCD_PORT2        PORTL
  DB0         LCD_DB0          PL0          LCD_PORT2 pin #0
  DB1         LCD_DB1          PL1          LCD_PORT2 pin #1
  DB2         LCD_DB2          PL2          LCD_PORT2 pin #2
  DB3         LCD_DB3          PL3          LCD_PORT2 pin #3
  DB4         LCD_DB4          PL4          LCD_PORT2 pin #4
  DB5         LCD_DB5          PL5          LCD_PORT2 pin #5
  DB6         LCD_DB6          PL6          LCD_PORT2 pin #6
  DB7         LCD_DB7          PL7          LCD_PORT2 pin #7

The pin assignment for 16-bit parallel is the same as for 8-bit parallel
and additionally:

              LCD_PORT3        PORTC
  DB8         LCD_DB8          PC0          LCD_PORT3 pin #0
  DB9         LCD_DB9          PC1          LCD_PORT3 pin #1
  DB10        LCD_DB10         PC2          LCD_PORT3 pin #2
  DB11        LCD_DB11         PC3          LCD_PORT3 pin #3
  DB12        LCD_DB12         PC4          LCD_PORT3 pin #4
  DB13        LCD_DB13         PC5          LCD_PORT3 pin #5
  DB14        LCD_DB14         PC6          LCD_PORT3 pin #6
  DB15        LCD_DB15         PC7          LCD_PORT3 pin #7

Pin assignment for 4-line SPI:

  display     config-<MCU>.h   default      remark
                               ATmega 644
  ---------------------------------------------------------------
  /RES        LCD_RES          PB2          optional
  /CS         LCD_CS           PB4          optional
  D/C         LCD_DC           PB3
  SCL         LCD_SCL          PB7          SPI clock
  DIN/SDA     LCD_SDA          PB5          SPI MOSI

Because of the high resolution of the display and the RGB666 color schema (3
bytes per pixel) SPI is quite slow, even for hardware SPI and a 16 MHz MCU
clock. So I wouldn't recommend to use the SPI interface.

Usually you need to rotate the display (LCD_ROTATE) for correct output.
If neccessary you can also flip X and/or Y.

+ ILI9486 (partly untested)

The ILI9486 is driven by an 8-bit parallel bus, 16-bit parallel bus or
4-line SPI. And it uses the same pin assignment as the ILI9481.

+ ILI9488 (partly untested)

The ILI9488 is driven by an 8-bit parallel bus, 16-bit parallel bus or
4-line SPI. And it uses the same pin assignment as the ILI9481.

+ PCD8544

The PCD8544 is driven by SPI. The pin assignment is:

  display     config-<MCU>.h   default      remark
                               ATmega 328
  ---------------------------------------------------------------
  /RES        LCD_RES          PD4          optional
  /SCE        LCD_SCE          PD5          optional
  D/C         LCD_DC           PD3
  SCL         LCD_SCLK         PD2          SPI clock
  SDIN        LCD_SDIN         PD1          SPI MOSI

Since the display has just 84 pixels in x direction you'll get 14 chars per
line with a 6x8 font. So up to two chars might be not displayed. To mitigate
that you could shorten some texts in variables.h.

+ PCF8814

The PCF8814 is driven usually in the 3-wire SPI mode. The pin assignment for 
the 3-wire SPI (bit-bang only) is:

  display     config-<MCU>.h   default      remark
                               ATmega 328
  ---------------------------------------------------------------
  /RES        LCD_RESET        PD4
  /CS         LCD_CS           PD5          optional
  SCLK        LCD_SCLK         PD2          SPI clock
  SDIN        LCD_SDIN         PD1          SPI MOSI

If necessary you can rotate the output via the y-flip setting and pulling
the PCF8814's MX pin (x-flip) down or up.

+ SH1106 (partly untested)

The SH1106 is driven by 3-wire SPI, 4-wire SPI or I2C. 3-wire SPI requires
bit-bang mode and SPI_9 to be enabled. The pin assignment for 4-wire SPI is:

  display     config-<MCU>.h   default      remark
                               ATmega 328
  ---------------------------------------------------------------
  /RES        LCD_RESET        PD4          optional
  /CS         LCD_CS           PD5          optional
  A0          LCD_A0           PD3
  SCL (D0)    LCD_SCL          PD2          SPI clock
  SI (D1)     LCD_SI           PD1          SPI MOSI

For 3-wire SPI (bit-bang only):

  /RES        LCD_RESET        PD4          optional
  /CS         LCD_CS           PD5          optional
  A0                           Gnd
  SCL (D0)    LCD_SCL          PD2          SPI clock
  SI (D1)     LCD_SI           PD1          SPI MOSI

And for I2C:

  /RES        LCD_RESET        PD4          optional
  /CS                          Gnd
  SCL (D0)    I2C_SCL          PD1
  SDA (D1)    I2C_SDA          PD0
  SA0 (A0)                     Gnd (0x3c) / 3.3 V (0x3d)

Using the x/y flip settings you can change the output orientation if
neccessary. Many SH1106 based display modules need the x offset set to 2.
In case the pixel lines are all mixed up you can try to enable the sequential
COM pin layout (LCD_COM_SEQ).

+ SSD1306

The SSD1306 is driven by 3-wire SPI, 4-wire SPI or I2C. 3-wire SPI requires
bit-bang mode and SPI_9 to be enabled. The pin assignment for 4-wire SPI is:
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

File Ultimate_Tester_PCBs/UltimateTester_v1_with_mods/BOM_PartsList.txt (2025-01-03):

Partlist

Exported from LiBatteryChargeBoostBoard.sch at 17-Dec-23 11:04 PM

EAGLE Version 9.6.2 Copyright (c) 1988-2020 Autodesk, Inc.

Assembly variant: 

Part             Value              Device                                   Package                          Library       Sheet

5V               TEST-POINT-TH      TEST-POINT-TH                            TEST-POINT-TH-1MM                .MyComponents 1
5V-0.2A          TEST-POINT-TH      TEST-POINT-TH                            TEST-POINT-TH-1MM                .MyComponents 1
5V-SWITCH                           HEADER-2PIN-0.1"P                        HEADER-2PIN-0.1"P                .MyComponents 1
20MHZ            ECS-200-18-4X-CKM  CRYSTAL-20MHZ-ECS-200-18-4X-CKM          XTAL_ECS-200-18-4X-CKM           .MyComponents 1
BATT+ON          TEST-POINT-TH      TEST-POINT-TH                            TEST-POINT-TH-1MM                .MyComponents 1
BATT+ON'         TEST-POINT-TH      TEST-POINT-TH                            TEST-POINT-TH-1MM                .MyComponents 1
BATT_PORT        S2B-PH-K-S         S2B-PH-K-S                               S2B-PH-K-S                       .MyComponents 1
BUZZER           CMI-9605-0580T     BUZZER-ACTIVE-CMI-9605-0580T             BUZZER-ACTIVE-CMI-9605-0580T     .MyComponents 1
C1               0.1uF              CAPACITOR_SMD0603                        0603                             .MyComponents 1
C2               1uF                CAPACITOR_SMD0603                        0603                             .MyComponents 1
C3               22pF               CAPACITOR_SMD0603                        0603                             .MyComponents 1
C4               10uF               CAPACITOR_SMD0603                        0603                             .MyComponents 1
C5               10uF               CAPACITOR1206                            1206                             .MyComponents 1
C6               22uF-35V           CAPACITOR_SMD1206                        1206                             .MyComponents 1
C7               22pF               CAPACITOR_SMD0603                        0603                             .MyComponents 1
C8               100nF              CAPACITOR_SMD0603                        0603                             .MyComponents 1
C9               100nF              CAPACITOR_SMD0603                        0603                             .MyComponents 1
C10              10uF               CAPACITOR_SMD0603                        0603                             .MyComponents 1
C12              10uF               CAPACITOR_SMD0603                        0603                             .MyComponents 1
C13              1nF                CAPACITOR_SMD0603                        0603                             .MyComponents 1
C14              NC/10pF            CAPACITOR_SMD0603                        0603                             .MyComponents 1
C15              NC/10pF            CAPACITOR_SMD0603                        0603                             .MyComponents 1
C16              100nF              CAPACITOR_SMD0603                        0603                             .MyComponents 1
C17              100nF              CAPACITOR_SMD0603                        0603                             .MyComponents 1
C21              1uF                CAPACITOR_SMD0603                        0603                             .MyComponents 1
C31              22uF-15V           CAPACITOR_SMD1206                        1206                             .MyComponents 1
C41              0.1uF              CAPACITOR_SMD0603                        0603                             .MyComponents 1
C42              10nF               CAPACITOR_SMD0603                        0603                             .MyComponents 1
C43              100uF              EEEFN1E101UP                             CAP_EEEFN1E101UP                 .MyComponents 1
C44              10uF               CAPACITOR_SMD0603                        0603                             .MyComponents 1
C51              10uF-25V           CAPACITOR0603                            0603                             .MyComponents 1
C52              10uF               CAPACITOR0603                            0603                             .MyComponents 1
C53              10nFC0G            CAPACITOR_SMD0603                        0603                             .MyComponents 1
CHARGING         BLUE               LED0603                                  0603-DIODE                       .MyComponents 1
D1               PMBD6100           DIODE-DOUBLE-COMMON-CATHODE-PMBD6100,215 SOT-23-3                         .MyComponents 1
D4               PMBD6100           DIODE-DOUBLE-COMMON-CATHODE-PMBD6100,215 SOT-23-3                         .MyComponents 1
D5               CUS10S30           DIODE-SCHOTTKY-CUS10S30,H3F              SOD-323                          .MyComponents 1
D31              SS34               DIODE-SCHOTTKY-SS34                      SMA                              .MyComponents 1
D41              SMAJ15A            DIODE-TVS-SMA                            SMA                              .MyComponents 1
D42              SS34               DIODE-SCHOTTKY-SS34                      SMA                              .MyComponents 1
D53              PMEG3010EP         DIODE-SCHOTTKY-PMEG3010EP,115            SOD-128                          .MyComponents 1
DISPLAY                             DISPLAY-1.3"-SH1106-I2C                  DISPLAY-1.3"-SH1106-I2C          .MyComponents 1
E-FUSE-SWITCH                       HEADER-2PIN-0.1"P                        HEADER-2PIN-0.1"P                .MyComponents 1
ESD_D1           SRV05-4MR6         SRV05-4MR6T1G                            SOT-23-6                         .MyComponents 1
FAULT            RED                LED0603                                  0603-DIODE                       .MyComponents 1
FLASHLIGHT       HEADER-2PIN-0.2"P  HEADER-2PIN-0.2"P                        HEADER-2PIN-0.2"P                .MyComponents 1
GND              TEST-POINT-TH      TEST-POINT-TH                            TEST-POINT-TH-1MM                .MyComponents 1
GND1             TEST-POINT-TH      TEST-POINT-TH                            TEST-POINT-TH-1MM                .MyComponents 1
GND2             TEST-POINT-TH      TEST-POINT-TH                            TEST-POINT-TH-1MM                .MyComponents 1
GND3             TEST-POINT-TH      TEST-POINT-TH                            TEST-POINT-TH-1MM                .MyComponents 1
GND4             TEST-POINT-TH      TEST-POINT-TH                            TEST-POINT-TH-1MM                .MyComponents 1
I-SENSE-HEADER   CES-102-02-G-S-RA  HEADER-2PIN-0.1"P                        HEADER-2PIN-0.1"P                .MyComponents 1
IC1-BATT-PROTECT XB8089D            XB8089D                                  SOIC-8-POWER-PAD                 .MyComponents 1
IC2-CHARGER      BQ21040DB          BQ21040DBVR                              SOT-23-6                         .MyComponents 1
IC3              MT3608             MT3608                                   SOT-23-6                         .MyComponents 1
IC4-E-FUSE       TPS259630          TPS259621DDAR                            SOIC-8-POWER-PAD                 .MyComponents 1
IC5-5V           LP2992IM5-5.0      LP2992IM5-5.0                            SOT-23-5                         .MyComponents 1
IC6-I-SENSE      TMCS1108A4B        TMCS1108A4B-CURRENT-SENSE                SOIC-8                           .MyComponents 1
ICSP             CES-103-01-T-D     HEADER-ICSP-0.1"P                        HEADER-ICSP-0.1"P                .MyComponents 1
ILIMIT                              HEADER-3PIN-0.1"P                        HEADER-3PIN-0.1"P                .MyComponents 1
L31              22uH               INDUCTOR-SMRH74-220MT                    INDUCTOR-SMRH74-220MT            .MyComponents 1
LOGIC-PROBE                         HEADER-2PIN-0.1"P                        HEADER-2PIN-0.1"P                .MyComponents 1
POW-SW           TEST-POINT-TH      TEST-POINT-TH                            TEST-POINT-TH-1MM                .MyComponents 1
POW~12V          RED                LED1206                                  1206-DIODE                       .MyComponents 1
PWR-EN           TEST-POINT-TH      TEST-POINT-TH                            TEST-POINT-TH-1MM                .MyComponents 1
R1               1K                 RESISTOR_SMD0603                         0603                             .MyComponents 1
R2               10K                RESISTOR_SMD0603                         0603                             .MyComponents 1
R3               4K7                RESISTOR_SMD0603                         0603                             .MyComponents 1
R4               10K                RESISTOR_SMD0603                         0603                             .MyComponents 1
R5               3K3                RESISTOR_SMD0603                         0603                             .MyComponents 1
R6               680                RESISTOR_SMD1206                         1206                             .MyComponents 1
R7               51                 RESISTOR_SMD1206                         1206                             .MyComponents 1
R8               100K               RESISTOR_SMD0603                         0603                             .MyComponents 1
R9               680                RESISTOR_SMD1206                         1206                             .MyComponents 1
R10              680                RESISTOR_SMD1206                         1206                             .MyComponents 1
R11              470k               RESISTOR_SMD1206                         1206                             .MyComponents 1
R12              470k               RESISTOR_SMD1206                         1206                             .MyComponents 1
R13              470k               RESISTOR_SMD1206                         1206                             .MyComponents 1
R14              10K                RESISTOR_SMD0603                         0603                             .MyComponents 1
R15              100K               RESISTOR_SMD0603                         0603                             .MyComponents 1
R16              10K                RESISTOR_SMD0603                         0603                             .MyComponents 1
R17              3K3                RESISTOR_SMD0603                         0603                             .MyComponents 1
R18              10K                RESISTOR_SMD0603                         0603                             .MyComponents 1
R19              10K                RESISTOR_SMD0603                         0603                             .MyComponents 1
R20              10K                RESISTOR_SMD0603                         0603                             .MyComponents 1
R21              1K                 RESISTOR_SMD0603                         0603                             .MyComponents 1
R22              750                RESISTOR_SMD0603                         0603                             .MyComponents 1
R23              3.3K               RESISTOR_SMD0603                         0603                             .MyComponents 1
R24              3.3K               RESISTOR_SMD0603                         0603                             .MyComponents 1
R25              10K                RESISTOR_SMD0603                         0603                             .MyComponents 1
R26              3.3K               RESISTOR_SMD0603                         0603                             .MyComponents 1
R27              10K                RESISTOR_SMD0603                         0603                             .MyComponents 1
R28              68R                RESISTOR_SMD0603                         0603                             .MyComponents 1
R29              10K                RESISTOR_SMD0603                         0603                             .MyComponents 1
R30              10K                RESISTOR_SMD0603                         0603                             .MyComponents 1
R31              2.2K               RESISTOR_SMD0603                         0603                             .MyComponents 1
R32              18K                RESISTOR_SMD0603                         0603                             .MyComponents 1
R33              0                  RESISTOR_SMD0603                         0603                             .MyComponents 1
R34              10K-1%             RESISTOR_SMD0603                         0603                             .MyComponents 1
R35              50K                ROTARY-POTENTIOMETER-3386P-1-503TLF      ROTARY-POTENTIOMETER-3386P       .MyComponents 1
R36              10K                RESISTOR_SMD0603                         0603                             .MyComponents 1
R37              22K                RESISTOR_SMD0603                         0603                             .MyComponents 1
R38              7K5                RESISTOR_SMD0603                         0603                             .MyComponents 1
R41              82K5               RESISTOR_SMD0603                         0603                             .MyComponents 1
R42              38K3               RESISTOR_SMD0603                         0603                             .MyComponents 1
R43              10K                RESISTOR_SMD0603                         0603                             .MyComponents 1
R46              3K3                RESISTOR_SMD0603                         0603                             .MyComponents 1
R47              1K                 RESISTOR_SMD0603                         0603                             .MyComponents 1
R48              470                RESISTOR_SMD0603                         0603                             .MyComponents 1
RD1              5K1-1%             RESISTOR_SMD0603                         0603                             .MyComponents 1
RD2              5K1-1%             RESISTOR_SMD0603                         0603                             .MyComponents 1
RILIM1           1K8-1%             RESISTOR_SMD0603                         0603                             .MyComponents 1
RILIM2           560-1%             RESISTOR_SMD0603                         0603                             .MyComponents 1
RISET            1K5-0.36A          RESISTOR_SMD0603                         0603                             .MyComponents 1
ROTARY-ENCODER   PEC12R-3217F-S0024 PEC12R-3217F-S0024                       PEC12R-3217F-S0024               .MyComponents 1
S1               POWER-SWITCH       SLIDE-SWITCH-SP3T-VER-TH-MINI            CSS-1310MC                       .MyComponents 1
S2               TPS22995H          TPS22995H-Q1                             SOT-23-6                         .MyComponents 1
S3               BC847C             BC847C                                   SOT-23-3                         .MyComponents 1
S4               DMP1045U           DMP1045U                                 SOT-23-3                         .MyComponents 1
S6               AS2312             AS2312AS2312                             SOT-23-3                         .MyComponents 1
TP1                                 HEADER-3PIN-0.1"P                        HEADER-3PIN-0.1"P                .MyComponents 1
TP2                                 HEADER-3PIN-0.1"P                        HEADER-3PIN-0.1"P                .MyComponents 1
TP3                                 HEADER-3PIN-0.1"P                        HEADER-3PIN-0.1"P                .MyComponents 1
TVS_D2           SMBJP6KE6.8A       SMBJP6KE6.8A-TP                          DIOM5336X244N                    .MyComponents 1
U1               ATMEGA328P-AU-TQFP ATMEGA328P-AU-TQFP                       TQFP32                           .MyComponents 1
USB-ON           ORANGE             LED0603                                  0603-DIODE                       .MyComponents 1
USBC             10164359-00011LF   USB-C-RECEPTABLE-10164359-00011LF        USB-C-RECEPTABLE-1016435900011LF .MyComponents 1
VBOOST           TEST-POINT-TH      TEST-POINT-TH                            TEST-POINT-TH-1MM                .MyComponents 1
VBOOST-SEL                          SLIDE-SWITCH-SPDT-VERTICLE-TH            SLW-883935-2A-D                  .MyComponents 1
VIN              TEST-POINT-TH      TEST-POINT-TH                            TEST-POINT-TH-1MM                .MyComponents 1
VIN'             TEST-POINT-TH      TEST-POINT-TH                            TEST-POINT-TH-1MM                .MyComponents 1
VIN-ON           GREEN              LED0603                                  0603-DIODE                       .MyComponents 1
VOUT             TEST-POINT-TH      TEST-POINT-TH                            TEST-POINT-TH-1MM                .MyComponents 1
VOUT'            TEST-POINT-TH      TEST-POINT-TH                            TEST-POINT-TH-1MM                .MyComponents 1
VREF_SHUNT       LM4040AELT-2.5     LM4040AELT-2.5-SOT23                     SOT-23-3                         .MyComponents 1

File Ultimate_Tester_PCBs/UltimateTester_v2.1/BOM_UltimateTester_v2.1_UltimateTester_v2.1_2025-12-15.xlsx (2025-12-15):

No. | Quantity | Comment | Designator | Footprint | Value | Manufacturer Part | Manufacturer | Supplier Part | Supplier | LCSC Price | LCSC Stock | JLCPCB Stock | JLCPCB Price | Primary Category | Secondary Category | Add into BOM | Convert to PCB | Name | Device | JLCPCB Part Class
1 | 1 | S2B-PH-K-S-GW | BATT-PORT | CONN-TH_S2B-PH-K-S-GW |  | S2B-PH-K-S-GW | JST | C157932 | LCSC |  |  | 468 | 0.0849 | Connectors | Wire To Board Connector | yes |  | S2B-PH-K-S-GW | S2B-PH-K-S-GW | Extended Part
2 | 1 | 2.7kHz | BUZZER | BUZ-TH_BD9.6-P5.00-D0.7-FD | 2.7kHz | GMD9505YB-3V2700 | INGHAi(赢海) | C252934 | LCSC |  |  | 1521 | 0.0491 | Audio Products / Vibration Motors | Buzzers | yes |  | 2.7kHz | GMD9505YB-3V2700 | Extended Part
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

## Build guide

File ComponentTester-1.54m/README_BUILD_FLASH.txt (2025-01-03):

Steps to build using WinAVR Programmer's Notepad:
- Open WinAVR Programmer's Notepad
- Open Makefile
- Run Clean All
- Run Make All

Steps to flash using AVRDUDESS:
1. using Arduino ISP:
    - Use Arduino ISP Microcontroller to program new MCU
    - Attach ICSP and Reset Pins to new MCU
    - Set AVRDUDESS:
        - Programmer: Arduino
        - Baud Rate: 19200
        - Bit clock: <empty>
    - Under MCU Section, click 'Detect' - 1E9705 should come up (ATmega1284) or 1E9706 (ATmega1284p)
    - Set Fuses
    - Your new MCU is ready to be flashed!
2. using FTDI FT2232HL Programmer:
    - Attach ICSP Pins to new MCU
    - Set AVRDUDESS:
        - Programmer: avrftdi
        - Baud Rate: 2000000
        - Bit clock: <empty>
    - Under MCU Section, click 'Detect' - 1E9705 should come up (ATmega1284) or 1E9706 (ATmega1284p)
    - Set Fuses
    - Your new MCU is ready to be flashed!

ATmega1284p Fuses
L 0xF7
H 0xDE
E 0xFD
LB 0xFF

Flash Component Tester:
- Under Flash Section:
	- Select ComponentTester.hex file
	- Select 'Write'
	- Format: Auto
- Under EEPROM Section:
	- Select ComponentTester.eep file
	- Select 'Write'
	- Format: Auto
- Under Options Section:
	- Erase flash and EEPROM
	- Verbosity: 2
    
- Click Program!

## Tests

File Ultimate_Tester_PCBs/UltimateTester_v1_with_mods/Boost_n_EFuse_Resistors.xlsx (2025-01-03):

MT3608 BOOST |  |  |  |  |  |  |  |  | RISET
 | Vref | 0.6 | V
 | R2 (fixed) | 2.2 | kOhm
 | Vout | 0.6 | 5.5 | 12
 | R1 | 0.00 | 17.97 | 41.80
 |  |  |  |  |  |  |  |  | Kset | 540
 | R1 | 50 | 20.00 | 16.70 | 10.00 | 60.00 |  |  | Riset | 1500
 | R2 | 2.2 | 2.2 | 2.2 | 2.2 | 2.2 |  |  | Iout | 0.36 | A
 | Vout | 14.24 | 6.05 | 5.15 | 3.33 | 16.96
E-FUSE
 |  |  |  |  |  |  | Vin(min) | 3 | (input)
 |  |  |  |  |  |  | Vin(max) | 15.8 | (input)
 |  |  |  |  |  |  | Vuvlo(f) | 1.1
 |  |  |  |  |  |  | Vovlo(r) | 1.2
 |  |  |  |  |  |  | R3 | 10.00 | (input)
 |  |  |  |  |  |  | R1+R2 | 121.67 |  | Used
 |  |  |  |  |  |  | R2 | 38.28 |  | 38.30 | 33+5.1
 |  |  |  |  |  |  | R1 | 83.39 |  | 82.50 | 43+43
 |  |  |  |  |  |  | R1+R2+R3 | 131.67 |  | 130.80
 |  |  |  |  |  |  |  |  | Check:
 |  |  |  |  |  |  |  |  | Vuvlo(c) | 1.11
 |  |  |  |  |  |  |  |  | Vovlo(c) | 1.21
 |  |  |  |  |  |  |  |  | Set V:
 |  |  |  |  |  |  |  |  | Vin(min) | 2.98
 |  |  |  |  |  |  |  |  | Vin(max) | 15.70
 |  |  |  |  | ILIM | RLIM
 |  |  |  |  | 0.5 | 1847.38
 |  |  |  |  | 1.5 | 606.53
 |  |  |  |  | Rlim | Ilim
 |  |  |  |  | 1800 | 0.51
 |  |  |  |  | 560 | 1.62

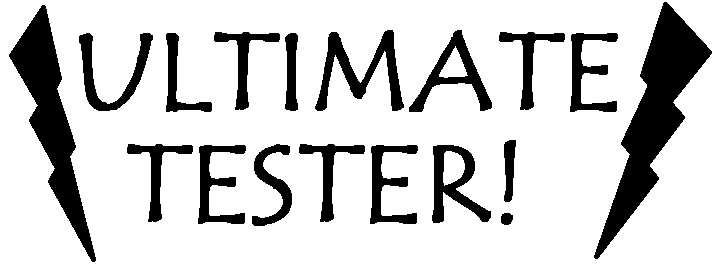
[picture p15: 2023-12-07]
Ultimate_Tester_PCBs/UltimateTester_v1_with_mods/graphic-2-ines.bmp

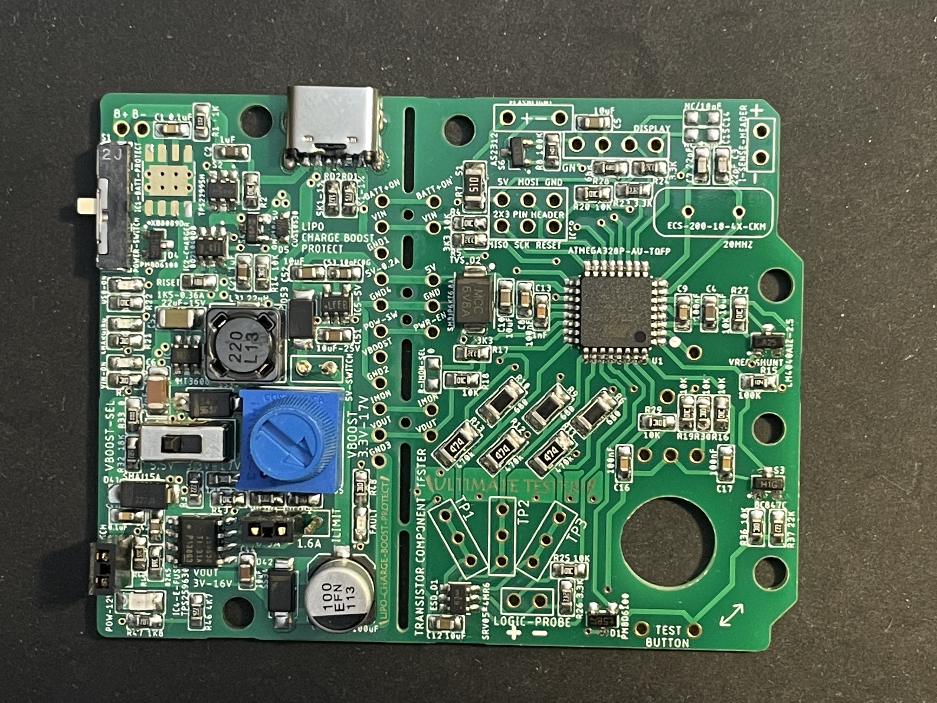
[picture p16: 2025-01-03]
Ultimate_Tester_PCBs/UltimateTester_v1_Pics/img_e0822.jpg

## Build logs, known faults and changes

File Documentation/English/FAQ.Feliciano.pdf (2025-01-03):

1

## FAQ about the Transistor Tester (aka Component Tester)

v0.2.6 by Feliciano

Foreword
After reading most of related the EEVblog thread over the years, I noticed there are several questions that pops-up every now and then, so I took the initiative of writing this FAQ with the help of the major supporters. We hope it help you get your bearings about what is this project about and what value can add to your bench.

FAQs

### 1. What is the “LCR and transistor tester”?

a. Actually it’s an electronics components tester. It started as an idea on the German Mikrocontroller forum. Here you can read a summary: https://www.mikrocontroller.net/articles/AVR_Transistortester#Introduction_.28English.29
b. The basic design revolves around mimimun AVR hardware (ATmega) with a text display, for which a firmware was developed to allow identify an unknown electronic component of two or three pins connected to it, and its main characteristics.

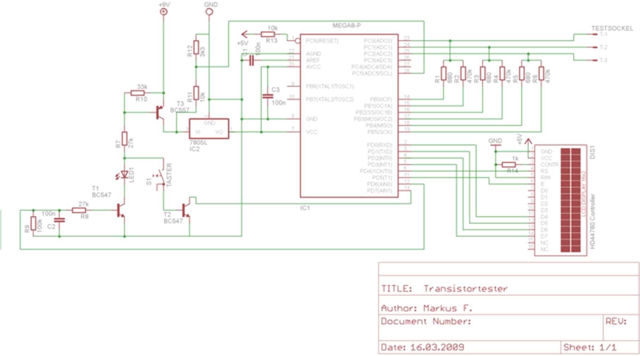
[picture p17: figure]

The key factors was to keep the price low and provide a reasonable precision (although not the same as a professional equipment costing 10x more)
c. The original circuit could be optionally upgraded and/or expanded with several hardware options to add more features
d. This entire project is OSHW (Open Source Hardware). The original developer, Markus Frejek stated his design was “Open Source”. The time passed and he ceased releasing updates, so Karl-Heinz Kübbeler (kubi48) forked the project to add new features, and shortly Markus Reschke (madires) joined in with additional ideas and strong support. kubi48 releases the k-firmware; madires releases the m-firmware under EUPL V.1.2 License
e. Some Asian vendors took the original circuit and/or improved/modern circuits, as well as the original/updated firmware, and started to sell “original” mods of the OSHW circuit and firmware. We refer to those unassembled or finished kits as “clones”, some are clones of other clones, and the quality varies from one vendor/batch to the other. Normally those vendors lock the chips and the designs “to avoid piracy” and don’t show interest on sharing their hardware/firmware mods for further improvements. Hence, most of the times somebody buys a clone online, there are not updates for the firmware it came with, so you can keep it as it came (as long as it’s not broken there’s no need to fix it, right?), or you can try to flash the OSHW firmware and gain more features and/or improvements

2

f. Please note the following open letter from the microcontroller.net forum to the component tester clone vendors: “Dear Transistortester Cloners and Sellers!

We don't mind if you produce and sell clones of the Transistortester. It provides an inexpensive great little tool for electronics enthusiasts and beginners, but PLEASE note the links to the project's webpage, source repo and documentation. You would add more value by giving users that information to be able to update the firmware and to understand all the features. If you do any modifications to the firmware, please send us a copy for the repo. And if you would send us your Transistortester clones, we would be able to keep the firmware as compatible as possible. Don't forget, this is an OSHW project!”

### 2. Is this really an LCR meter?

a. The typical working principle of commercial LCR meters is to generate a low voltage AC signal (usually around 100KHz) and from the measurements calculate many of the parameters of interest for the selected connected inductor or capacitor under test
b. Additionally, the commercial LCRs use to have a wide range of measurement, and medium-to-high accuracy
c. On the other hand, the inexpensive component testers here explained works under a totally different principle: it applies to the device under test (DUT) a combination of 5Vdc pulses, while sampling the voltages on its terminals at given times. This way it can deduct the main parameters of resistors, diodes, several kinds of transistors, SCR, Triacs, and also for certain range of capacitors and/or inductors. Therefore, although the clone makers use the LCR buzzword, the component testers here discussed are not the comparable to an USD100 to USD200 commercial LC/LCR meter

### 3. What is the working principle of the transistor/component tester?

a. As mentioned previously, it has an AVR microcontroller (there are different designs with different amounts of flash and RAM) with bidirectional I/O ports. Some of these ports are connected to known high value resistors (470K), and others are connected to known low value resistors (680R). By sending pulses over one pin and sampling the voltage on the same and/or other pins, the kind of component connected can be inferred, and from it, its main characteristics can be determined (under 5V and low current scenarios, which is what a microcontroller with some resistors can offer)
b. For more technical details, Karl-Heinz has shared very detailed information on how his approach works. You can read the Chapter 5 of: https://github.com/kubi48/TransistorTester-documentation/blob/main/pdftex/english/ttester.pdf
c. There is also a technical manual for m-firmware (with the help of Bohu): https://github.com/madires/Transistortester-Warehouse/blob/master/Documentation/English/ctester-1.44m.pdf

### 4. How a transistor/component tester is used?

a. Easy: connect the battery or power adapter (preferable a linear regulated supply), and for testing a component, connect its two or three terminals, press the test button, wait, read the results. Depending on the tester you have, and the firmware installed, you may have additional functions such as signal generator, frequency measurement, etc.
b. Warning: If you’re about to measure a capacitor (especially electrolytic), make sure it’s discharged. Any higher than TTL voltage/current can damage the protection of your equipment (if exist), and/or the MCU
c. Calibration or Self-test note: this equipment needs to be adjusted every now and then, and/or when you flash a new firmware. After invoking the calibration or self-test, the screen will show some instructions to follow along the procedure. The details will depend on the particular hardware/firmware and version your unit is running, you can check it on the above referred user manuals if you want, and it’s something like:
d. For the k-firmware the calibration can be started by connecting the three terminals together (i.e. make a short), and press the test button (for the units with menu, it can be selected from the menu entry as well), acknowledge the confirmation prompt, and follow the on-screen instructions. Please note you may need 1 or 2 film capacitors of given capacitance range
e. For the m-firmware, it’s recommended to measure at least 3 times film capacitor(s) between 100nF and 2.2uF before performing the self-test. After that, the self-adjustment can be called from the main menu, you just have to follow simple on-screen instructions

3

f. The measurements performed during the calibration or self-tests procedure are stored in the EEPROM. These offset parameters can be shown after the self-test calibration, or from selected the menu entry for showing data. Sometimes it’s needed to review these offset values to troubleshoot some odd measurements. Also, some firmware allows to save two profiles, so you can use a ZIF socket and a set of leads, for instance

### 5. Can this be used for (ESR) measurements on-circuit?

a. You can have a dedicated ESR measurement menu option. However, if you measure a capacitor (remember to discharge it first), you’re measuring the component and whatever other components are connected to it, so the measurements can be deceiving. Therefore, you can do the in-circuit measurement, but if the results show something weird, you are advised to remove the component and measure it again off-circuit to validate the results

### 6. What information is shown on screen of the transistor tester?

a. It depends whether your unit is running the k-firmware, the m-firmware, or one of the Asian variations (M-Tester and such), and the version of that obscure firmware
b. In the case of the k-firmware, the author wrote a visual guide of its functionalities: https://github.com/kubi48/TransistorTester-documentation/blob/main/pdftex/english/ttinfo.pdf

### 7. Which clone I have?

a. Kubi48 kindly gathered some pictures of the main clones, so you can look whether the one you already have look similar to one of those: https://github.com/kubi48/TransistorTester-source/blob/master/picture-link.pdf
b. indman composed a table of clones (see below)

### 8. Which clone do you recommend?

a. It depends on your needs and budget. An ATmega processor can have flash of 8KB, 16KB, 32KB, 64KB, etc. and a RAM of 512B, 1KB, 2KB, 4KB, etc. and it can have more or less ports (some of them will be used for the test terminals and the screen connections), so there is no perfect design yet unless you build one yourself from scratch and compile the firmware according to your hardware and likings
b. On the dedicated EEVblog forum thread: https://www.eevblog.com/forum/testgear/$20-lcr-esr-transistor-checker-project/
the most popular by 2021 were the AY-AT (it has that name printed on the PCB) and the Hiland m644. indman kindly generated a table of the main clones and its main features, so you can choose the one that better match your needs: https://github.com/madires/Transistortester-Warehouse/blob/master/Documentation/English/Clone-Comparison-Chart.pdf but please note since 2023 it’s not easy to find an unit with an original ATmega

### 9. Can I improve my equipment?

a. Probably yes, either by using lower tolerance resistors (i.e. 0.1%), and/or upgrading the crystal from 8MHz to 16MHz, and/or upgrading the microcontroller for one with more memory, and/or by improving the power supply and/or voltage reference to higher precision (i.e. replacing the typical TL431 with an LM4040 or such, or removing the TL431 if your 5V regulator is a high precision one like MCP1702)
b. You can also add optional components, like a rotary encoder, or a circuit for voltage measurement, or a buffer circuit for external signals, or a TTL I/O, etc.
c. Note: Most of the hardware changes require compiling/flashing a custom firmware

### 10. Can I repair my equipment?

a. If you forgot to discharge a capacitor before measurement, you may have burnt the protection circuit (in case your circuit had one), or you may have blown your MCU. The protection elements (diodes, if present) can be simply removed and you can check whether the rest still works, or if you can easily find the parts and prefer to repair rather than to replace the whole unit, you can swap the microcontroller and re-program it with the k-firmware or m-firmware
b. Note: some clones have better designs than others, and some vendors use better components than others for the same clone, and sometimes one batch of components has better quality than other, so YMMV

### 11. Which is the latest firmware?

a. If you have an Asian clone, most likely you have an old firmware, under the original version number or an unofficial version number (such as 2.12k for a TC1 clone). Probably you won’t find an update for that

4

b. By the time of writing (2024/Q1) the current versions are: 1.13k for k-firmware, 1.51m for m-firmware. Please note: the two OSHW firmware branches are different (approaches, features, GUI), so you can try both and decide which one works better for your liking
c. If you want to read about the differences between k-firmware and m-firmware, madires releases a README of over 50 pages part of his m-firmware archive, where some of its pages discuss the differences with the k-firmware

### 12. Where can I download the firmware?

a. For Asian firmware: we don’t know. Those tends to have nicer graphics, but in exchange of functionalities (memory trade-off). Some users have managed to read the firmware of certain clones and share it on the EEVblog forum. indman has collected several, but it’s better to ask before using any of those, as he had made modifications of some
b. For k-firmware (or trunk):
https://github.com/kubi48/TransistorTester-source/tree/master/trunk
c. For m-firmware or k-firmware: https://github.com/madires/Transistortester-Warehouse/tree/master/Firmware/m-firmware

### 13. Is the firmware only available in English?

a. The info on the display can be shown in several of the major languages, you just need to check the list of available translations, compile the firmware selecting (on the makefile) the one you want, flash, enjoy

### 14. How can I compile the firmware?

a. For k-firmware: KH has created folders for the main clones with the related EEPROM and flash files (.eep and .hex). You can either directly flash those to try, or you can git the whole source, edit the related makefile according to your clone variation and/or likings, compile (make) it, and flash it
b. For m-firmware: madires release the source (not targets) as a .tar.gz file. You have to download and decompress it, open the “clones” file and find the settings to modify for the clone you have, edit several .h directive files (do a backup of the originals just in case), edit the makefile (do a backup too), and compile (make) it
c. You can do this on Windows or Linux. Remember this is written in C, so you have to install the compiling
environment for your OS. In case of Windows, you can try WinAVR with the right version of the ATmega toolchain, so you may have to overwrite the msys-0.1.dll too if you have W8, W8.1 or W10. If you are using linux or Mac, the k-firmware and the m-firmware has instructions (in the readme and/or pdf) on how to install the tools and compile and flash the firmware
d. You will also have to check/install the drivers for the cable you’re about to use to connect to the board. Popular cables are TL866A and USBasp (in case of the later, please disregard posts on the net telling you need to upgrade the firmware to a 2010 version, unless your cable is that old). Some people have tried other options like Arduino, etc.
e. For more information, Flywheelz made a detailed description with the links to the Windows software: https://www.eevblog.com/forum/testgear/$20-lcr-esr-transistor-checker-project/2475/
f. Indman also shared an archive with the Windows software: https://drive.google.com/file/d/1ioYbEuzrPkiSpJ51IamuwcZ1IU4PplbI/view
g. And Blurpy has made a Windows guide for a popular clone he has: https://github.com/blurpy/transistor-tester

### 15. How can I flash the firmware?

a. You can do it on-circuit (if you solder an ISP or similar port) or off-circuit (if you have a socketed microcontroller). Normally the clones come without a populated ISP port, so if the port is there you just have to solder some headers for your cable, but sometimes you have to solder wires from certain pins of your AVR in order to add the ISP port
b. After finding or compiling (make) the firmware files (.eep and .hex), having the ISP port ready and connecting the cable, you can use avrdude or equivalent (like a GUI frontend called AVRDUDESS) for flashing both files. Please remember to read about the fuses in advance and set it correctly, especially if your unit came locked.
Warning: a wrong set of fuses can render the ISP port useless, and therefore you would need a high voltage programmer to recover your AVR
c. So, if you’re only about to flash existing k-firmware’s .eep and .hex files you just need to run avrdude or similar to flash both files, and probably set the fuses (especially if your unit is locked, in which case you also have to erase it

5

before flashing it)
Note: Windows 10 doesn’t handle correctly too long command lines, so if you’re about to use avrdude on the command prompt, you may have to program the EEPROM, the flash, and set the fuses as 3 separated steps

### 16. Where can I find more information?

a. You can search the whole 300+ pages of the EEVblog thread -by using the print preview button at the top- and searching for the keywords you’re looking for. You can also use the google site search
b. Or you can read the last 10 or so pages (as many people ask similar questions often), and if you don’t find what you’re after you can ask, if you ask nicely, for sure some kind person will give you a hand

Closing Thoughts
After several years this project keeps moving forward, thanks to the developers, and the community of the EEVblog and German and Russian forums. This FAQ is not finished, yet it can help the project a little, and can be improved too, shall you have comments, please post it at the EEVblog.

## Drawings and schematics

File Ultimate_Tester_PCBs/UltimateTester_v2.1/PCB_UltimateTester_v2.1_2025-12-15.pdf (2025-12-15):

# TEST BTN

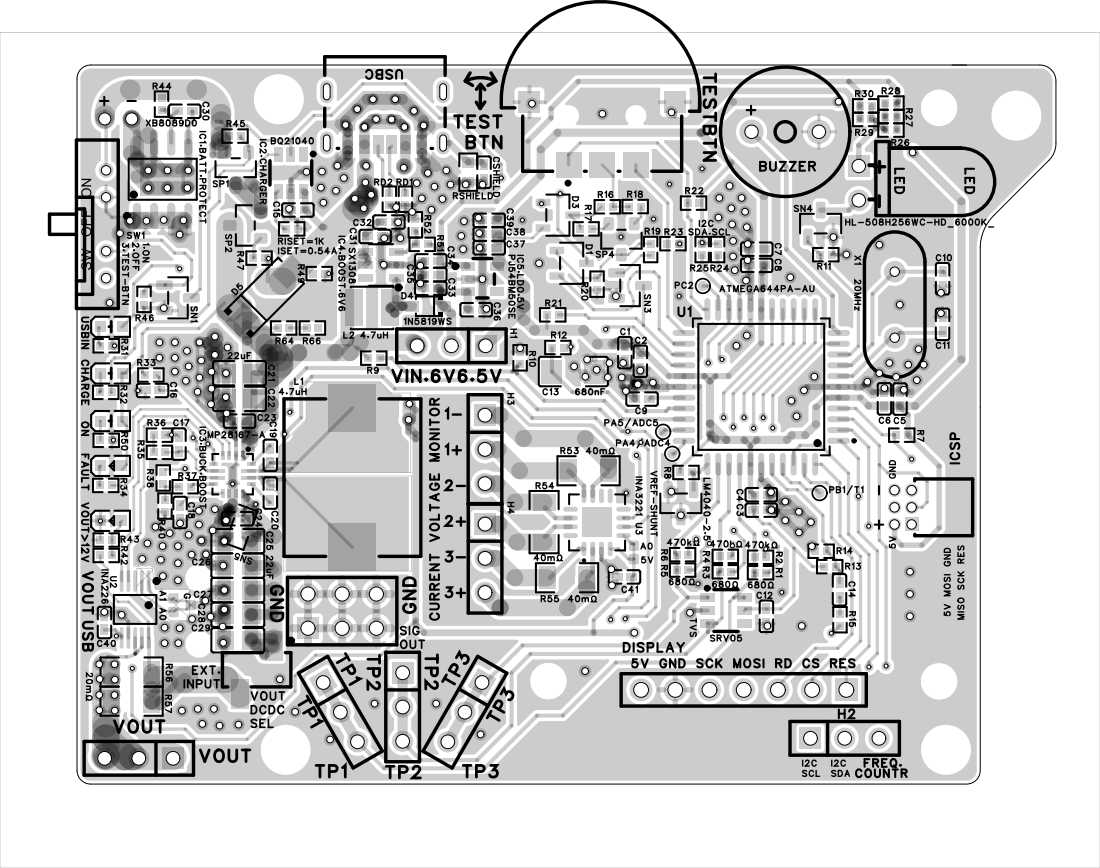
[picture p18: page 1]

DISPLAY
5V GND SCK MOSI RD CS RES

+

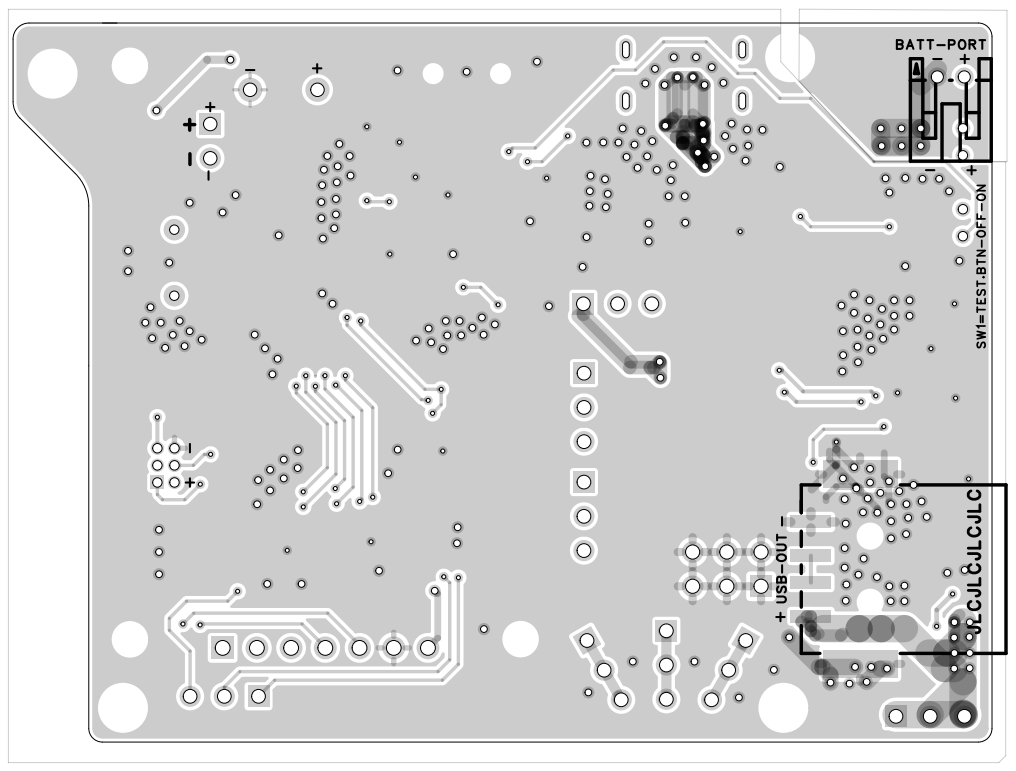
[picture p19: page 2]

SW1=TEST.BTN-OFF-ON

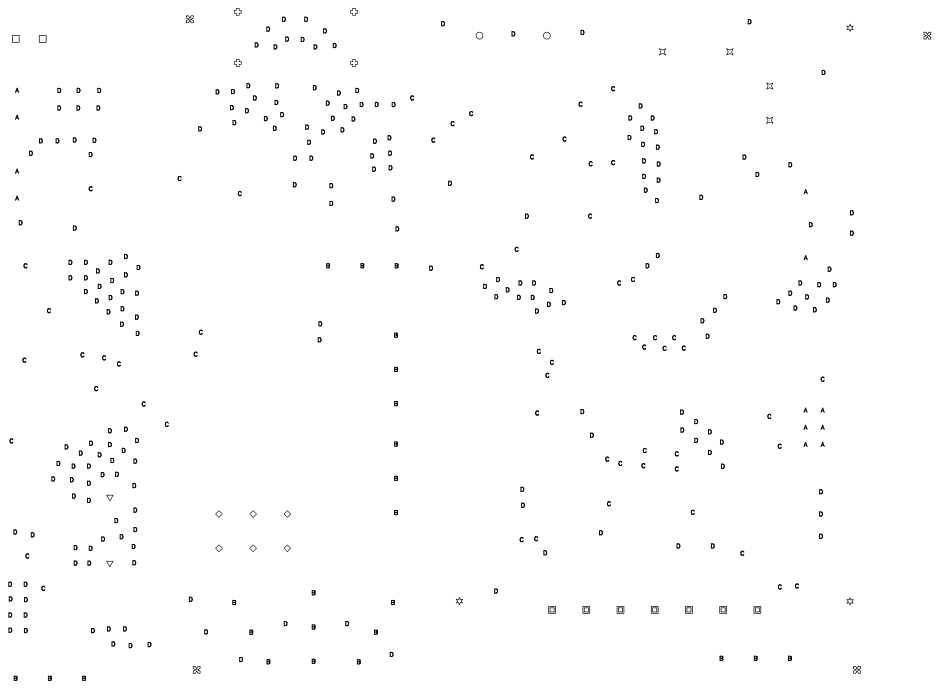
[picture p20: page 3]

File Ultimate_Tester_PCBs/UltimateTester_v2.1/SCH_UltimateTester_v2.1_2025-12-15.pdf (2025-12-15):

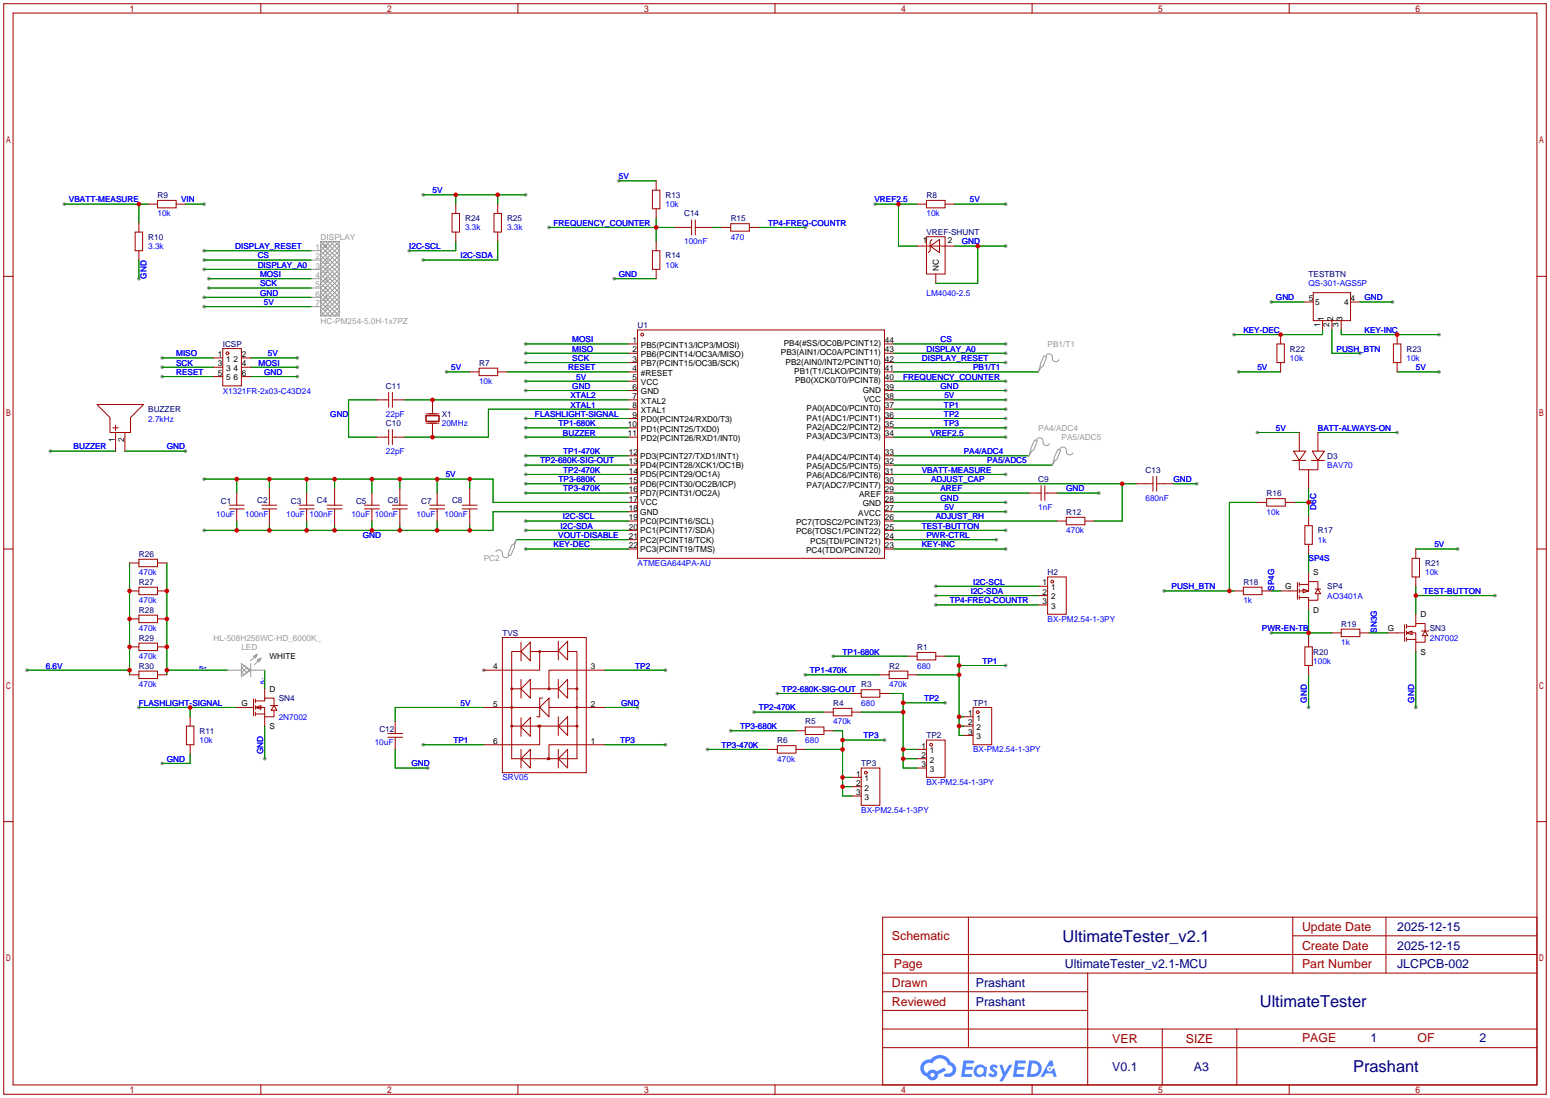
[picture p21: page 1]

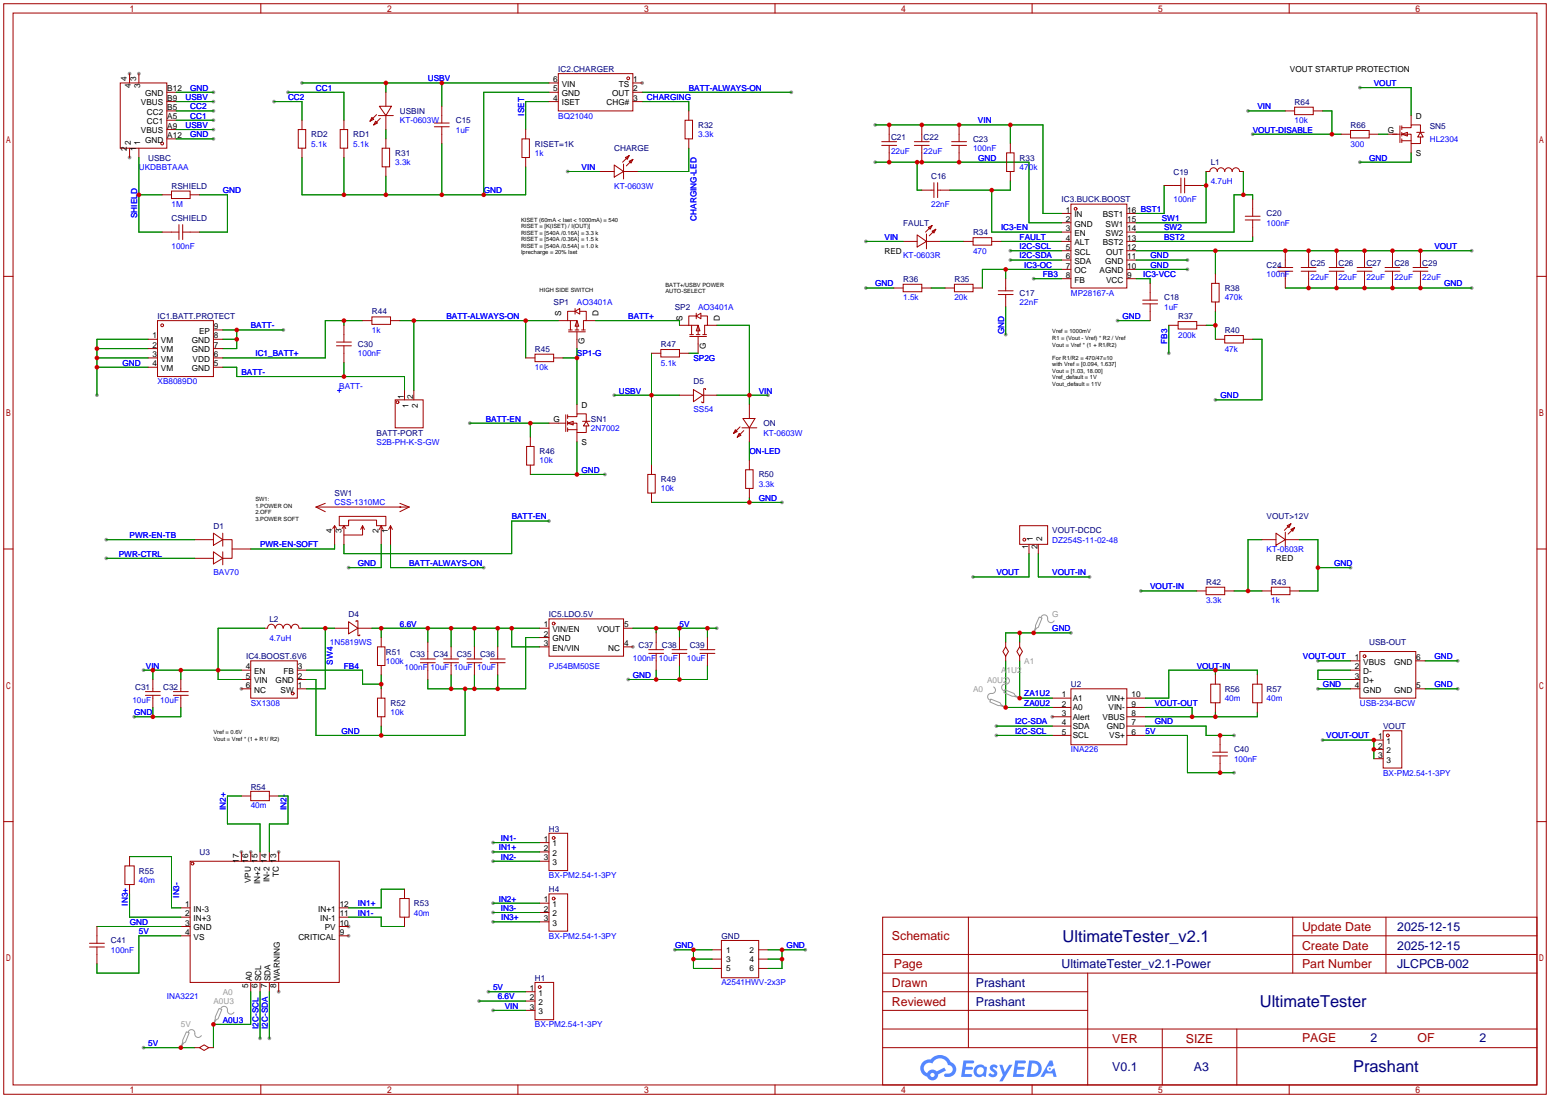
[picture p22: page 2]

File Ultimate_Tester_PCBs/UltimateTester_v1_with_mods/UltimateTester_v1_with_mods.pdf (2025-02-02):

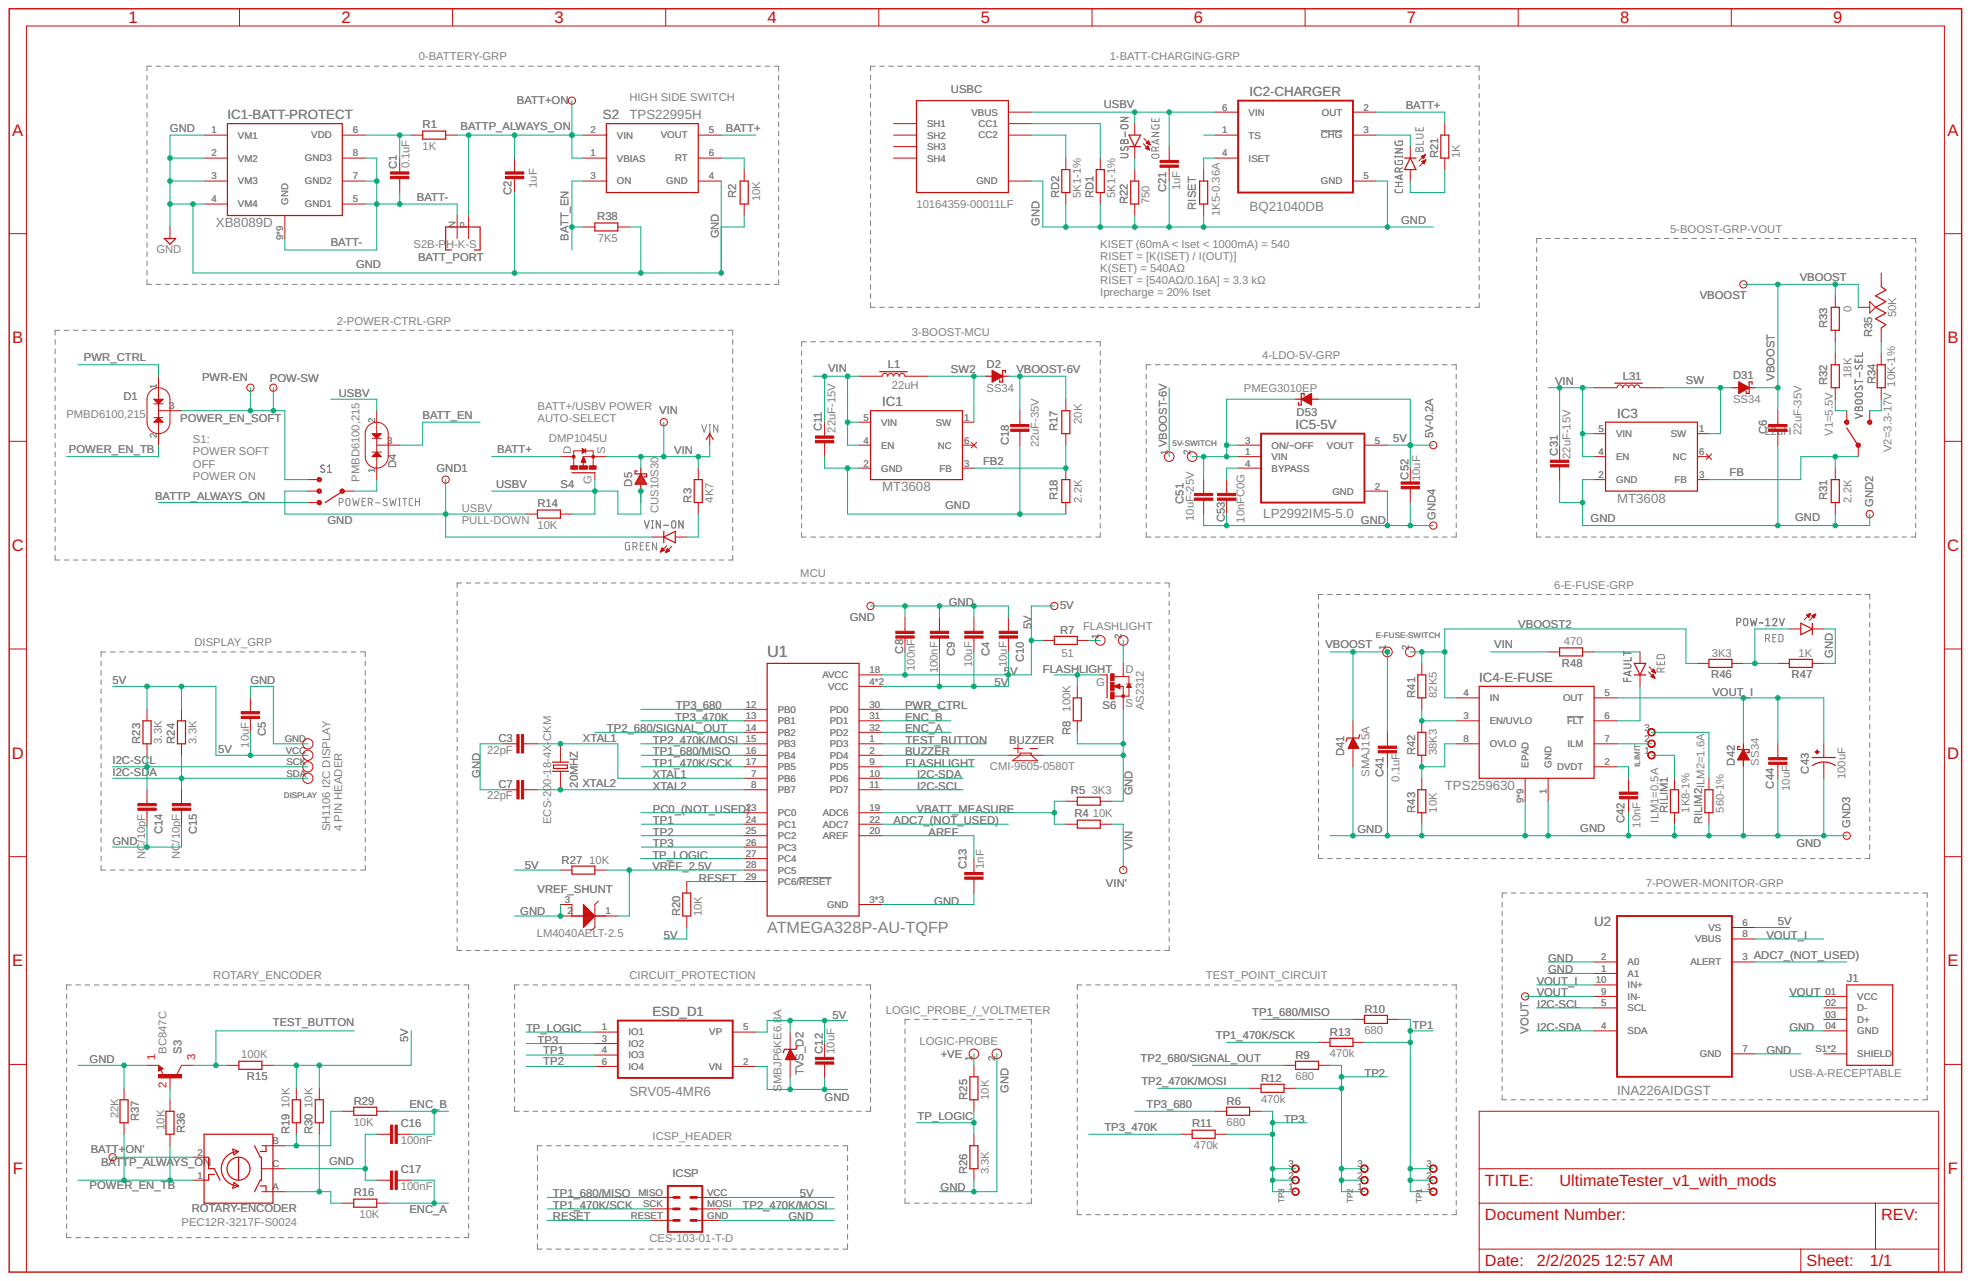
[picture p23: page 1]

Document Number: | REV:

Date: 2/2/2025 12:57 AM | Sheet: 1/1

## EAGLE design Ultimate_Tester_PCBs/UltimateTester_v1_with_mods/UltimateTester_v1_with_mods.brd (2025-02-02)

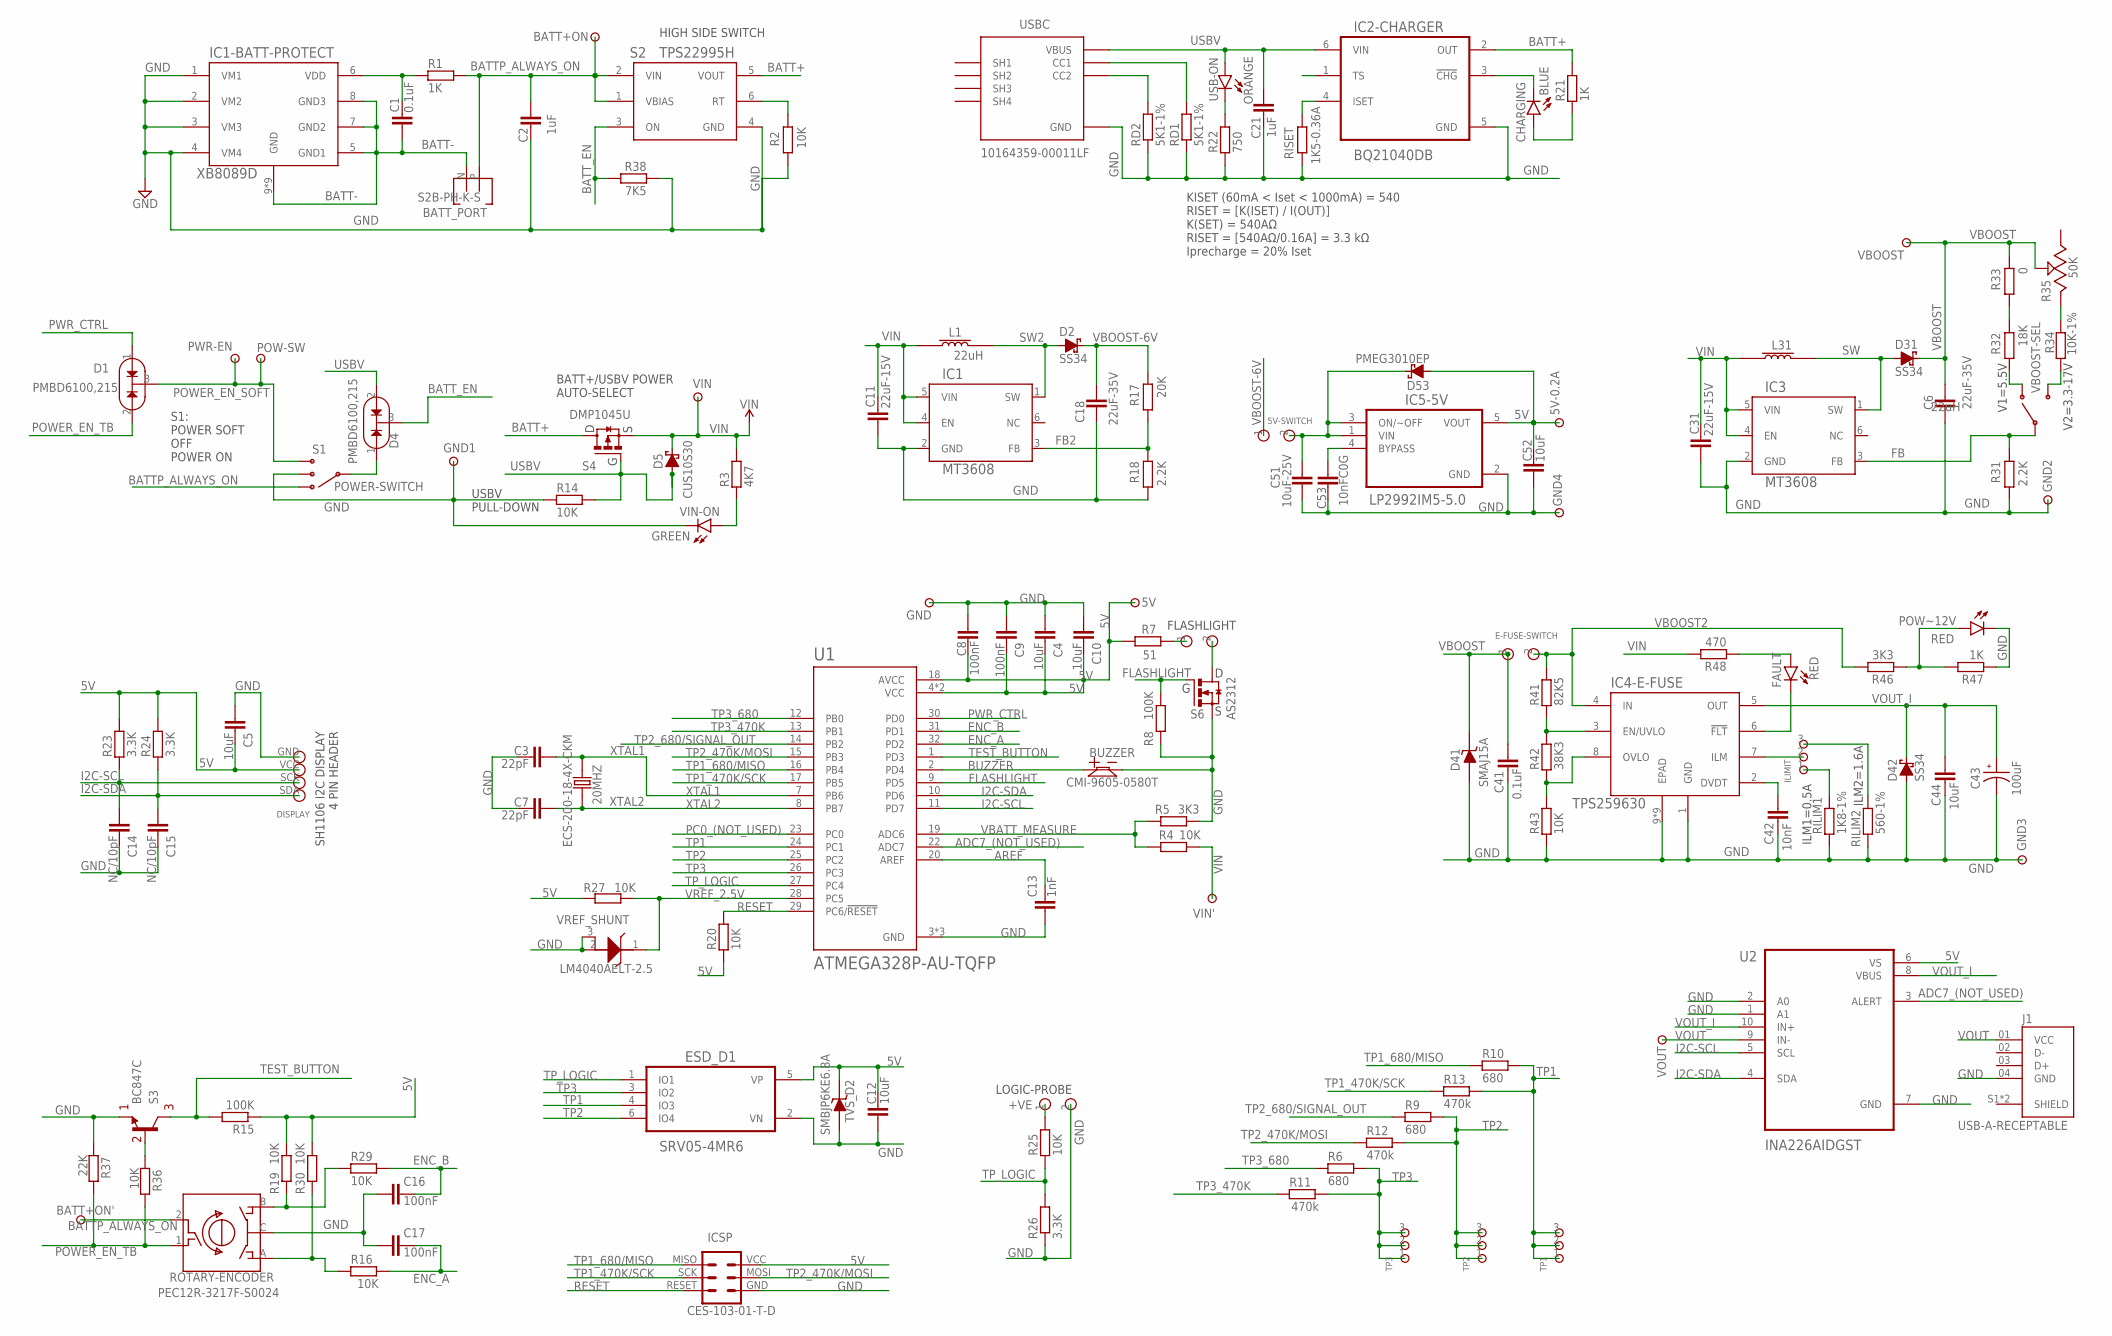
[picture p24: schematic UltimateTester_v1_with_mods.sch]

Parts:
5V, 5V-0.2A: TEST-POINT-TH; TEST-POINT-TH-1MM
5V-SWITCH: HEADER-2PIN-0.1"P
20MHZ: ECS-200-18-4X-CKM; XTAL_ECS-200-18-4X-CKM
BATT+ON: TEST-POINT-TH; TEST-POINT-TH-1MM
BATT+ON': TEST-POINT-TH; TEST-POINT-TH-1MM
BATT_PORT: S2B-PH-K-S
BUZZER: CMI-9605-0580T; BUZZER-ACTIVE-CMI-9605-0580T
C1, C41: 0.1uF; 0603
C2, C21: 1uF; 0603
C3, C7: 22pF; 0603
C4, C10, C12, C44, C52: 10uF; 0603
C5: 10uF; 1206
C6, C18: 22uF-35V; 1206
C8, C9, C16, C17: 100nF; 0603
C11, C31: 22uF-15V; 1206
C13: 1nF; 0603
C14, C15: NC/10pF; 0603
C42: 10nF; 0603
C43: 100uF; CAP_EEEFN1E101UP
C51: 10uF-25V; 0603
C53: 10nFC0G; 0603
CHARGING: BLUE; 0603-DIODE
D1, D4: PMBD6100,215; SOT-23-3
D2, D31, D42: SS34; SMA
D5: CUS10S30; SOD-323
D41: SMAJ15A; SMA
D53: PMEG3010EP; SOD-128
DISPLAY: DISPLAY-1.3"-SH1106-I2C
E-FUSE-SWITCH: HEADER-2PIN-0.1"P
ESD_D1: SRV05-4MR6; SOT-23-6
FAULT: RED; 0603-DIODE
FLASHLIGHT: HEADER-2PIN-0.2"P
GND, GND1, GND2, GND3, GND4: TEST-POINT-TH; TEST-POINT-TH-1MM
IC1, IC3: MT3608; SOT-23-6
IC1-BATT-PROTECT: XB8089D; SOIC-8-POWER-PAD
IC2-CHARGER: BQ21040DB; SOT-23-6
IC4-E-FUSE: TPS259630; SOIC-8-POWER-PAD
IC5-5V: LP2992IM5-5.0; SOT-23-5
ICSP: CES-103-01-T-D; HEADER-ICSP-0.1"P
ILIMIT: HEADER-3PIN-0.1"P
J1: USB-A-RECEPTABLE; AMPHENOL_87583-2010RLF
L1, L31: 22uH; INDUCTOR-SMRH74-220MT
LOGIC-PROBE: HEADER-2PIN-0.1"P
POW-SW: TEST-POINT-TH; TEST-POINT-TH-1MM
POW~12V: RED; 1206-DIODE
PWR-EN: TEST-POINT-TH; TEST-POINT-TH-1MM
R1, R21, R47: 1K; 0603
R2, R4, R14, R16, R19, R20, R25, R27, R29, R30, R36, R43: 10K; 0603
R3: 4K7; 0603
R5, R46: 3K3; 0603
R6, R9, R10: 680; 1206
R7: 51; 1206
R8, R15: 100K; 0603
R11, R12, R13: 470k; 1206
R17: 20K; 0603
R18, R31: 2.2K; 0603
R22: 750; 0603
R23, R24, R26: 3.3K; 0603
R32: 18K; 0603
R33: 0; 0603
R34: 10K-1%; 0603
R35: 50K; ROTARY-POTENTIOMETER-3386P
R37: 22K; 0603
R38: 7K5; 0603
R41: 82K5; 0603
R42: 38K3; 0603
R48: 470; 0603
RD1, RD2: 5K1-1%; 0603
RILIM1: 1K8-1%; 0603
RILIM2: 560-1%; 0603
RISET: 1K5-0.36A; 0603
ROTARY-ENCODER: PEC12R-3217F-S0024
S1: POWER-SWITCH; CSS-1310MC
S2: TPS22995H; SOT-23-6
S3: BC847C; SOT-23-3
S4: DMP1045U; SOT-23-3
S6: AS2312; SOT-23-3
TP1, TP2, TP3: HEADER-3PIN-0.1"P
TVS_D2: SMBJP6KE6.8A; DIOM5336X244N
U1: ATMEGA328P-AU-TQFP; TQFP32
U2: INA226AIDGST; SOP50P490X110-10N
USB-ON: ORANGE; 0603-DIODE
USBC: 10164359-00011LF; USB-C-RECEPTABLE-1016435900011LF
VBOOST: TEST-POINT-TH; TEST-POINT-TH-1MM
VBOOST-SEL: SLIDE-SWITCH-SPDT-VERTICLE-TH; SLW-883935-2A-D
VIN: TEST-POINT-TH; TEST-POINT-TH-1MM
VIN': TEST-POINT-TH; TEST-POINT-TH-1MM
VIN-ON: GREEN; 0603-DIODE
VOUT: TEST-POINT-TH; TEST-POINT-TH-1MM
VREF_SHUNT: LM4040AELT-2.5; SOT-23-3

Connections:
5V: 5V.P$1, 5V-0.2A.P$1, C4.1, C5.1, C8.2, C9.1, C10.1, C12.1, C52.2, D53.A, DISPLAY.VCC, ESD_D1.5 (VP), IC5-5V.5 (VOUT), ICSP.VCC (2), R7.1, R15.1, R19.2, R20.1, R23.2, R24.2, R27.1, R30.2, TVS_D2.C, U1.4 (VCC), U1.6 (VCC), U1.18 (AVCC), U2.6 (VS)
!FLT: FAULT.C, IC4-E-FUSE.6 (!FLT)
+VE: LOGIC-PROBE.1, R25.2
A: R16.1, R30.1, ROTARY-ENCODER.A
ADC7_(NOT_USED): U1.22 (ADC7), U2.3 (ALERT)
AREF: C13.1, U1.20 (AREF)
B: R19.1, R29.1, ROTARY-ENCODER.B
BATT+: IC2-CHARGER.2 (OUT), R21.2, S2.5 (VOUT), S4.3 (D)
BATT-: BATT_PORT.N, C1.2, IC1-BATT-PROTECT.5 (GND1), IC1-BATT-PROTECT.7 (GND2), IC1-BATT-PROTECT.8 (GND3), IC1-BATT-PROTECT.9 (GND), IC1-BATT-PROTECT.10 (GND), IC1-BATT-PROTECT.11 (GND), IC1-BATT-PROTECT.12 (GND), IC1-BATT-PROTECT.13 (GND), IC1-BATT-PROTECT.14 (GND), IC1-BATT-PROTECT.15 (GND), IC1-BATT-PROTECT.16 (GND), IC1-BATT-PROTECT.17 (GND)
BATTP_ALWAYS_ON: BATT+ON.P$1, BATT+ON'.P$1, BATT_PORT.P, C2.2, R1.2, ROTARY-ENCODER.2, S1.1, S2.1 (VBIAS), S2.2 (VIN)
BATT_EN: D4.3 (C), R38.2, S2.3 (ON)
BJT-B: R36.1, S3.1 (B)
BUZZER: BUZZER.P$1 (+), U1.2 (PD4)
BYP1: C53.2, IC5-5V.4 (BYPASS)
CHG: CHARGING.C, IC2-CHARGER.3 (!CHG)
DVDT: C42.2, IC4-E-FUSE.2 (DVDT)
EN/UVLO: IC4-E-FUSE.3 (EN/UVLO), R41.1, R42.2
ENC_A: C17.1, R16.2, U1.32 (PD2)
ENC_B: C16.1, R29.2, U1.31 (PD1)
FB: IC3.3 (FB), R31.1, VBOOST-SEL.C
FB2: IC1.3 (FB), R17.2, R18.1
FL+: FLASHLIGHT.1, R7.2
FL-: FLASHLIGHT.2, S6.3 (D)
FLASHLIGHT: R8.1, S6.1 (G), U1.9 (PD5)
GND: BUZZER.P$2 (-), C2.1, C3.1, C4.2, C5.2, C6.1, C7.1, C8.1, C9.2, C10.2, C11.1, C12.2, C13.2, C14.1, C15.1, C16.2, C17.2, C18.1, C21.1, C31.1, C41.1, C42.1, C43.2, C44.1, C51.1, C52.1, C53.1, D41.A, D42.A, DISPLAY.GND, ESD_D1.2 (VN), GND.P$1, GND1.P$1, GND2.P$1, GND3.P$1, GND4.P$1, IC1.2 (GND), IC1-BATT-PROTECT.1 (VM1), IC1-BATT-PROTECT.2 (VM2), IC1-BATT-PROTECT.3 (VM3), IC1-BATT-PROTECT.4 (VM4), IC2-CHARGER.5 (GND), IC3.2 (GND), IC4-E-FUSE.1 (GND), IC4-E-FUSE.9 (EPAD), IC4-E-FUSE.10 (EPAD), IC4-E-FUSE.11 (EPAD), IC4-E-FUSE.12 (EPAD), IC4-E-FUSE.13 (EPAD), IC4-E-FUSE.14 (EPAD), IC4-E-FUSE.15 (EPAD), IC4-E-FUSE.16 (EPAD), IC4-E-FUSE.17 (EPAD), IC5-5V.2 (GND), ICSP.GND (6), J1.04 (GND), LOGIC-PROBE.2, POW~12V.C1 (C), R2.2, R5.2, R8.2, R14.1, R18.2, R22.1, R26.1, R31.2, R37.1, R38.1, R43.1, R47.1, RD1.1, RD2.1, RILIM1.1, RILIM2.1, RISET.2, ROTARY-ENCODER.C, S1.2, S2.4 (GND), S3.2 (E), S6.2 (S), TVS_D2.A, U1.3 (GND), U1.5 (GND), U1.21 (GND), U2.1 (A1), U2.2 (A0), U2.7 (GND), USBC.A12 (GND), USBC.B12 (GND), VIN-ON.C, VREF_SHUNT.2 (A), VREF_SHUNT.3 (NC/A)
I2C-SCL: C14.2, DISPLAY.SCK, R23.1, U1.11 (PD7), U2.5 (SCL)
I2C-SDA: C15.2, DISPLAY.SDA, R24.1, U1.10 (PD6), U2.4 (SDA)
ILM: IC4-E-FUSE.7 (ILM), ILIMIT.2
ILM1: ILIMIT.1, RILIM1.2
ILM2: ILIMIT.3, RILIM2.2
ISET: IC2-CHARGER.4 (ISET), RISET.1
unnamed: RD2.2, USBC.B5 (CC2)
unnamed: RD1.2, USBC.A5 (CC1)
unnamed: R22.2, USB-ON.C
unnamed: R32.2, VBOOST-SEL.1
unnamed: R3.1, VIN-ON.A
unnamed: FAULT.A, R48.1
unnamed: CHARGING.A, R21.1
unnamed: R32.1, R33.2
unnamed: R34.2, VBOOST-SEL.2
unnamed: POW~12V.A1 (A), R46.1, R47.2
unnamed: R34.1, R35.3 (CCW)
OVLO: IC4-E-FUSE.8 (OVLO), R42.1, R43.2
PC0_(NOT_USED): U1.23 (PC0)
POWER_EN_SOFT: D1.3 (C), POW-SW.P$1, PWR-EN.P$1, S1.3
POWER_EN_TB: D1.2 (A2), R36.2, R37.2, ROTARY-ENCODER.1
PWR_CTRL: D1.1 (A1), U1.30 (PD0)
PWR_SW: D4.1 (A1), S1.C
RESET: ICSP.RESET (5), R20.2, U1.29 (PC6/!RESET)
RT: R2.1, S2.6 (RT)
SW: D31.A, IC3.1 (SW), L31.P$2
SW2: D2.A, IC1.1 (SW), L1.P$2
TEST_BUTTON: R15.2, S3.3 (C), U1.1 (PD3)
TP1: ESD_D1.4 (IO3), R10.2, R13.2, TP1.1, TP1.2, TP1.3, U1.24 (PC1)
TP1_470K/SCK: ICSP.SCK (3), R13.1, U1.17 (PB5)
TP1_680/MISO: ICSP.MISO (1), R10.1, U1.16 (PB4)
TP2: ESD_D1.6 (IO4), R9.2, R12.2, TP2.1, TP2.2, TP2.3, U1.25 (PC2)
TP2_470K/MOSI: ICSP.MOSI (4), R12.1, U1.15 (PB3)
TP2_680/SIGNAL_OUT: R9.1, U1.14 (PB2)
TP3: ESD_D1.3 (IO2), R6.2, R11.2, TP3.1, TP3.2, TP3.3, U1.26 (PC3)
TP3_470K: R11.1, U1.13 (PB1)
TP3_680: R6.1, U1.12 (PB0)
TP_LOGIC: ESD_D1.1 (IO1), R25.1, R26.2, U1.27 (PC4)
TS: IC2-CHARGER.1 (TS)
USBV: C21.2, D4.2 (A2), D5.A, IC2-CHARGER.6 (VIN), R14.2, S4.1 (G), USB-ON.A, USBC.A9 (VBUS), USBC.B9 (VBUS)
VBATT_MEASURE: R4.2, R5.1, U1.19 (ADC6)
VBOOST: C6.2, C41.2, D31.C, D41.C, E-FUSE-SWITCH.1, R33.1, R35.2 (S), VBOOST.P$1
VBOOST2: E-FUSE-SWITCH.2, IC4-E-FUSE.4 (IN), R41.2, R46.2
VBOOST-6V: 5V-SWITCH.1, C18.2, D2.C, R17.1
VBOOST-6V-: 5V-SWITCH.2, C51.2, D53.K (C), IC5-5V.1 (VIN), IC5-5V.3 (ON/~OFF)
VDD: C1.1, IC1-BATT-PROTECT.6 (VDD), R1.1
VIN: C11.2, C31.2, D5.C, IC1.4 (EN), IC1.5 (VIN), IC3.4 (EN), IC3.5 (VIN), L1.P$1, L31.P$1, R3.2, R4.1, R48.2, S4.2 (S), VIN.P$1, VIN'.P$1
VOUT: J1.01 (VCC), U2.9 (IN-), VOUT.P$1
VOUT_I: C43.1, C44.2, D42.C, IC4-E-FUSE.5 (OUT), U2.8 (VBUS), U2.10 (IN+)
VREF_2.5V: R27.2, U1.28 (PC5), VREF_SHUNT.1 (C)
XTAL1: 20MHZ.2, C3.2, U1.7 (PB6)
XTAL2: 20MHZ.1, C7.2, U1.8 (PB7)

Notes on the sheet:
HIGH SIDE SWITCH
KISET (60mA < Iset < 1000mA) = 540 RISET = [K(ISET) / I(OUT)] K(SET) = 540AΩ RISET = [540AΩ/0.16A] = 3.3 kΩ Iprecharge = 20% Iset
BATT+/USBV POWER AUTO-SELECT
USBV PULL-DOWN
S1: POWER SOFT OFF POWER ON
V1=5.5V
V2=3.3-17V
ILM2=1.6A
ILM1=0.5A

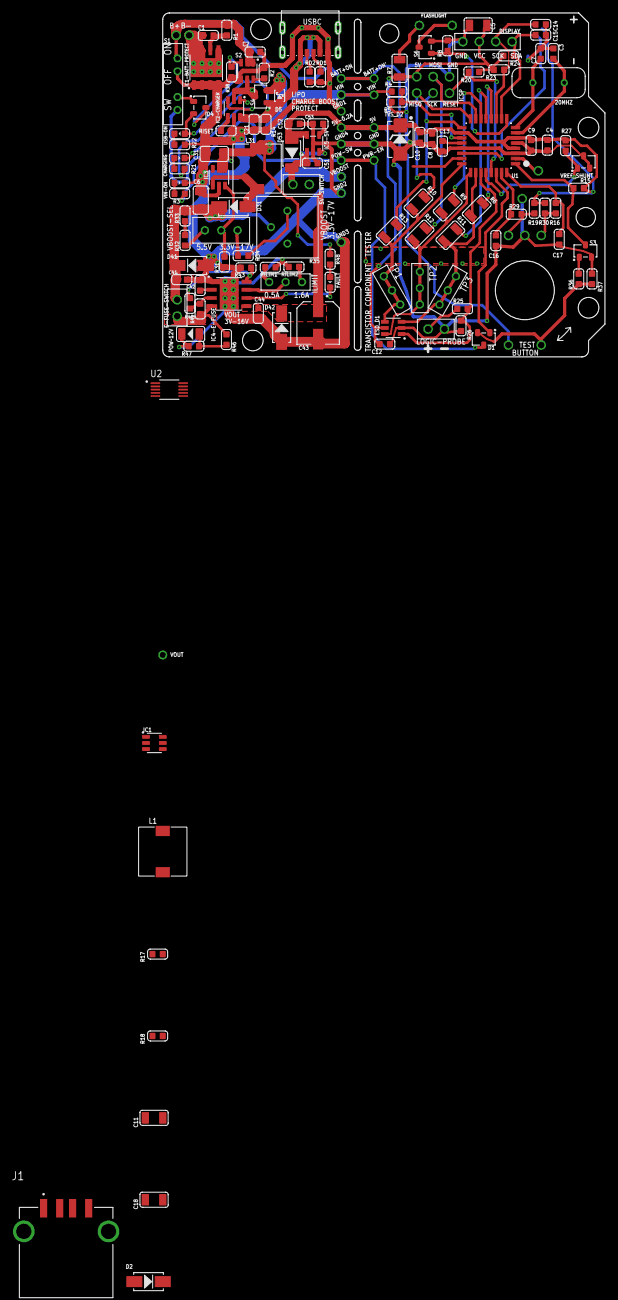
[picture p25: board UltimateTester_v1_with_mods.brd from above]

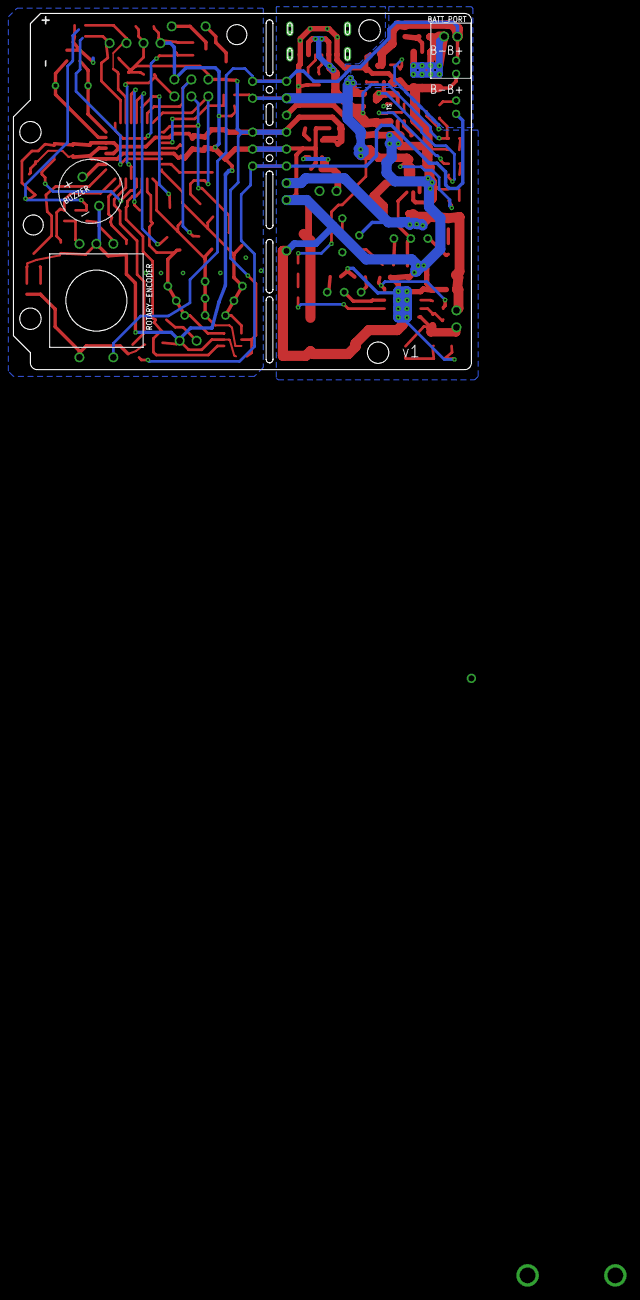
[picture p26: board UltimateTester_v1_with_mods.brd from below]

Board: 2 copper layers, 68.6 x 53.3 mm, 138 parts (2 on the bottom side), 75 nets.

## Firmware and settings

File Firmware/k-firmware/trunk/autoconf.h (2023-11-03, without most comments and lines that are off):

#if ((LCD_ST_TYPE == 7565) || (LCD_ST_TYPE == 1306) || (LCD_ST_TYPE == 7108) || (LCD_ST_TYPE == 7920) || (LCD_ST_TYPE == 7735) || (LCD_ST_TYPE == 9163) || (LCD_ST_TYPE == 9341))
 #if ((SCREEN_HEIGHT > 127) && (SCREEN_WIDTH > 255))
  #define ONE_B 16
 #else
  #define ONE_B 8
 #endif
 #define WITH_GRAPHICS 1
 #undef PAGES_PER_LINE
 #define PAGES_PER_LINE ((FONT_HEIGHT + 7) / 8)
 #undef LCD_LINES
 #define LCD_LINES ((SCREEN_HEIGHT/ONE_B) / PAGES_PER_LINE)
 #undef LCD_LINE_LENGTH
 #define LCD_LINE_LENGTH (SCREEN_WIDTH / (ONE_B/8) / FONT_WIDTH )
 #define TEXT_RIGHT_TO_ICON ((ICON_WIDTH + 16 + 5 + 7) / FONT_WIDTH)
#elif (LCD_ST_TYPE == 8812)
 #define ONE_B 8
 #define WITH_GRAPHICS 1
 #undef PAGES_PER_LINE
 #define PAGES_PER_LINE ((FONT_HEIGHT + 7) / 8)
 #undef LCD_LINES
 #define LCD_LINES ((SCREEN_HEIGHT/8) / PAGES_PER_LINE)
 #undef LCD_LINE_LENGTH
 #define LCD_LINE_LENGTH (SCREEN_WIDTH / FONT_WIDTH)
 #define TEXT_RIGHT_TO_ICON ((ICON_WIDTH + 16 + 5 + 7) / FONT_WIDTH)
#elif (LCD_ST_TYPE == 8814)
 #define ONE_B 8
 #define WITH_GRAPHICS 1
 #undef PAGES_PER_LINE
 #define PAGES_PER_LINE ((FONT_HEIGHT + 7) / 8)
 #undef LCD_LINES
 #define LCD_LINES ((SCREEN_HEIGHT/8) / PAGES_PER_LINE)
 #undef LCD_LINE_LENGTH
 #define LCD_LINE_LENGTH (SCREEN_WIDTH / FONT_WIDTH)
 #define TEXT_RIGHT_TO_ICON ((ICON_WIDTH + 16 + 5 + 7) / FONT_WIDTH)
#else
 #define TEXT_RIGHT_TO_ICON 0
  #define FONT_HEIGHT 8
#endif
 #define LCD_ST7565_H_OFFSET 0
 #define LCD_ST7565_Y_START  0
#if LCD_ST7565_Y_START >= SCREEN_HEIGHT
 #warning LCD_ST7565_Y_START is set higher than SCREEN_HEIGHT!
#endif
#ifndef LCD_LINE_LENGTH
 #define LCD_LINE_LENGTH 16
#endif
#if (defined(WITH_GRAPHICS) && (((SCREEN_WIDTH-(TEXT_RIGHT_TO_ICON*FONT_WIDTH))/FONT_WIDTH) < 9))
 #define LOW_H_SPACE 1
#else
 #define LOW_H_SPACE 0
#endif
#if (LCD_ST_TYPE != 7920)
#define lcd_refresh()
#endif
#if (LCD_LINES < 2)
 #warning LCD_LINES is not correctly set!
 #if (SCREEN_HEIGHT < 32)
  #warning SCREEN_HEIGHT is not correctly set!
 #endif
 #if (FONT_HEIGHT < 8)
  #warning FONT_HEIGHT is not correctly set!
 #endif
#endif
#if (LCD_LINES < 7) && defined(WITH_6_SELECTION_MENU)
 #warning Display has not sufficient count of lines for WITH_6_SELECTION_MENU !
 #undef WITH_6_SELECTION_MENU
#endif
#if (PROCESSOR_TYP == 8) || (PROCESSOR_TYP == 168) || (PROCESSOR_TYP == 328)
 #if FLASHEND > 0x1fff
  #ifdef TQFP_ADC6
    #undef TPext
    #define TPext ((1<<MUX2) | (1<<MUX1))
    #ifdef TQFP_ADC7
      #define TPex2 ((1<<MUX2) | (1<<MUX1) | (1<<MUX0))
    #endif
  #else
    #ifdef TQFP_ADC7
      #undef TPext
      #define TPext ((1<<MUX2) | (1<<MUX1) | (1<<MUX0))
    #else
     #if (WITH_UART != 0) && (WITH_VEXT != 0)
      #warning "WITH_VEXT deselected, PC3 is used for UART"
      #undef WITH_VEXT
     #endif
    #endif
  #endif
 #else
  #ifndef BAT_CHECK
    #ifdef TQFP_ADC6
      #undef TPext
      #define TPext ((1<<MUX2) | (1<<MUX1))
    #endif
    #ifdef TQFP_ADC7
      #undef TPext
      #define TPext ((1<<MUX2) | (1<<MUX1) | (1<<MUX0))
    #endif
    #if (WITH_UART == 1) && (TQFP_ADC6 == 0) && (TQFP_ADC7 == 0) && (WITH_VEXT != 0)
      #warning "WITH_VEXT deselected, PC3 is used for UART"
      #undef WITH_VEXT
    #endif
  #endif
 #endif
#endif
#if BAT_NUMERATOR < BAT_DENOMINATOR
 #warning "Wrong BAT_NUMERATOR / BAT_DENOMINATOR setting!"
#endif
#if EXT_NUMERATOR < EXT_DENOMINATOR
 #warning "Wrong EXT_NUMERATOR / EXT_DENOMINATOR setting!"
#endif
  #define R_L_VAL 6800          // standard value 680 Ohm, multiplied by 10 for 0.1 Ohm resolution
  #define R_H_VAL 47000         // standard value 470000 Ohm, multiplied by 10, divided by 100
#if R_ANZ_MESS < ANZ_MESS
 #undef R_ANZ_MESS
 #define R_ANZ_MESS ANZ_MESS
#endif
#if U_SCALE < 1
 #undef U_SCALE
 #define U_SCALE 1
#endif
#if U_SCALE > 4
 #undef U_SCALE
 #define U_SCALE 4
#endif
 #define REF_L_KORR 50
#ifdef USE_EEPROM
 #define MEM_TEXT EEMEM
 #define lcd_MEM_string(a)  lcd_fix_string(a)
 #if E2END > 0X1FF
  #define MEM2_TEXT EEMEM
  #define MEM2_read_byte(a)  eeprom_read_byte(a)
  #define MEM2_read_word(a)  eeprom_read_word(a)
  #define lcd_MEM2_string(a)  lcd_fix_string(a)
  #define use_lcd_pgm
 #else
  #define MEM2_TEXT PROGMEM
  #define MEM2_read_byte(a)  pgm_read_byte(a)
  #define MEM2_read_word(a)  pgm_read_word(a)
  #define lcd_MEM2_string(a)  lcd_pgm_string(a)
  #define use_lcd_pgm
 #endif
 #define MEM_EEPROM
 #define MEM_read_word(a)  eeprom_read_word(a)
 #define MEM_read_byte(a)  eeprom_read_byte(a)
#else
 #define MEM_TEXT PROGMEM
 #define lcd_MEM_string(a)  lcd_pgm_string(a)
 #define MEM2_TEXT PROGMEM
 #define MEM_read_word(a)  pgm_read_word(a)
 #define MEM_read_byte(a)  pgm_read_byte(a)
 #define MEM2_read_byte(a)  pgm_read_byte(a)
 #define MEM2_read_word(a)  pgm_read_word(a)
 #define lcd_MEM2_string(a)  lcd_pgm_string(a)
 #define use_lcd_pgm
#endif
#if FLASHEND > 0X1FFF
 #define ACALL call
#else
 #define ACALL rcall
#endif
#if PROCESSOR_TYP == 168
  #define MCU_STATUS_REG MCUCR
  #define ADC_COMP_CONTROL ADCSRB
  #define TI1_INT_FLAGS TIFR1
  #define DEFAULT_BAND_GAP 1070
 #if R_H_VAL == 10000
  #define DEFAULT_RH_FAKT 4022      // mega168 1101 mV, 100.0 kOhm
 #else
  #define DEFAULT_RH_FAKT  856      // mega168 1101 mV, 470.0 kOhm
 #endif
  #define LONG_HFE
  #define PIN_RM 196
  #define PIN_RP 221
  #define CC0 36
  #define COMP_SLEW1 4000
  #define COMP_SLEW2 220
  #define C_NULL CC0+CABLE_CAP+(COMP_SLEW1 / (CC0 + CABLE_CAP + COMP_SLEW2))
  #define MUX_INT_REF 0x0e
#elif PROCESSOR_TYP == 328
  #define MCU_STATUS_REG MCUCR
  #define ADC_COMP_CONTROL ADCSRB
  #define TI1_INT_FLAGS TIFR1
  #define DEFAULT_BAND_GAP 1070
 #if R_H_VAL == 10000
  #define DEFAULT_RH_FAKT 4022      // mega328 1101 mV, 100.0 kOhm
 #else
  #define DEFAULT_RH_FAKT  856      // mega328 1101 mV, 470.0 kOhm
 #endif
  #define LONG_HFE
  #define PIN_RM 200
  #define PIN_RP 220
  #define CC0 36
  #define COMP_SLEW1 4000
  #define COMP_SLEW2 180
  #define C_NULL CC0+CABLE_CAP+(COMP_SLEW1 / (CC0 + CABLE_CAP + COMP_SLEW2))
  #define MUX_INT_REF 0x0e
#elif PROCESSOR_TYP == 644
  #define WITH_ROTARY_CHECK
  #define WITH_UJT
  #define WITH_PUT
  #define MCU_STATUS_REG MCUCR
  #define ADC_COMP_CONTROL ADCSRB
  #define TI1_INT_FLAGS TIFR1
  #define DEFAULT_BAND_GAP 1070
 #if R_H_VAL == 10000
  #define DEFAULT_RH_FAKT 4022      // mega1280 1101 mV, 100.0 kOhm
 #else
  #define DEFAULT_RH_FAKT  856      // mega1280 1101 mV, 470.0 kOhm
 #endif
  #define LONG_HFE
  #define PIN_RM 200
  #define PIN_RP 220
  #define CC0 36
  #define COMP_SLEW1 4000
  #define COMP_SLEW2 180
  #define C_NULL CC0+CABLE_CAP+(COMP_SLEW1 / (CC0 + CABLE_CAP + COMP_SLEW2))
  #define MUX_INT_REF 0x1e
#elif PROCESSOR_TYP == 1280
 #ifndef WITH_ROTARY_CHECK
  #define WITH_ROTARY_CHECK
 #endif
  #define MCU_STATUS_REG MCUCR
  #define ADC_COMP_CONTROL ADCSRB
  #define TI1_INT_FLAGS TIFR1
  #define DEFAULT_BAND_GAP 1070
 #if R_H_VAL == 10000
  #define DEFAULT_RH_FAKT 4022      // mega1280 1101 mV, 100.0 kOhm
 #else
  #define DEFAULT_RH_FAKT  856      // mega1280 1101 mV, 470.0 kOhm
 #endif
  #define LONG_HFE
  #define PIN_RM 200
  #define PIN_RP 220
  #define CC0 36
  #define COMP_SLEW1 4000
  #define COMP_SLEW2 180
  #define C_NULL CC0+CABLE_CAP+(COMP_SLEW1 / (CC0 + CABLE_CAP + COMP_SLEW2))
  #define MUX_INT_REF 0x1e
#else
  #define MCU_STATUS_REG MCUCSR
  #define ADC_COMP_CONTROL SFIOR
  #define TI1_INT_FLAGS TIFR
  #define DEFAULT_BAND_GAP 1298		//mega8 1298 mV
 #if R_H_VAL == 10000
  #define DEFAULT_RH_FAKT 3328      // mega8 1298 mV, 100.0 kOhm
 #else
  #define DEFAULT_RH_FAKT  740      // mega8 1250 mV, 470.0 kOhm
 #endif
  #define LONG_HFE
  #define PIN_RM 196
  #define PIN_RP 240
  #define CC0 27
  #define COMP_SLEW1 0
  #define COMP_SLEW2 33
  #define C_NULL CC0+CABLE_CAP+(COMP_SLEW1 / (CC0 + CABLE_CAP + COMP_SLEW2))
  #define MUX_INT_REF 0x0e
  #define INHIBIT_SLEEP_MODE
  #warning "SLEEP_MODE not possible with mega8"
#endif
 #define REF_R_KORR 0
 #define REF_C_KORR 0
#ifdef POWER_OFF
 #if (POWER_OFF+0) > 2
  #define OFF_WAIT_TIME SHORT_WAIT_TIME
 #else
  #define OFF_WAIT_TIME (LONG_WAIT_TIME - 1)
 #endif
#else
 #define OFF_WAIT_TIME  (LONG_WAIT_TIME - 1)
#endif
#define F_ADC 200000
#if F_CPU/F_ADC <= 2
 #define TICS_PER_ADC_CLOCK 2
 #define AUTO_CLOCK_DIV ((0<<ADPS2) | (0<<ADPS1) | (1<<ADPS0))
#elif F_CPU/F_ADC <= 4
 #define TICS_PER_ADC_CLOCK 4
 #define AUTO_CLOCK_DIV ((0<<ADPS2) | (1<<ADPS1) | (0<<ADPS0))
#elif F_CPU/F_ADC <= 8
 #define TICS_PER_ADC_CLOCK 8
 #define AUTO_CLOCK_DIV ((0<<ADPS2) | (1<<ADPS1) | (1<<ADPS0))
#elif F_CPU/F_ADC <= 16
 #define TICS_PER_ADC_CLOCK 16
 #define AUTO_CLOCK_DIV ((1<<ADPS2) | (0<<ADPS1) | (0<<ADPS0))
#elif F_CPU/F_ADC <= 32
 #define TICS_PER_ADC_CLOCK 32
 #define AUTO_CLOCK_DIV ((1<<ADPS2) | (0<<ADPS1) | (1<<ADPS0))
#elif F_CPU/F_ADC <= 64
 #define TICS_PER_ADC_CLOCK 64
 #define AUTO_CLOCK_DIV ((1<<ADPS2) | (1<<ADPS1) | (0<<ADPS0))
#else
 #define TICS_PER_ADC_CLOCK 128
 #define AUTO_CLOCK_DIV ((1<<ADPS2) | (1<<ADPS1) | (1<<ADPS0))
#endif
#ifndef PIN_RP
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

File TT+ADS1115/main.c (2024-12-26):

#include <avr/io.h>
#include <util/delay.h>
#include <avr/sleep.h>
#include <stdlib.h>
#include <string.h>
#include <avr/eeprom.h>
#include <math.h>

#include "settings.h"
#include "lcd.h"
#include "ads1115.h"

//Program start
int main(void) {
		
	RST_PORT = (1<<RST_PIN);	// enable Pullup for Reset button
	uint8_t tmp;
	//ADC-Init
	ADCSRA = (1<<ADEN) | (1<<ADPS1) | (1<<ADPS0);	//Enable ADC, set Prescaler to 8

	lcd_init();
		
	// Entry point when start button is pressed during Operation 
	start:
	PartFound = PART_NONE;
	tmpPartFound = PART_NONE;
	NumOfDiodes = 0;
	PartReady = 0;
	PartMode = 0;

	lcd_clear();
			
	//  Begin testing sequence
	lcd_eep_string(TestRunning);	// print the String: "Test running"
	//  check All the 6 possible combinations  for the 3 test probes
	CheckPins(TP1, TP2, TP3);
	CheckPins(TP1, TP3, TP2);
	CheckPins(TP2, TP1, TP3);
	CheckPins(TP2, TP3, TP1);
	CheckPins(TP3, TP2, TP1);
	CheckPins(TP3, TP1, TP2);

	// Done , now comes the evaluation
	GetGateThresholdVoltage();
	lcd_clear();
	//----------------------------------------------
	if(PartFound == PART_DIODE) {
		if(NumOfDiodes == 1) {
			//Standard-Diode
			lcd_eep_string(Diode);	//"Diode: "
			lcd_eep_string(Anode);
			lcd_data(diodes[0].Anode + 49);
			lcd_string(";K=");
			lcd_data(diodes[0].Cathode + 49);
			Line2();	//
			lcd_eep_string(Uf);	//"Uf = "
			lcd_string(itoa(diodes[0].Voltage, outval, 10));
			lcd_eep_string(mV);
			goto end;
		} else if(NumOfDiodes == 2) {
		//dual diode
			if(diodes[0].Anode == diodes[1].Anode) {
				//Common Anode
				lcd_eep_string(DualDiode);	//Dual diode
				lcd_string("CA");
				Line2(); //2. Zeile
				lcd_eep_string(Anode);
				lcd_data(diodes[0].Anode + 49);
				lcd_eep_string(K1);	//";K1="
				lcd_data(diodes[0].Cathode + 49);
				lcd_eep_string(K2);	//";K2="
				lcd_data(diodes[1].Cathode + 49);
				goto end;
			} else if(diodes[0].Cathode == diodes[1].Cathode) {
				//Common Cathode
				lcd_eep_string(DualDiode);	//Dual diode
				lcd_string("CC");
				Line2(); //
				lcd_string("K=");
				lcd_data(diodes[0].Cathode + 49);
				lcd_eep_string(A1);		//";A1="
				lcd_data(diodes[0].Anode + 49);
				lcd_eep_string(A2);		//";A2="
				lcd_data(diodes[1].Anode + 49);
				goto end;
			} else if ((diodes[0].Cathode == diodes[1].Anode) && (diodes[1].Cathode == diodes[0].Anode)) {
				//Antiparallel
				lcd_eep_string(TwoDiodes);	//2 Diodes
				Line2(); //
				lcd_eep_string(Antiparallel);	//Antiparallel
				goto end;
			}
		} else if(NumOfDiodes == 3) {
			// series connection from 2 diodes is recognized as 3 diodes 
			b = 3;
			c = 3;
			/* Check for a possible connection of 2 diodes
			For this 2 of the cathodes and 2 of the anodes must match .
			This is because the diodes are recognized as 2 single ones and ADITIONALLY as one big diode 
			*/
			if((diodes[0].Anode == diodes[1].Anode) || (diodes[0].Anode == diodes[2].Anode)) b = diodes[0].Anode;
			if(diodes[1].Anode == diodes[2].Anode) b = diodes[1].Anode;

			if((diodes[0].Cathode == diodes[1].Cathode) || (diodes[0].Cathode == diodes[2].Cathode)) c = diodes[0].Cathode;
			if(diodes[1].Cathode == diodes[2].Cathode) c = diodes[1].Cathode;
			if((b<3) && (c<3)) {
				lcd_eep_string(TwoDiodes);//2 Diodes
				Line2(); //
				lcd_eep_string(InSeries); //"in Series A="
				lcd_data(b + 49);
				lcd_string(";K=");
				lcd_data(c + 49);
				goto end;
			}
		}
	} 
	//---------------------------------------------
	else if (PartFound == PART_TRANSISTOR) {
		if(PartReady == 0) {	// 2nd test never made, e.g. a transistor with protection diode.
			hfe[1] = hfe[0];
			uBE[1] = uBE[0];
		}
		if((hfe[0]>hfe[1])) {	// If the amplification factor was higher in the first test: swap C and E!
			hfe[1] = hfe[0];
			uBE[1] = uBE[0];
			tmp = c;
			c = e;
			e = tmp;
		}

		if(PartMode == PART_MODE_NPN) {
			lcd_eep_string(NPN);
		} else {
			lcd_eep_string(PNP);
		}
		lcd_eep_string(bstr);	//B=
		lcd_data(b + 49);
		lcd_eep_string(cstr);	//;C=
		lcd_data(c + 49);
		lcd_eep_string(estr);	//;E=
		lcd_data(e + 49);
		Line2(); //2. Zeile
		// calculate amplification factor 
		//hFE =  emitter current / base current
		lhfe = hfe[1];
		lhfe *= RH_RL_RATIO;	// Ratio of high to low resistance
		if(uBE[1]<11) uBE[1] = 11;
		lhfe /= uBE[1];
		hfe[1] = (unsigned int) lhfe;
		lcd_eep_string(hfestr);	//"hFE="
		lcd_string(utoa(hfe[1], outval, 10));
		goto end;
	} 
	//-----------------------------------------
	else if (PartFound == PART_FET) {	//JFET or MOSFET
		if(PartMode&1) {	//N-Kanal
			lcd_data('N');
		} else {
			lcd_data('P');	//P-Kanal
		}
		if((PartMode==PART_MODE_N_D_MOS) || (PartMode==PART_MODE_P_D_MOS)) {
			lcd_eep_string(dmode);	//"-D"
			lcd_eep_string(mosfet);	//"-MOS"
		} else {
			if((PartMode==PART_MODE_N_JFET) || (PartMode==PART_MODE_P_JFET)) {
				lcd_eep_string(jfet);	//"-JFET"
			} else {
				lcd_eep_string(emode);	//"-E"
				lcd_eep_string(mosfet);	//"-MOS"
			}
		}

		Line2(); //
		lcd_eep_string(gds);	//"GDS="
		lcd_data(b + 49);
		lcd_data(c + 49);
		lcd_data(e + 49);
		lcd_data(' ');	// space
		if(PartMode < 3) {	// enrichment MOSFET
			lcd_eep_string(vt);
			lcd_string(outval);	// : gate threshold voltage , was previously determined
			lcd_data('m');
		}
		goto end;
	} 
	//----------------------------------------------
	else if (PartFound == PART_THYRISTOR) {
		lcd_eep_string(Thyristor);	//"Thyristor"
		Line2(); //
		lcd_string("GAK=");
		lcd_data(b + 49);
		lcd_data(c + 49);
		lcd_data(e + 49);
		goto end;
	} 
	//----------------------------------------------
	else if (PartFound == PART_TRIAC) {
		lcd_eep_string(Triac);	//"Triac"
		Line2(); //  goto line2
		lcd_eep_string(Gate);
		lcd_data(b + 49);
		lcd_eep_string(A1);		//";A1="
		lcd_data(e + 49);
		lcd_eep_string(A2);		//";A2="
		lcd_data(c + 49);
		goto end;

	}
	// Test failed
	lcd_eep_string(TestFailed1); //None ,unknown . Or
	Line2(); //
	lcd_eep_string(TestFailed2); // defective
	lcd_eep_string(Bauteil);
	
	//----------------------------------------------
	end:
	while(!(RST_PIN_REG & (1<<RST_PIN)));		// wait until button is released
	_delay_ms(200);
		
	// endless loop
	while(1) {
		// only reached, if the automatic Shutdown has not been installed 
		if(!(RST_PIN_REG & (1<<RST_PIN))) goto start; 
	}
	return 0;
} // END of MAIN()

//=========================================================================
	/*
	function for Testing the Properties of the component with the specified pin assignment
	Parameter:
	HighPin: Pin that Starts at H, logic 1 (connected to Vcc).  
	LowPin: Pin that Starts at L, logic 0 (connected to GND via R_L).
	TristatePin: Pin that Starts input Hi-Z, is put both H and L during the tests.
	*/
void CheckPins(uint8_t HighPin, uint8_t LowPin, uint8_t TristatePin) {
	unsigned int adcv[6];
	uint8_t tmpval, tmpval2;

	// Set pins
	tmpval = (LowPin * 2);			// necessary because of the arrangement of the resistances
									// R_L of TPn is connected to PB(n*2) where n = 0, 1 or 2.
									// TP0 => R_L connected to PB0, TP1 => R_L connected to PB2 ... 
	R_DDR = (1<<tmpval);			// Low pin as output and connected via R_L to ground
	R_PORT = 0;
	ADC_DDR = (1<<HighPin);			// High-Pin as output
	ADC_PORT = (1<<HighPin);		// High-Pin connected to Vcc
	_delay_ms(5);
	// For Some MOSFETs the gate (tristate pin) must be discharged first
	//N-Kanal:
	DischargePin(TristatePin,0);
	// measure voltage at low pin
	adcv[0] = ReadADC(LowPin);
	if(adcv[0] < 521) goto next;	// Does the component close now?
	// otherwise : discharge for P channel (gate tied to Vcc)
	DischargePin(TristatePin,1);
	// measure voltage at the low pin
	adcv[0] = ReadADC(LowPin);

	next:
	if(adcv[0] < 521) {	// If the component has no continuity between HighPin and LowPin
		tmpval2 = (TristatePin * 2);	// necessary because of the arrangement of the resistances
		R_DDR |= (1<<tmpval2);			// Tristate pin via R_L to ground, to test for pnp
		_delay_ms(2);
		adcv[0] = ReadADC(LowPin);		// measure the Voltage at the Low pin
		if(adcv[0] > 18246) {
			// Component conducts => pnp transistor or the like
			// measure Amplification factor in both directions 
			R_DDR = (1<<tmpval);		// Tristate-Pin (base) hi-Z
			tmpval2++;
			R_DDR |= (1<<tmpval2);		// Tristate pin (base) through R_H to ground

			_delay_ms(10);
			adcv[0] = ReadADC(LowPin);		// measure Voltage at the low pin (presumed collector) 
			adcv[2] = ReadADC(TristatePin);	// measure base Voltage
			R_DDR = (1<<tmpval);		// Tristate-Pin (base) hi-Z
			// Check if test has been done before
			if((PartFound == PART_TRANSISTOR) || (PartFound == PART_FET)) PartReady = 1;
			hfe[PartReady] = adcv[0];
			uBE[PartReady] = adcv[2];

			if(adcv[2] > 5213) {
				if(PartFound != PART_THYRISTOR) {
					PartFound = PART_TRANSISTOR;	// PNP transistor found (base is "pulled up")
					PartMode = PART_MODE_PNP;
				}
			} else {
				if(PartFound != PART_THYRISTOR) {
				 	PartFound = PART_FET;			// P- channel MOSFET found (gate is NOT "pulled up")
					PartMode = PART_MODE_P_E_MOS;
				}
			}
			if(PartFound != PART_THYRISTOR) {
				b = TristatePin;
				c = LowPin;
				e = HighPin;
			}
		}

		// Tristate (assumed base) to Vcc, to test for npn
		ADC_PORT = 0;					// Low-Pin connected to ground
		tmpval = (TristatePin * 2);		// necessary because of the arrangement of the resistances
		tmpval2 = (HighPin * 2);		// necessary because of the arrangement of the resistances
		R_DDR = (1<<tmpval) | (1<<tmpval2);			//High-Pin and Tristate-Pin outputs
		R_PORT = (1<<tmpval) | (1<<tmpval2);		//High-Pin and Tristate-Pin connected via R_L to Vcc
		ADC_DDR = (1<<LowPin);			//Low-Pin output
		_delay_ms(10);
		adcv[0] = ReadADC(HighPin);		// measure the voltage at the High-Pin
		if(adcv[0] < 13033) {
			if(PartReady==1) goto testend;
			//  Component conducts => npn transistor or the like

			// Gate discharged
			R_PORT = (1<<tmpval2);			//Tristate-Pin (Gate) via R_L to GND
			_delay_ms(10);
			R_DDR = (1<<tmpval2);			//Tristate-Pin (Gate) Hi-Z
			//Test of Thyristor
			_delay_ms(5);
			adcv[1] = ReadADC(HighPin);		// measure Voltage at the high pin (presumed anode) again
			
			R_PORT = 0;						//High-Pin (presumed Anode) to GND
			_delay_ms(5);
			R_PORT = (1<<tmpval2);			//High-Pin (presumed Anode) back to Vcc
			_delay_ms(5);
			adcv[2] = ReadADC(HighPin);		// measure Voltage at the high pin (presumed anode) again
			if((adcv[1] < 13033) && (adcv[2] > 23459)) {// After switching off the holding current, tha thyristor must close 
				// was switched before Switching off the trigger current and still switched although gate off => thyristor
				PartFound = PART_THYRISTOR;
				//Test of Triac
				R_DDR = 0;
				R_PORT = 0;
				ADC_PORT = (1<<LowPin);	//Low-Pin connected to Vcc
				_delay_ms(5);
				R_DDR = (1<<tmpval2);	//HighPin connected via R_L to GND
				_delay_ms(5);
				if(ReadADC(HighPin) > 1303) goto savenresult;	// measure voltage at high pin (presumed A2); if too high : component is now conducting => not a triac
				R_DDR |= (1<<tmpval);	// Gate connected also via R_L to GND => triac should fire
				_delay_ms(5);
				if(ReadADC(TristatePin) < 5213) goto savenresult; // measure voltage at tristate pin (presumed gate) ; abort if voltage too low 
				if(ReadADC(HighPin) < 3910) goto savenresult; // Component does not conduct now => not a triac => abort
				R_DDR = (1<<tmpval2);	//TristatePin (Gate) Hi-Z again
				_delay_ms(5);
				if(ReadADC(HighPin) < 3910) goto savenresult; // Component not conducting after switching off the gate current => not a triac => abort
				R_PORT = (1<<tmpval2);	//HighPin via R_L to Vcc => holding current off
				_delay_ms(5);
				R_PORT = 0;				//HighPin again via R_L to GND; Triac should now inhibit
				_delay_ms(5);
				if(ReadADC(HighPin) > 1303) goto savenresult;	//measure voltage at High-Pin (presumed A2) agin, if too high: component is now conducting => not a triac
				PartFound = PART_TRIAC;
				PartReady = 1;
				goto savenresult;
			}
			//Test of Transistor or MOSFET
			tmpval++;
			R_DDR |= (1<<tmpval);		//Tristate-Pin (Base) as output
			R_PORT |= (1<<tmpval);		//Tristate-Pin (Base) via R_H to Vcc
			_delay_ms(50);
			adcv[0] = ReadADC(HighPin);		// measure voltage at High-Pin (presumed collector)
			adcv[2] = ReadADC(TristatePin);	// measure base voltage
			R_PORT = (1<<tmpval2);			//Tristate-Pin (Base) Hi-Z
			R_DDR = (1<<tmpval2);			//Tristate-Pin (Base) as input

			if((PartFound == PART_TRANSISTOR) || (PartFound == PART_FET)) PartReady = 1;	// check if test has been balready done
			hfe[PartReady] = 26666 - adcv[0];
			uBE[PartReady] = 26666 - adcv[2];
			if(adcv[2] < 13033) {
				PartFound = PART_TRANSISTOR;	//NPN-Transistor found (base is pulled "down")
				PartMode = PART_MODE_NPN;
			} else {
				PartFound = PART_FET;			// N- channel MOSFET found (gate is NOT pulled "down")
				PartMode = PART_MODE_N_E_MOS;
			}
			savenresult:
			b = TristatePin;
			c = HighPin;
			e = LowPin;
		}
		ADC_DDR = 0;
		ADC_PORT = 0;
		// Done (ready)
	} else {	// passage
		// Test for N-JFET or self-conducting N-MOSFET
		R_DDR |= (2<<(TristatePin*2));	//Tristate-Pin (presumed Gate) via R_H to GND
		_delay_ms(20);
		adcv[0] = ReadADC(LowPin);		// Measure voltage at presumed "source"
		R_PORT |= (2<<(TristatePin*2));	//Tristate-Pin (presumed Gate) via R_H to Vcc
		_delay_ms(20);
		adcv[1] = ReadADC(LowPin);		// measure Voltage at presumed "source" again 
		// If it is	a Self-conducting MOSFET or JFET  adcv[1] should be > adcv[0] 
		if(adcv[1]>(adcv[0]+2606)) {
			// measure voltage at the gate, to Distinguish between MOSFET and JFET
			ADC_PORT = 0;
			ADC_DDR = (1<<LowPin);	//Low-Pin fixed to GND
			tmpval = (HighPin * 2);		// necessary because of the arrangement of the resistances
			R_DDR |= (1<<tmpval);			//High-Pin as output
			R_PORT |= (1<<tmpval);			//High-Pin via R_L to Vcc
			_delay_ms(20);
			adcv[2] = ReadADC(TristatePin);		// Measure voltage at presumed gate
			if(adcv[2]>20853) {	//MOSFET
				PartFound = PART_FET;			//N-Kanal-MOSFET
				PartMode = PART_MODE_N_D_MOS;	// Depletion MOSFET
			} else {	// JFET (pn - junction between G and S leads)
				PartFound = PART_FET;			//N-Kanal-JFET
				PartMode = PART_MODE_N_JFET;
			}
			PartReady = 1;
			b = TristatePin;
			c = HighPin;
			e = LowPin;
		}
		ADC_PORT = 0;

		// Test for P-JFET or self-conducting P-MOSFET
		ADC_DDR = (1<<LowPin);	//Low-Pin (presumed Drain) fixed to GND, Tristate-Pin (presumed Gate) is still connected to Vcc via R_H 
		tmpval = (HighPin * 2);			// necessary because of the arrangement of the resistances
		R_DDR |= (1<<tmpval);			//High-Pin as output
		R_PORT |= (1<<tmpval);			//High-Pin via R_L to Vcc
		_delay_ms(20);
		adcv[0] = ReadADC(HighPin);		// Measure voltage at presumed "source"
		R_PORT = (1<<tmpval);			//Tristate-Pin (presumed Gate) via R_H to GND
		_delay_ms(20);
		adcv[1] = ReadADC(HighPin);		// measure Voltage at presumed "source" again 
		// If it is a Self-conducting P-MOSFET or P-JFET adcv[0] should be > adcv[1].
		if(adcv[0]>(adcv[1]+2606)) {
			// measure voltage at the gate, to Distiguish between MOSFET and JFET
			ADC_PORT = (1<<HighPin);	//High-Pin fixed to Vcc
			ADC_DDR = (1<<HighPin);		//High-Pin as output
			_delay_ms(20);
			adcv[2] = ReadADC(TristatePin);		// Measure voltage at presumed gate
			if(adcv[2]<5213) {	//MOSFET
				PartFound = PART_FET;			//P-Kanal-MOSFET
				PartMode = PART_MODE_P_D_MOS;	// Depletion MOSFET
			} else {	// JFET (pn - junction between G and S leads)
				PartFound = PART_FET;			//P-Kanal-JFET
				PartMode = PART_MODE_P_JFET;
			}
			PartReady = 1;
			b = TristatePin;
			c = LowPin;
			e = HighPin;
		}

		tmpval2 = (2<<(2*HighPin));	//R_H
		tmpval = (1<<(2*HighPin));	//R_L
		ADC_PORT = 0;
		//Test of Diode
		ADC_DDR = (1<<LowPin);	//Low-Pin fidx to GND, High-Pin is still connecte to Vcc via R_L 
		DischargePin(TristatePin,1);	// discharge for P-Kanal-MOSFET
		_delay_ms(5);
		adcv[0] = ReadADC(HighPin) - ReadADC(LowPin);
		R_DDR = tmpval2;	//High-Pin via R_H to Vcc
		R_PORT = tmpval2;
		_delay_ms(5);
		adcv[2] = ReadADC(HighPin) - ReadADC(LowPin);
		R_DDR = tmpval;	//High-Pin via R_L to Vcc
		R_PORT = tmpval;
		DischargePin(TristatePin,0);	// discharge for N-Kanal-MOSFET
		_delay_ms(5);
		adcv[1] = ReadADC(HighPin) - ReadADC(LowPin);
		R_DDR = tmpval2;	//High-Pin via R_H  to Vcc
		R_PORT = tmpval2;
		_delay_ms(5);
		adcv[3] = ReadADC(HighPin) - ReadADC(LowPin);
		/*  Without discharging, false detections may occur since the gate of a mosfet may still be charged.
			The additional Measurement with the "big" resistance R_H is performed to detect antiparallel diodes.
			A diode has a forward pass voltage that is relativily independent of forward current
			For a resistor the voltage drop changes strongly (lineraly) with the current
		*/
		if(adcv[0] > adcv[1]) {
			adcv[1] = adcv[0];	// the higher value wins
			adcv[3] = adcv[2];
		}

		if((adcv[1] > 782) && (adcv[1] < 24763)) { // voltage is above 0.15V and below 4.64V => Ok
			// specify diode only if no other Component has been found yet. 
			// Otherwise there would be problems with transistors with protection diode
			if((PartFound == PART_NONE) || (PartFound == PART_RESISTOR)) PartFound = PART_DIODE;	
			diodes[NumOfDiodes].Anode = HighPin;
			diodes[NumOfDiodes].Cathode = LowPin;
			diodes[NumOfDiodes].Voltage = (adcv[1]*54/11);	// multiply approx by 4.9 to obtain the voltage in millivolts from the ADC value
			NumOfDiodes++;
			for(uint8_t i=0;i<NumOfDiodes;i++) {
				if((diodes[i].Anode == LowPin) && (diodes[i].Cathode == HighPin)) {	//two antiparallel Diodes: defective or Dual LED
					if((adcv[3]*64) < (adcv[1] / 5)) {	// Forward voltage drops sharply(greatl) at lower Test current => defect component
						if(i<NumOfDiodes) {
							for(uint8_t j=i;j<(NumOfDiodes-1);j++) {
								diodes[j].Anode = diodes[j+1].Anode;
								diodes[j].Cathode = diodes[j+1].Cathode;
								diodes[j].Voltage = diodes[j+1].Voltage;
							}
						}
						NumOfDiodes -= 2;
					}
				}
			}
		}
	}

	testend:
	ADC_DDR = 0;
	ADC_PORT = 0;
	R_DDR = 0;
	R_PORT = 0;
}

//=========================================================================
void GetGateThresholdVoltage(void) {
	unsigned int tmpint = 0;
	unsigned int tmpintb = 0;

	uint8_t extcnt = 0;
	tmpval = (1<<(2*c) | (2<<(2*b)));
	tmpval2=(1<<(2*c));
	R_DDR = tmpval;        // Drain via R_L as output, Gate via R_H as output
	ADC_DDR=(1<<e)|(1<<b);	//Gate and Source as output
	if((PartFound==PART_FET) && (PartMode == PART_MODE_N_E_MOS)) {
		// measure Gate threshold voltage 
		ADC_PORT = 0;			//Gate and Source fixed to GND
		R_PORT = tmpval;  	   // Drain via R_L to Vcc, Gate via R_H to Vcc
		tmpval=(1<<c);
		_delay_ms(10);
		ADC_DDR=(1<<e);          // Charge Gate slowly via R_H
	
		while ((ADC_PIN&tmpval)) {  // wait until the MOSFET switches and drain goes low; loop lasts 7 cycles
			tmpint++;
			if(tmpint==0) {
				extcnt++;
				if(extcnt == 8) break; // Timeout for gate threshold voltage measurement
			}
		}
		
		R_PORT=tmpval2;          // switch Gate high impedance 
		R_DDR=tmpval2;          
		tmpintb=ReadADC(b);

	} else if((PartFound==PART_FET) && (PartMode == PART_MODE_P_E_MOS)) {
		ADC_PORT = (1<<e)|(1<<b);	// Gate and source fixed to Vcc
		R_PORT = 0;					//Drain via R_L to GND, Gate via R_H to GND
		tmpval=(1<<c);
		_delay_ms(10);
		ADC_DDR=(1<<e);          //  Gate as input
		ADC_PORT=(1<<e);          // charging the Gate slowly via R_H (Gate Pullup)
		while (!(ADC_PIN&tmpval)) {  // Wait until the MOSFET turns on and drain goes high
			tmpint++;
			if(tmpint==0) {
				extcnt++;
				if(extcnt == 8) break; // Timeout for gate threshold voltage measurement
			}
		}
		R_DDR=tmpval2;          // Gate Hi-Z
		tmpintb=ReadADC(b);

	}
	R_DDR = 0;
	R_PORT = 0;
	ADC_DDR = 0;
	ADC_PORT = 0;
	if((tmpint > 0) || (extcnt > 0)) {
		if(PartMode == PART_MODE_P_E_MOS) {
			tmpintb = 26666-tmpintb;
		}
		tmpintb=(tmpintb*39/8);
		utoa(tmpintb, outval, 10);
	}
}

//=========================================================================
	/* Connect one component pin briefly (10ms) to a specific potential
		This function is intended for Discharging MOSFET gates to be able to detect protection diodes etc
		Parameters:
		PinToDischarge: pin to be discharged
		DischargeDirection: 0 = against  GND (N-Kanal-FET), 1= against  Vcc(P-Kanal-FET)
	*/
void DischargePin(uint8_t PinToDischarge, uint8_t DischargeDirection) {
	uint8_t tmpval;
	tmpval = (PinToDischarge * 2);	// necessary because of the arrangement of the resistances

	if(DischargeDirection) R_PORT |= (1<<tmpval);	//if DischargeDirection = 1,  R_L pin to Vcc
	R_DDR |= (1<<tmpval);			//Pin as output (and via R_L to GND if DischargeDirection = 0)
	_delay_ms(10);
	R_DDR &= ~(1<<tmpval);			// Pin back to input
	if(DischargeDirection) R_PORT &= ~(1<<tmpval);	//R_L off
}

//====================================================================
uint16_t ReadADC(uint8_t ch){
	uint16_t adc;	// digital value

	// read digital value at input An @8SPS and Gain=2/3
	adc = ads1115_readADC_SingleEnded(ADS1115_ADDR_SDA, ch, DATARATE_8SPS, FSR_6_144);
	return adc;
}

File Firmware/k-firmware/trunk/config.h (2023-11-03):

/*########################################################################################
        Configuration
*/
#ifndef ADC_PORT
#if ((LCD_ST_TYPE == 7565) || (LCD_ST_TYPE == 1306) || (LCD_ST_TYPE == 7108) || (LCD_ST_TYPE == 8812) || (LCD_ST_TYPE == 8814) || (LCD_ST_TYPE == 7735) || (LCD_ST_TYPE == 9163) || (LCD_ST_TYPE == 9341))
  #define LCD_GRAPHIC_TYPE 1
#elif (LCD_ST_TYPE == 7920)
  #define LCD_GRAPHIC_TYPE 2
#else
  #define LCD_GRAPHIC_TYPE 0
#endif
#include "part_defs.h"
#include "lcd_defines.h"
//#define DebugOut 3		// if set, output of voltages of resistor measurements in row 2,3,4
//#define DebugOut 4		// if set, output of voltages of Diode measurement in row 3+4
//#define DebugOut 5		// if set, output of Transistor checks in row 2+3
//#define DebugOut 10		// if set, output of capacity measurements (ReadCapacity) in row 3+4 
//#define DebugOut 11		// if set, output of load time (ReadCapacity) in row 3 for C at pins 1+3

// defines for LCD_INTERFACE_MODE
#define MODE_PARALLEL 1		/* default 4-Bit parallel mode for character LCD */
				/* EN + RS + B4 + B5 + B6 + B7 */
#define MODE_I2C 2		/* I2C interface for SSD1306 */
				/* SCL + SDA */
#define MODE_3LINE 3		/* special 3 line serial output with Data/Command as first data bit  PCF8814 */
				/* RES + EN + B0 (+ CE) */
#define MODE_SPI 4		/* 4 bit SPI interface for ST7565 or SSD1306 */
				/* RES + EN + RS + B0 (+ CE) */
#define MODE_7920_SERIAL 5		/* serial interface for ST7920 */
				/* EN + B0 (+ RESET) */
#define MODE_7108_SERIAL 6		/* serial interface for ST7108 with shift register 74HC164 */
				/* EN + [RS B0] + CS1 + CS2 + CLK (+ PCLK) */
#define MODE_1803_SERIAL 7		/* serial interface for SSD1803 */
				/* EN + B0 (+ RESET) */
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

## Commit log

2023-09-08 Firmware 1.50-m on Arduino Uno
    Correct Readings of Resistors within 1%: 220, 330, 470, 1k, 2.2k,
    220k, 470k, 1M.
    Incorrect Readings of Resistors: 10 as 5, 100 as 50, 4.7k as 14k,
    10k as 4.2k, 22k as 9.9k, 47k as 21.5k, 100k as 44k
    [config.h, config_1280.h, config_328.h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]
2023-09-08 Flashlight and Power Light working now
2023-09-09 Using ADC_LARGE_BUFFER_CAP for Uno and text center align
    Arduino Uno has a bigger AREF cap of 100nF than what program
    demands of 1nF. In config.h turned on:
    define ADC_LARGE_BUFFER_CAP /* 100nF cap at AREF */
2023-09-09 Passive buzzer and Continuity Check now working
    [config.h]
2023-09-11 Added battery measurement, SH1106 display
2023-09-12 Moved Test Button to Port B, PB0
    As PC7 was having interference with neighbor pin AVCC
    and unable to turn LOW
    [config_644.h]
2023-09-12 Add note on Flash Procedure for new MCU and correct VREF V
    [config.h]
2023-09-19 Changed Logic Probe resistors & new Flashlight circuit
    Logic Probes now 47K and 220K
    Added a BJT and higher current LED, with separate pin
    than Buzzer
    [config.h, config_644.h]
2023-09-25 Measure USB Voltage on 1284p and backup
2023-09-26 Removed USB V Sense pin. Moved to ATMEGA 328 & Non Color Display
2023-09-30 Removed USBV voltage measure
2023-11-03 Working version on 328p PCB
    [battery_charger_calculations.xlsx]
2023-11-03 Renamed Arduino IDE project folder
    [battery_charger_calculations.xlsx]
2023-11-03 Added Eagle PCB Files
    [ComponentTester.brd, ComponentTester.sch, DRILEGEND.CFG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]
2023-11-03 Mounting Hole correction on PCB
    [ComponentTester.brd]
2023-11-09 PCB 3 Design
    [ComponentTester.brd, ComponentTester.sch, DRILEGEND.CFG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]
2023-12-01 Added VOUT measure and No Component Found Correction
    VOUT is Battery Boost voltage
    No Component string increased in size so that
    the question mark does not overwrite 't' of
    'No component' string.
    [config_328.h, main.c]
2023-12-02 Added Current Measurement Menu Item
2023-12-02 Improved Current Sense, Added auto detect USB
2023-12-07 Adding LiBatteryChargeBoostBoard PCB & Schematics
    [LiBatteryChargeBoostBoard.brd, LiBatteryChargeBoostBoard.sch, TPS2596xx_Design_Calculator.xlsm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]
2023-12-11 Ultimate Tester name & Power measure addition
2023-12-18 Adding LiBatteryChargeBoostBoard_v1_PCB
    [ComponentTester.brd, ComponentTester.sch, DRILEGEND.CFG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]
2023-12-18 Add BOM and Schematics to Ultimate Tester zip file
2024-01-20 Removed Lower limit on VOUT
    Not needed as added a separate 6V boost for
    Component Tester circuit
2024-12-26 Add Shunt Current Sensor INA226
2024-12-26 Simplify and correct Bit-Bang I2C Read and Write
2024-12-26 Power Meter: Clear only values and slow down update
2024-12-26 Power Meter: Reduce number of clears
2024-12-27 INA226 corrections, reduction in I2C file size, config changes
    [config.h, main.c]
2024-12-28 Power Meter improvements
2024-12-28 Reduce Power Meter flash usage
2024-12-28 Improved I2C
2024-12-28 I2C Improvements
2024-12-28 I2C BitBang Start, Repeated Start and Stop conditions improved
2024-12-28 new board config files
2024-12-30 Added External Power Symbol and Ext Pow/Batt voltage in Power Meter
2024-12-30 Add INA 226 Bus Voltage Offset Multiplier Calibrated Value
2024-12-30 INA226 Long Press to zero Current Value
2024-12-30 Add External Power font characters for 8x12 and 8x16 vpf fonts
2024-12-30 Use timeout in I2C.c file
2024-12-30 Change Menu First Line to Show Battery
2025-01-03 INA226 Power Meter: Make IOffset_local as static
2025-01-03 Revert I2C.c, Replace Repeated I2C Start with I2C Stop Start
    [config.h, config_328.h]
2025-01-03 Add README and pre-processor statements for TP_LOGIC and BAT_NONE in Power Monitor
2025-01-05 Add buzzer beeps when power crosses threshold
    [config.h]
2025-01-07 INA 226 default values for 100mOhm shunt and steps to calibrate module
2025-01-08 Modifications to INA226 calibration process and steps
2025-01-08 INA226 readme changes and more calibration step explanations
2025-01-08 Readme add power monitor accuracy
2025-01-08 Remove debug print statements from INA226.c
2025-01-18 Increase Logic Probe Resistors -> Voltmeter
    Usable range 0-55V now
2025-02-02 Add SSD1309 1.54 inch OLED I2C Display
    [UltimateTester_v1_with_mods.brd, UltimateTester_v1_with_mods.sch]
2025-02-23 Add averaging of INA226 samples
2025-03-08 Add 1284 config, config for External Power, Turn off Long Press Power Off
2025-03-08 Add INA3221 Power Monitor. Add HW_POWER_MONITOR flag
2025-03-09 Increase Power Monitor's Voltage Precision
    - Show 3 decimal places for voltage in Power Monitor instead of 2
    decimal places
    - Add POWER_MONITOR_AT_POWER_ON option in config.h, useful in
    development
2025-03-10 Correctly display 3 decimal digits for Voltage in Power Monitor
2025-06-28 Use SPI SH1107 Display and update INA3221 R to 40mOhm
2025-11-08 Save current configs - DIY 1284
2025-11-11 Config for Ultimate Tester v2 ^44PA and MP28167_A Driver
2025-11-11 MP28167_A I2C working now
2025-11-11 Set Buzzer and Flashlight as output whenever they are turned on
    [main.c]
2025-11-22 Add MP28167_A_BUCK_BOOST_CONVERTER output disable using mosfet
2025-11-23 MP28167_A - Set Min Vout as 1.2V for stability
2025-11-23 Display ILimit on Power Monitor
2025-11-23 disable Over Power Buzzer with MP28167_A
2025-11-23 Turn off buck boost converter at power off
2025-11-26 Reorder main menu, Buck Boost new R1 R2
2025-12-15 Add UltimateTester_v2.1 PCB, Schematics. Add About Page
    [BOM_UltimateTester_v2.1_UltimateTester_v2.1_2025-12-15.xlsx, Boost_n_EFuse_Resistors.xlsx, PickAndPlace_UltimateTester_v2.1_2025-12-15.xlsx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]
2025-12-27 Show TP2 at SQ Wave & PWM
2025-12-30 correction in Vout, Vref and Vref register val ranges
    [config.h, config_644.h]
2026-06-13 Add voltage conversion functions to MP28167_A
2026-06-13 Disable Buck Boost Converter when output V goes over desired V
2026-06-13 Power and ILIM rows always show
2026-06-13 Real time Power Supply Status at top right corner, on all screens
2026-06-13 Update battery status on Main Menu in realtime
2026-06-14 Adjust IOutLimMax and Iout of Powersupply in real time from any screen

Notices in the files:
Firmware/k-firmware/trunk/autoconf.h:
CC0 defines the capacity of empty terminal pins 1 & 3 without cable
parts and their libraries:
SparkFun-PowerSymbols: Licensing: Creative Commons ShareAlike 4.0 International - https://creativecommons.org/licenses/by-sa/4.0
